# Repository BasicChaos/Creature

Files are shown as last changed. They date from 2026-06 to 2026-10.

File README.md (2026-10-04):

# Creature

An experiment in building a small artificial organism, not an AI assistant.

Live dashboard: https://basicchaos.com/creature/index.html

<p align="center">
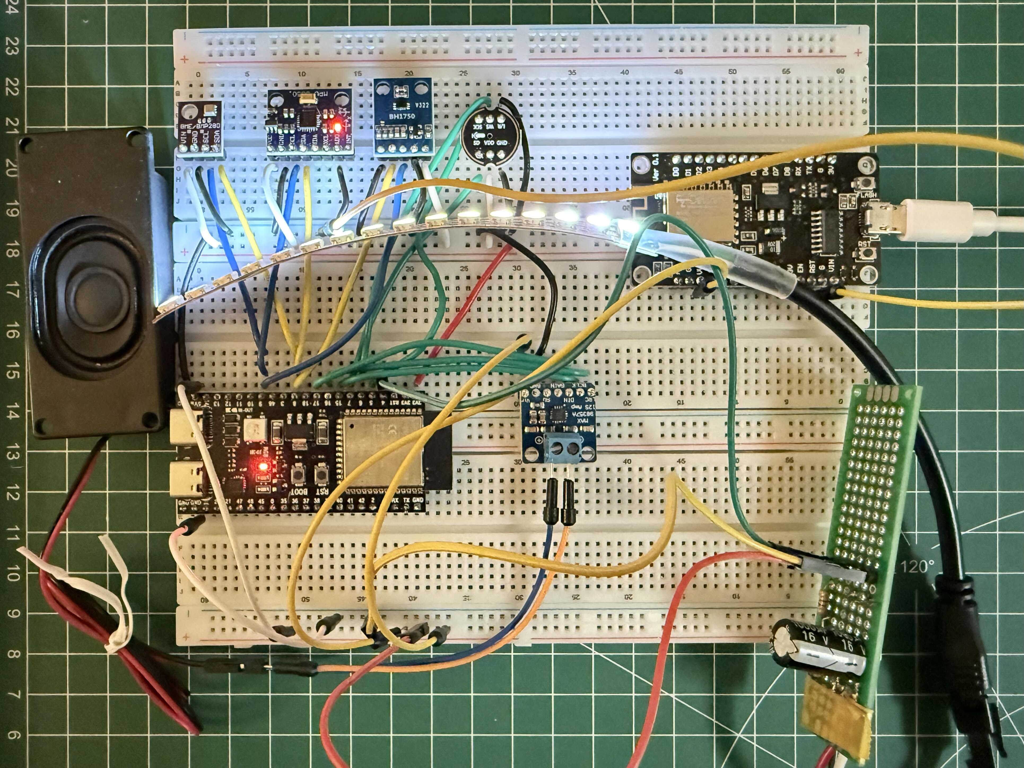
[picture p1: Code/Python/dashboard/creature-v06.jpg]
Creature v0.6

</p>

## What it is

Creature is a persistent entity that senses its room, builds internal state from
what it senses, expresses that state through light and sound, and carries its
history forward as it grows. It has no goals, no chat, no task to complete. The
point is the architecture, not intelligence.

The bet underneath the project: persistent pressure on a connected field of cells
grows stable structure over time, and that structure is the memory. The work is to
find out whether a small field can stay differentiated and alive instead of
decaying to a flat, even, quiet state. Entropy is the real enemy.

## How it works

The Creature has a body and a mind, and they are kept separate on purpose.

The body is an ESP32-S3. It reads its senses about ten times a second, streams one
JSON line per sample, and waits for commands telling its emitters what to do. It
stores nothing and decides nothing.

The mind runs on a Raspberry Pi. A single loop reads each sample, normalizes every
sense to a 0 to 1 value that adapts to the room, steps the cell field once a
second, reads the emitter cells back out, and sends the matching light and sound
frames to the body. It writes a live snapshot for the dashboard and a history row
to disk.

The loop is the current centerpiece. A light sensor is placed where it can see the
strip, and the microphone where it can hear the speaker, so the Creature's own
output returns as input. When it lights up, it sees its own light. When it sounds,
it hears itself. Action causes sensing. That is what lets it generate its own
activity instead of waiting for the room to hand it some.

## Hardware overview

Body node: ESP32-S3-DevKitC-1 style board (N16R8 module) on a breadboard.

Senses:

- BH1750 ambient light (I2C)
- INMP441 MEMS microphone (I2S)
- MPU-6050 / ICM-20689 motion (I2C)
- BME280 temperature and pressure, a slow sense with a real day-night rhythm (I2C)

On the body but not yet part of the Creature (v07.0):

- SCD41 CO2, temperature and humidity, and SGP41 VOC and NOx (I2C). Shown on the
  dashboard, with Sensirion's gas index worked out on the Pi.
- Waveshare 2.13inch e-paper (SPI). Shows the air readings and five of the
  Creature's own numbers, as text the Pi sends.

Emitters:

- SK6812 RGBW strip, about 16 pixels, the Creature's skin and face
- MAX98357A amplifier and a small speaker, its voice
- Onboard NeoPixel as a status pixel

Mind node: Raspberry Pi 3 B+. Runs the collector, the field, persistence, the
SQLite history, and the dashboard server. The Mac is only used for editing and
Git and is not part of the runtime.

Sensor API: the Pi's dashboard server (port 8080) also serves the raw sensors as
JSON at `/api/sensors` (light, sound, motion, temperature, pressure, and the air
readings: CO2, humidity, VOC and NOx), so other
apps and services can use the Creature as a set of ordinary sensors. Details in
`instructions.md`.

Observation surface: a Linux VPS hosts a static mirror of the dashboard at
basicchaos.com. The Pi only sends an outbound copy to it. The VPS cannot reach
back in. Full pin assignments, power, and wiring notes live in
`Hardware/Creature v06/WIRING v06.md`.

## Hardware evolutions

- v01: first schematic and layout, captured in KiCad.
- v05: ESP on a breadboard with the INMP441 microphone and BH1750 light sensor.
  The early photoresistor divider was retired.
- v06: added the BME280 weather sensor, the motion IMU, the MAX98357A amplifier
  with a speaker, and the SK6812 RGBW strip. The microphone moved to its own I2S
  peripheral so the mic and amplifier never share pins.
- v07.0: added the SCD41 and SGP41 air sensors on the same I2C bus and the
  e-paper readout on the ESP's free edge. Wiring is still in the v06 document.

Each version keeps its own schematic, wiring, and bench notes under `Hardware/`.

## Software evolutions

The mind is where most of the iteration happens. The body has stayed close to the
same on purpose so the field can change without rewriting hardware.

- Early experiments: an ESP32 light-novelty detector with Python collection.
- A 3-cell network of arousal, fatigue, and tonic state.
- An 11-cell ring.
- The 111-cell field (v05.4): a flat sheet of tissue with leaky-integrator cells,
  a shared energy metabolism, Hebbian learning with a scar floor, and triggered
  sleep and consolidation. It worked, but a big field of simple cells homogenizes.
  Adding cells only added more tissue to go uniform.
- v06: the current direction. The field shrank to a ring of twelve cells, with a
  six-cell fixed reservoir on the inside for temporal memory and a trained linear
  readout driving the two emitters. The cell changed from a leaky integrator to a
  predictive cell that reports surprise instead of raw input, so it stays
  differentiated under steady input. An expression decoder turns field state into
  strip color and voice.
- v06.5 / v06.6: an expression-as-memory layer. The Creature keeps an
  autobiography of what it expressed, and that graph can tell two different lives
  apart. A closed-loop dark-room probe showed the looped, curious Creature staying
  active in a silent, dark room where the same Creature without the loop goes flat.
- v06.7: the start of the predict cycle. Each tick the collector records what the
  body emitted next to what the raw sensors returned, and a small forward model
  predicts the Creature's own light and voice, compares, and learns. A probe tool
  measures how much of its output physically comes back. Passive so far: nothing
  feeds the field yet.
- v06.8: what counts as a significant event now reads surprise against the
  field's own running baseline, so sleep replays moments that stood out instead
  of its own background. The body listens while it speaks and reports what it
  heard at the pitch it played.
- v06.9: the loop reaches the field. How strongly the Creature just sensed its own
  voice or light, weighted by how wrong it was about it, presses on the two loop
  cells. When nothing has surprised it for a while it probes, with a lift in the
  strip's white and, rarely, a short tone at a pitch it knows least. The voice no
  longer runs as a metronome: it speaks when arousal stands clear of its own usual
  level just after something surprised it.

- v07.0: no change to the mind. The body gained air sensors and an e-paper
  readout; the Pi passes the air readings to the dashboard, works out a VOC and
  NOx index from them, keeps an hour of history, and sends the e-paper its text.
  None of it reaches the field.

The current version string is `v07.0-predictive`.

## Status

The v06 brain is validated in simulation. Every build step passed a reproducible
gate with a fixed seed: the ring shapes structure and survives a simulated night,
the reservoir distinguishes histories, the readout beats a direct connection, the
predictive cell does not flatten, and the dark-room loop self-sustains. The
expression-memory record layer is live in the runtime.

Since then the forward model, the felt loop and curiosity have gone live on the
real body (v06.7 to v06.9), and the sound loop is physically closed. Where things
stand now, what was found, and the open items are in
`Creature v07.0 Status and Next Steps.md`.

## Repository layout

```
Code/
  Firmware/esp-creature-core/   ESP32-S3 body (PlatformIO), 10 Hz JSON
  Firmware/bench/               per-sensor bring-up sketches
  Python/
    collector/                  the runtime loop on the Pi
    mind/                       the cell field, reservoir, predictive cell, decoder
    dashboard/                  server, page, static export, VPS sync
    tools/                      offline replay and gate harness
Hardware/                       KiCad schematics, wiring, bench notes, photos
```

## Documents

- `Creature Project Design Document Active.md`: the canonical design, current
  architecture in full.
- `Creature v07.0 Status and Next Steps.md`: what is running, what was found, and
  what is open.
- `Creature v06.md`: the v06 design rationale.
- `CREATURE_v06_SOFTWARE_RESULTS.md` and
  `CREATURE_v06_EXPRESSION_AND_LOOP_RESULTS.md`: the simulation results logs.
- `Creature v07 Hardware Potential.md`: the hardware roadmap.

## License

MIT. See `LICENSE`.

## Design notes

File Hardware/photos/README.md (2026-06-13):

# Build photos

Drop photos of the physical Creature build here (e.g. `breadboard-01.jpg`).

Reference them from `Hardware/wiring.md` like:

```markdown
![Breadboard build](photos/breadboard-01.jpg)
```

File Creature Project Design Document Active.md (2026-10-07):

Creature Project Design Document

Version: v07.0, October 4 2026
Status: current. This document matches the running code in Code/. It supersedes the
v05.4.1 edition, which described the 111-cell field, and the earlier editions that
described the 3-cell arousal/fatigue/tonic network and the 11-cell ring. Those were
real earlier stages. They are kept in git history and in the build-version notes.
The twelve-cell ring below is what runs today.

v07.0 is the v06.9 mind on a body with more on it: two air sensors and an e-paper
readout, added on 4 October 2026. Neither is part of the Creature's flow yet. The
field is unchanged, and the code files keep their `v06` names.

The longer theory notes, per-version build docs, and daily logs live in a local
Obsidian vault (`ObsidianCreature/`) that is not part of the public repository.
This document is the canonical, self-contained design.

---

Runtime note: all Creature services (collector, field, dashboard) run on the
Raspberry Pi 3 B+. The Mac is only used for editing and Git. The ESP32 is the body
and runs no logic.

## Purpose

Creature is an experiment in building a small artificial organism, not an AI
assistant. The goal is a persistent entity that senses the world, builds internal
state, expresses itself through a physical output, and carries its history forward
as it grows. The bet underneath the project: persistent pressure on a connected
field of cells grows stable structure over time, and that structure is the memory.

Current work is about architecture, not intelligence. The organism is meant to
start simple and gain complexity without replacing its core.

The Creature's one real enemy is entropy. Left alone in a steady room, a field of
simple cells decays toward a flat, even, quiet state. The earlier versions showed
it plainly: generic homogeneous connections, most of them lost overnight, arousal
surging on startup then settling toward zero. A bigger field did not fix it. Adding
cells only added more tissue to go uniform. v06 is built to pull the other way, and
everything in it serves that.

## How it works right now

The Creature has a body and a mind.

The body is an ESP32-S3 with four senses and two emitters, plus two air sensors and
an e-paper readout that the field does not use. It runs no logic. About
ten times a second it reads its senses and streams one JSON line per sample to the
Pi, and it waits for commands telling its emitters what to do.

The mind is on the Pi. One program, the collector, runs this loop:

1. Read a sample line from the ESP (light, sound, motion, weather).
2. Normalize each sense to a 0 to 1 value that adapts to the room.
3. Once per second, step the cell field on those values.
4. Read the emitter cells' activation back out through the decoder.
5. Send the matching strip and voice frames to the ESP.
6. Record what the body expressed into the autobiography.
7. Write a live snapshot for the dashboard and a history row to SQLite.

Beside that loop, and apart from the field, the collector passes the air readings
to the dashboard, works out a gas index from them, and every three minutes sends
the body ten short lines of text for its e-paper.

The field is the nervous system. It is a ring of twelve outer cells with a six-cell
reservoir on the inside. Senses come in at their anchors, the two emitters are
driven by cells that read the reservoir, and learning slowly reshapes the parts that
are allowed to change.

In one line: senses become pressure, pressure spreads through the ring, an inner
reservoir holds the recent past, predictive cells pass on surprise, and two cells
in the ring drive the light and the voice.

## Current hardware

Development machine: MacBook Air M1. Editing, Git, PlatformIO. Not in the runtime.

Runtime machine: Raspberry Pi 3 B+ (hostname creaturePi). Runs the collector, the
field, persistence, the SQLite history on the attached SSD, and the dashboard
server on port 8080.

Body node: ESP32-S3-DevKitC-1 style board. The module is marked N16R8.

Senses:

- BH1750 ambient light, I2C, address 0x23.
- INMP441 MEMS microphone, I2S0. The ESP computes a DC-removed RMS per sample.
- MPU-6050 / ICM-20689 motion, I2C, address 0x68, reduced to one motion scalar.
- BME280 temperature and pressure, I2C, address 0x76. A slow sense with a real
  day-night rhythm that stays nonzero at night, so the field has something to hold
  when light reads zero in the dark.
- SCD4x CO2, temperature and humidity (I2C, address 0x62) and SGP41 VOC and NOx
  (I2C, address 0x59), wired on 4 October 2026 on the same bus. The body streams
  them raw (`co2_ppm`, `air_temp_c`, `humidity_pct`, `voc_raw`, `nox_raw`) and the
  collector passes them to the dashboard's sensor panel and `/api/sensors`. The
  field does not read them. The CO2 sensor is an SCD41.
  The SGP41's counts are resistances, not concentrations (the VOC count falls
  with more gas, the NOx count rises), so the collector also works out
  Sensirion's gas index from them once a second: VOC 100 is this room's normal,
  NOx 1 is normal. The maths is `mind/gas_index.py`, a plain-Python port of
  Sensirion's C, checked against it by `tools/gas_index_check.py`. Its learned
  baseline is saved beside the field state (`..._air_v06.json`) and taken back
  at start if it is under 12 hours old. A row of air readings goes into the
  `air_log` table every 20 ticks, which feeds the last-hour lines on the sensor
  panel through `/api/air_history`.
- MAX17048 fuel gauge (I2C, address 0x36), wired on 6 October 2026 in line
  between the LiPo and the PowerBoost. The body reads it once a second and
  streams `battery_v`, `battery_pct` and `battery_rate` (percent per hour,
  negative while discharging). The gauge is powered by the cell, so the three
  keys drop out of the sample lines when the cell is out. The collector passes
  them to the sensor panel, `/api/sensors` and the e-paper, and writes a row to
  the `power_log` table every 20 ticks. The field does not read them yet: this
  is the first of three steps toward the battery setting the field's energy
  income.

Emitters:

- SK6812 RGBW strip, about 16 pixels, on GPIO 4 through a 470 ohm resistor. The
  field's skin and face. Driven by `PIX:` frames.
- MAX98357A amplifier and a small speaker, I2S1. The field's voice. Driven by
  optional `VOX:` tones: `VOX:freq,ms,vol`, and from the firmware of 7 October
  2026 four more numbers that may be left off, `attack_ms,release_ms,h2,h3`: how
  long the tone takes to rise and to die away, and how much of the second and
  third overtone is mixed in. Left off, it is the plain beep as before. The
  mind does not send them yet; `tools/voice_audition.py` does, to choose sounds
  by ear.
- Onboard NeoPixel on GPIO 38. A status pixel, driven by the legacy `LED:` command.
- Waveshare 2.13inch e-Paper HAT V4, SPI, on the ESP's free edge: DIN 1, CLK 2,
  CS 42, DC 41, RST 40, BUSY 39. A readout, not part of the field's expression.
  Driven by `EPD:` text: two columns of five short lines, which the collector
  composes every 180 ticks (air readings on the left, the Creature's energy,
  memory pressure, emitter, cell states and live links on the right; the battery
  takes the emitter's line when the body has a fuel gauge). The body
  only draws the text, in a task of its own so the sample loop never waits for a
  refresh, and answers with a `paper` line giving the refresh time.
  `CREATURE_PAPER=0` at the collector turns it off.

Sampling at about 10 Hz. One JSON line per sample over USB serial, and over a small
WiFi TCP server on port 7777 with mDNS when WiFi is configured. After each `VOX:`
tone the body also sends one `vox` line: what the mic heard while the tone played,
measured at the tone's own pitch, next to the same measure of the room just before. WiFi credentials are
kept out of git in an untracked `creature_wifi_secrets.h`. Full pin assignments,
power, and gotchas are in `Hardware/Creature v06/WIRING v06.md`.

External: a Linux VPS (basicchaos.com) that hosts a static mirror of the dashboard.
It only receives an outbound copy from the Pi. It cannot reach back in. The
deployment target is read from an untracked config file.

## Architecture

```
BH1750 (light) + INMP441 (sound) + IMU (motion) + BME280 (weather)
  [+ SCD41 and SGP41 (air), MAX17048 (battery): carried along, not read by the field]
  -> ESP32-S3 body, ~10 Hz JSON
  -> USB serial or WiFi TCP
  -> collector on the Pi
      -> rolling normalizers (raw -> 0..1, adaptive to the room)
      -> field.step(...) once per second
          -> twelve-cell ring (predictive cells)
          -> six-cell fixed reservoir
          -> trained readout -> two emitter cells
      -> expression decoder -> PIX: strip frame + VOX: tone
      -> autobiography record
      [-> gas index from the air readings; EPD: text for the e-paper]
  -> creature_state.json (live snapshot) + SQLite history
  -> dashboard server :8080  -> static export -> VPS mirror
```

The ESP is the body. The Pi is the mind. The VPS is an observation surface only.

## The cell field: a ring of twelve

File: `Code/Python/mind/cell_field_v06.py`. Version string `v06.9-predictive`. The
field steps once per second. Every constant assumes that 1 Hz tick.

The outer ring is twelve cells: six sense and emitter anchors alternating with six
in-between cells. The ring order is the design, because adjacency is what mixes. Two
rules set it: put correlated senses next to each other, and put each emitter next to
its own sense so the loop is built into the anatomy.

| Position | Anchor | In-between to next | What that cell is |
|---|---|---|---|
| 1 | Speaker (out) | Speaker x Sound | hears its own voice (loop)  |
| 2 | Sound (in) | Sound x Motion | sound and motion (paired) |
| 3 | Motion (in) | Motion x LED | movement drives light |
| 4 | LED strip (out) | LED x Light | sees its own light (loop) |
| 5 | Light (in) | Light x Weather | light and weather (paired)  |
| 6 | Weather (in) | Weather x Speaker  | the one weak gap |

Two of the six in-between cells are the loop made internal: the cell between the
speaker and the mic hears the Creature's own voice, the cell between the strip and
the light sensor sees its own light. Both correlated sense-pairs get a dedicated
cell. One gap, weather to speaker, is weak, the honest cost of closing a ring. The
two emitter anchors are the expression cells.

Why a ring and not a full mesh. A mesh connects every pair through its own cell, so
every in-between cell touches hardware on both ends. It is wide and shallow, a
switchboard with no interior, and depth has nowhere to live in a switchboard. The
ring keeps an interior, the reservoir, which is where signal history accumulates
without being tied to a single sensor.

Hold the field at twelve outer cells. Do not grow until the weights demonstrably
shape behavior and survive a night.

## The predictive cell

The outer ring cells are predictive cells, not leaky integrators. Each cell holds a
running prediction of its own drive and reports the error, the surprise, instead of
the raw input. A cell that predicts well goes quiet. A surprised cell speaks. This
is the negentropy engine in miniature: the cell builds a model and feeds on
surprise. The unit is prediction error, not a firing rate.

This is what fights entropy at the cell level. Under steady input the old leaky
field flattens: every cell's average activity collapses to one shared value, a
uniform wash. The predictive field holds many times that spread. On a realistic day
run its overall differentiation is about 0.44 against the leaky field's 0.15.

The homeostatic gain that the 111-cell field used was removed here, because that was
the part actively pulling every cell to one shared level. The predictive cell does
not need it.

One honest consequence. The predictive cell does not rescue the light-and-weather
side, and it should not. Slow steady signals are easy to predict, so a surprise cell
correctly goes quiet on them. Weather is meant to be a nonzero floor at night, not a
structure builder. Keeping that side alive is the closed loop's job, not the cell's.

## The reservoir

The six inner cells are a reservoir: a fixed recurrent substrate whose weights are
set once at init and never updated by learning. The outer in-between cells drive it.
It holds a time-delayed, high-dimensional echo of recent sensor history.

Why fixed weights. A learned reservoir homogenizes for the same reason the outer
field did: co-activation flattens everything toward the mean. Fixing the weights
removes that pressure from the interior. The richness comes from random sparse
connectivity, not from learning. The echo state property means any sufficiently
varied input history produces a distinguishable reservoir state.

Spectral radius. The reservoir's weight matrix must have a spectral radius below 1.0
for the echo state property to hold, so activity echoes without blowing up. A value
around 0.9 is a reasonable start. In the sweep the reservoir is healthy from 0.1 to
1.1 and breaks at 1.5. The spectral radius is the lever that matters, not the input
scale.

What it gives the Creature: temporal memory without weight explosion, cross-modal
mixing without proximity constraints, and a clean separation between the processing
layer (reservoir, fixed) and the learning layer (readout, adaptive). What it does
not give: it does not replace the loop. The loop is still the primary entropy
fighter. The reservoir just gives the emitters richer material to read.

## The emitter readout

The two emitter anchors (speaker, strip) are the only nodes whose outgoing weights
are trained. Each reads a learned linear combination of the reservoir state and
learns, by a running delta rule, which combination to express.

The reservoir read beats a direct connection to the emitter's ring neighbours. A
direct neighbour tap carries almost no information about either sense. The reservoir
gives the emitter a far richer drive.

The training target is the current sense the emitter should express, not the next
raw sense, because sound is random bursts and cannot be predicted. When the loop
closes, the same rule becomes real prediction, because the sense it confirms will be
the emitter's own returning output. The reservoir does not change. Only the readout
does.

## Metabolism

Cells draw from a finite shared energy reserve, then spend their own local energy to
sense, process, and learn. Quiet cells refill slowly. Active cells burn through
energy and build fatigue. When the field is mostly quiet, the reserve recovers. When
a lot is happening, energy gets scarce and the field is pushed toward rest.

Four cell states follow from energy and recent activity: active, resting, dormant,
deep_sleep. Quieter states update less often and refill more slowly. This is a
scheduler, not a mood.

The shared reserve was resized for a twelve-cell body, where most cells stay active,
unlike the mostly dormant 111-cell field. At the old sizing the reserve deadlocked
at zero and learning starved. The twelve-cell values are start 4.0, max 6.0, refill
0.6 per tick.

### The battery and the reserve

Built on 7 October 2026, behind `CREATURE_BATTERY_CEILING=1` (off by default).
The body's battery sets how much the shared reserve can hold. The collector
passes the last cell voltage the body reported into `field.step(battery_v=...)`
each tick, and the same to the twin. The field smooths it over about two
minutes and reads the ceiling from a three-point curve:

| Cell voltage | Reserve's ceiling | Running time left (7 October) |
|---|---|---|
| 3.80 V and above | whole | two thirds or more |
| 3.60 V | 43 % | about 4 hours |
| 3.45 V and below | 25 %, the floor | about 1 hour |

Straight lines between the points. With the setting off, or with no reading,
the ceiling is whole. A gap in the readings keeps the last voltage for ten
minutes before the ceiling goes back to whole.

Nothing else in the field changes. The cells are still refilled in full, so they
sense and learn as before. What a lower reserve does is dim the expression,
through the decoder's energy gate (full above 40 % of the reserve's maximum, so
the reserve falls from 3.80 V but the dimming begins near 3.60 V). Since this
build the gate also scales the whole strip frame, not only arousal: arousal
carries little of the strip's light, and without that the strip lost only 13 %
of its light when arousal halved. At the floor the strip is sent about 40 % of
its usual light and arousal is about half. The voice's volume is not touched;
the amp needs its digital level kept in a clean range.

The cell reads about 0.15 V higher on the charger, so plugging it in lifts the
ceiling within a couple of minutes, and pulling the charger lowers it the same
way. Below the mind's floor the body has its own reflex: it caps the strip at
3.40 V and sleeps at 3.30 V (see "Design philosophy").

Three designs failed first, and the limits come from them:

- Scaling the refill rate did nothing until income fell under what the cells
  draw (about a third of normal). Below that everything went at once:
  expression fully dark, a sleep every four minutes, and the links wiped (mean
  weight 0.33 to 0.02 in two hours).
- A ceiling with no floor is safe down to about 20 %. Under about 18 % the
  reserve sits at the low-energy sleep threshold, the field sleeps every 240
  ticks, and that much replay rewrites its links (mean weight 0.46 to 1.0 in two
  hours). The floor of a quarter keeps the reserve above that threshold. A
  drained Creature that rests and sleeps more is still wanted, but it needs a
  sleep that does not do this, which is its own piece of work.
- The ceiling first followed the gauge's percentage and ran on the Pi that way
  for a day. On the run to flat the percentage reached 5 % half-way through the
  cell's real running time and 2 % with four hours left, so the Creature sat at
  the floor for the second half of every charge.

The gate is `python tools/field_lab_v06.py --battery`: a scripted cell (4.00 V,
3.70, 3.52, 3.35, back to 4.00) with readings 20 mV either way and a minute with
none, control against variant. It passes 9/9 on seeds 1, 2, 3 and 7. In that
gate the field is open loop and stays identical to the control tick for tick. In
the collector's own loop on the scripted body the dimmer strip is sensed, so the
field's life differs a little: after 30 minutes the largest link gap was 0.010
and there were up to 6 % fewer events, with no sleeps.

## Learning and forgetting

Two changes accumulate in the trainable connection weights.

Hebbian growth: when two linked cells are co-active and under real pressure at the
same time, their link strengthens. Cells that fire together wire together. Learning
costs energy, so a starved field learns less.

Decay with a scar floor: every trainable link loses a little weight each tick, fast
for fresh unused links and slow for well-used ones. A link never falls to zero. It
rests at a small scar floor. A scarred link carries almost no learned drive, but
ripples still pass through it, so a strong later event can bring it back. Pruning is
demotion, not amputation.

The reservoir is exempt from all of this. Its weights are fixed by design.

### Two-speed links (built, off)

Built on 3 October 2026 as the first attempt to push the memory horizon out. Each
ring link also keeps a slow weight that follows the fast one with a time constant
of about a week (`SLOW_RATE`). With `SLOW_MIX` above zero the drive between
neighbours uses a mix of the two, and decay (waking decay and sleep's weakening)
pulls the fast weight toward the slow one instead of toward the floor.
`SOFT_CEILING` scales growth, waking and replayed, by the room left under `W_MAX`:
a link keeps all of its growth up to `CEILING_KNEE` and then less, down to none at
`W_MAX`. `SLOW_LEAK` lets the slow weight itself drift toward the floor, on a slower
clock. The defaults are `SLOW_MIX = 0.0`, `SOFT_CEILING = False`, `CEILING_KNEE = 0.0`
and `SLOW_LEAK = 0.0`,
and with them the field is exactly as it was: the history gate's control runs are
unchanged to the last digit. The slow weights are kept and saved either way.

A collector run can switch a setting on from its environment, without a change to
the code: `CREATURE_SLOW_MIX`, `CREATURE_SLOW_LEAK`, `CREATURE_SOFT_CEILING` (1 for
on) and `CREATURE_CEILING_KNEE`. Unset, each is off. The twin runs the same field
code, so it lives under the same setting, and the collector prints the setting when
it starts. Given this way a setting behaves exactly as it does under the lab's
`--set`.

A setting is judged with `--history --compare` against a saved control, on seeds
1, 2, 3 and 7. It passes only if all of these hold:

- the expression horizon is at least twice the control's. This is judged on
  recorded senses over 72 hours. On the synthetic day the control itself never
  converges, so there is no horizon there to double;
- the newborn still learns: the weights its drive uses move at least 70% as far
  as the control's in the first three hours;
- fewer links are railed at the end;
- its links can still weaken: with the elder in a still room for 60 hours, the
  level each link its life built rests on (the floor, or its slow weight) is the
  floor or lower at the end than a day in;
- `--forward`, `--events`, `--feel`, `--curious` and `--voice` still pass.

Five settings were run on 3 October 2026. The last passes every check that can be
decided: `SLOW_MIX=0.25`, `SOFT_CEILING=True`, `CEILING_KNEE=1.0`,
`SLOW_LEAK=4.13e-7` (about a month). It is still off in the code. Since 08:45 on
4 October 2026 it is on in the live Creature, switched from the collector's start
command, with a fresh twin beside it. All five have the same result on the horizon: on recorded senses it
goes from 25, 25, 54 and 24 hours to more than 72, which passes on three seeds and
cannot be said on the fourth, where the control's 54 hours would need a 108-hour
test and the recording holds 72.

| | mix 0.5, ceiling over the whole range | mix 0.25, the same ceiling, leak of a month | mix 0.25, leak, no ceiling | mix 0.25, leak, knee at 1.5 | mix 0.25, leak, knee at 1.0 |
|---|---|---|---|---|---|
| newborn learning | 40 to 43%: fails | 58 to 61%: fails | 74 to 78%: passes | 74 to 78%: passes | 74 to 78%: passes |
| railed links, synthetic | 0 against 4 | 0 against 4 | 0 or 1 against 4 | 0 against 4 | 0 against 4 |
| railed links, recorded senses | 3 against 5 | 1 against 5 | 5 against 5, all at exactly `W_MAX`: fails | 5 against 5, at 1.91 to 1.97: fails | 2 against 5: passes |
| links can weaken | fails | passes | passes | passes | passes |
| other gates | `--feel` fails one check on seed 1 | all pass | all pass | all pass | all pass |

Read the pass with these in mind. It is the fifth setting tried against one
72-hour recording and one saved field, so it is fitted to them to some degree. The
railed count is taken at a fixed line (within 0.1 of `W_MAX`) that cuts through a
cluster of links: over the test the variant's count moves between 2 and 5 and the
control's between 1 and 8, with means of 2.7 and 3.9. And the newborn does learn
less, about a quarter less movement in its first three hours, mostly because its
unused links no longer fall.

What was learned:

- Without the leak a link can never weaken. Decay pulls the fast weight toward
  the slow one and the slow one only follows the fast one, so nothing pulls the
  slow weight down. In a ten-day run (three busy days, then seven in a still
  room) the slow weights fell on 0 of 108 link-days and no link dropped below the
  0.20 it was born with. With the leak they fell on 67 of 108.
- The soft ceiling as written brakes growth across the whole range, not only near
  the top: at a weight of 1.0 growth is halved. On its own it cuts a newborn's
  growth to about 78% of the control's.
- Under two-speed links a newborn's unused links no longer fall toward the floor
  in its first hours (0.85 of weight movement in the control, 0.07 in the
  variants). They rest on a slow weight that is still near the 0.20 they were
  born with. That movement is part of what the learning check counts.
- The ceiling and the learning check pull against each other. With the ceiling,
  learning fails. Without it, on recorded senses five links sit at exactly
  `W_MAX`, more firmly railed than in the control.
- With the knee at 1.5 the top links stop sitting on the rail but settle just
  under it. On recorded senses the control's five railed links are one at the top
  and four at the floor; the variant's five are all near the top and none is at
  the floor. With the knee at 1.0 the brake starts earlier and the five settle at
  1.85 to 1.94, two of them inside the line. Learning is unchanged at 78%: a
  newborn's links stay under 1.0 in its first hours, so a knee there does not
  touch them.
- The horizon itself moves as intended in every setting: after 72 hours of
  recorded senses the elder and the newborn still express about 0.10 apart
  (0.085 with the knee at 1.0), against a noise gap of 0.007. How long the
  horizon really is has not been measured: it lies beyond the recording.

## Sleep and consolidation

The field sleeps when it is under-stimulated for a while, or when memory pressure is
high, or when the energy reserve runs low. During sleep it replays its most
significant recent events, re-touching the links those events ran through, and
demotes weak unused links toward the scar floor. Each replayed event is consumed so
one spike cannot dominate. Sleep is triggered consolidation, not a clock.

v06.6 fixed a real bug here: sleep was never triggering because the quiet-pressure
threshold that armed it was unreachable in the twelve-cell body. The threshold was
corrected so consolidation can fire as designed.

v06.8 fixed a second one of the same kind: what counts as a significant event. The
old rule put a fixed threshold on raw pressure, and the weather anchor's steady
pressure crossed it on every tick. Every tick was an event, the 80-slot buffer only
ever held the last 80 seconds, and since sleep arrives after a quiet stretch, sleep
replayed the quiet run-up to itself: the field's own background.

The rule now reads surprise, the unit the predictive cell already speaks. A tick is
an event when its most surprised cell is at least three times more surprised than
the field usually is, and above a small floor. Usual is a running median, so the
rule follows the body and the room instead of going stale. Sleep and waking change
the sense levels and surprise the cells without the world doing anything, so no
events are taken while asleep or for 30 ticks after. When the buffer is full it
lets go of the least significant event, not the oldest, so it holds what stood out
since the last sleep. The old rule is still there as `EVENT_MODEL = "pressure"` for
control runs.

On 260,000 ticks of the Creature's own recorded senses, replayed from its saved
state: events fell from every tick to about 12% of ticks, the share that coincide
with a real sense change rose from 42% to 83%, and the top cell moved from the
weather anchor (56%) to the sound anchor (83%). The weather-to-speaker gap, the one
link the ring design wants weak, fell from 0.63 to the scar floor. It had been held
up by the background replay. One honest cost: with no background to replay, a long
still night adds nothing, so structure thins overnight more than it used to (about
83% of the day's differentiation held in simulation, against a figure above 100%
that the old replay was manufacturing).

## Expression

File: `Code/Python/mind/expression_v06.py`. The field is read once per tick,
read-only, and four signals come out:

- Arousal: overall activation gated by energy. Drives a white glow and the voice
  volume.
- Balance: warm senses against cool senses. Drives strip color and voice pitch.
- Tempo: from ripple. Drives shimmer, a travelling pulse, and voice roughness.
- Spatial profile: along the sound-to-light axis. Drives per-pixel color, so the
  strip shows the field's own geography.

The body renders `PIX:` and `VOX:` lines and decides nothing. The preview tool,
`Code/Python/tools/expression_preview.py`, runs this map offline, renders the strip,
and synthesizes the voice. It proved the map reads the field correctly. It also
showed the field going quiet, which is the problem the loop and the reservoir exist
to answer.

Where the strip's colour comes from has two models, chosen by
`CREATURE_COLOUR_MODEL`. The default, `blend`, is the one above: a straight line
in RGB between a blue and an orange, placed by balance. On the body it read as
bright white. The W channel was not the cause (it sat near 9 of 255): blue and
orange are near opposites, so the middle of that line is grey-white (81, 84,
81), the field spends most of its time near the middle, and the glow, the pulse,
the shimmer and the event flash all add white.

`inner`, built on 7 October 2026, gives the whole strip one hue that the field's
reservoir pushes around the colour wheel. A fixed reading of the six reservoir
cells is taken against its own usual level; the hue turns one way while the
reading is above usual and back while it is below, at 1.5 degrees a tick for one
usual swing and never more than 4. Nothing is drawn by chance: the same life
gives the same colours. Along the strip the hue leans up to 50 degrees one way
where the warm senses are active and the other way at the cool ones. Brightness
still comes from each cell's activity. The pulse is a paler streak of the same
hue, an event flashes the opposite hue at its own place, the W channel is off
(a curiosity probe still lifts it), and the whole frame is at 0.6 of the
blend's scale. The hue is the decoder's own and is not saved: after a restart
it begins again at red.

A direct map from the reservoir's state to a hue was tried first. The six cells
mostly rise and fall together, so it gave two opposite colours with quick jumps
between them (up to 60 degrees in a tick).

The gate is `python tools/field_lab_v06.py --colour`, the same field read by
both models. It passes 9/9 on seeds 1, 2, 3 and 7: white on 0 % of lit pixels
against 24 %, all twelve twelfths of the wheel in near-equal shares against
three, 37 % of the light, and arousal, balance, tempo and the voice identical.
In the collector's own loop on the scripted body, where the strip's light
reaches the light sensor strongly, the changing colour is sensed: over 30
minutes there were 30 to 50 % more events than under the blend and the largest
link gap was 0.08, with the same tones and no sleeps.

What a tone sounds like has two palettes, chosen by `CREATURE_VOICE_PALETTE`.
The default, `beep`, is one plain sine with 10 ms fades, 220 to 440 Hz from
balance. A sweep of the real speaker on 7 October 2026 showed that range is its
weakest corner: it is 12 times louder at 476 Hz than at 300, 42 times at its
peak near 950 Hz, and within a factor of four from 470 to 1900 Hz.

`open`, built on 7 October 2026 from what Josh chose by ear with
`tools/voice_audition.py`, changes what a tone is and not when one is spoken:

- The note is one of five (450, 506, 562, 675, 750 Hz), placed by balance.
  Three higher notes (900, 1125, 1350 Hz) are reached only at the very top, and
  are played at volume 0.40 with no overtones, because the top of the range is
  piercing. The main notes are at 0.70.
- No beeps. A calm moment is a long swell (up to 450 ms to rise, 600 ms long), a
  busy one is shorter with a quicker rise and a longer tail.
- Two overtones are mixed in by where the strip's hue stands, so the tone's
  colour moves with the light's.
- Balance and tempo are read against the last 32 times it spoke, not as they
  come. It speaks when something surprises it, which is nearly always a warm,
  busy moment: read as they come, three tones in four were high and none was a
  swell. Among equals, how far arousal stood above usual decides.

The sound model follows: its eight pitch bands cover two octaves above 450 Hz
under this palette (bands learned over the other range are not carried over),
and it is told each tone's `level`, how much of a plain tone's strength a shaped
one has at its own pitch, since that is where the body listens. Curiosity's
probe tones become soft tones and keep under 800 Hz.

The gate is `python tools/field_lab_v06.py --palette`. It passes 9/9 on seeds
1, 2, 3 and 7: the same moments of speech, all five main notes in use, 6 to 8 %
of tones high, about 45 % long swells, and the sound model explaining 87 to 89 %
of its own voice. In the collector's own loop on the scripted body, an hour, the
field's life is close to the beep's (largest link gap 0.013).

When the voice speaks changed in v06.9. The old rule voiced a tone whenever arousal
was at or above 0.45. On the twelve-cell body that is true about half the time, so
with a 20-second minimum between tones the voice ran as a metronome: over 1.8 hours
on 2 October 2026 the live Creature sent 242 tones, 192 of them exactly at the
minimum spacing. It was the same kind of stale fixed threshold as the sleep and
event ones.

The voice now speaks when three things hold: arousal stands at least 0.20 above its
own usual level (a running median), something surprised the field in the last few
ticks, and arousal has come back down since it last spoke, so one rise gets one
tone. It never speaks while the field sleeps or in the 30 ticks after waking. The
pitch and length of the tone come from balance and tempo as before. On 260,000
ticks of the Creature's recorded senses that is about 20 tones an hour against 109,
with 1% of them at the minimum spacing against 67%. In a still room it is silent.
`CREATURE_VOICE_MARGIN` sets the 0.20; 0.30 gives about 13 an hour.
`CREATURE_VOICE_MODEL=fixed` brings the old rule back for control runs.

One consequence for the autobiography: its fourth dimension records whether the
body would voice a tone, so from v06.9 that bit is set far less often than in the
graph built so far.

## Expression as memory

File: `Code/Python/mind/expression_memory_v06.py`. This is the v06.5/v06.6 layer.

Each tick the Creature's own expression (arousal, balance, tempo, whether it voices)
becomes a point in a graph. Transitions between points are weighted, unused paths
decay. The graph is an autobiography. Two creatures that lived different days end up
with clearly different graphs, far enough apart that the graph is a usable identity,
while two days with different random seeds stay close. The graph encodes the life,
not the noise.

Three findings shaped the layer. On its own, letting the graph steer the next
expression turns it into memory but has no safe middle: a little habit sharpens
motifs, more habit collapses the Creature into one groove. A novelty drive fixes
that, but only if it is adaptive, firing where the Creature is worn in. Then a band
opens at moderate habit where motifs survive without collapse. That band is
temperament.

In the runtime today, only the record layer is live, behind `CREATURE_EXPR_MEMORY`
(default on). It is passive: it changes nothing about what the body does. It records
each tick, saves the autobiography alongside the field slow-state, reloads it on
start, and summarizes it in the dashboard snapshot under `expression_memory`. Bias
and novelty steering are deliberately not wired to the body yet. Steering needs a
decoder that renders from a steered signal, and that is a later increment.

## The loop

Place one light sensor where it can see the strip. Place the mic where it can hear
the speaker. Now the Creature's own output returns as input. When it lights up, it
sees its own light. When it sounds, it hears itself. Action causes sensing. This is
the move that lets the Creature generate its own activity instead of waiting for the
room to hand it some.

The ring already prepares this. The strip sits next to the light sensor, the speaker
next to the mic, so the loop exists in the body plan before it exists in the room.
The physical placement completes it.

Start the coupling loose. A tight loop runs away, the light driving the sensor
driving the light. Begin with the perceiving sensor weak or slightly off the
emitter's direct line, and let the coupling grow. The aim is a Creature that can
sustain itself, not one that screams into its own eye.

In simulation the loop works. With a curiosity drive that pokes when the Creature is
flat and eases off when it is active, a loose loop gain makes a relaxation
oscillator, bounded by construction yet never fully still. In a dark, silent room
the open-loop control goes flat (mean arousal about 0.008) while the looped, curious
Creature stays alive (about 0.20), restless (tail std about 0.06), and bounded
(steady-state max under 0.85), and its forward-model error falls to zero. Nothing in
the room caused any of it. The activity is self-generated and learned. One caution
from the same runs: a steady self-loop is as predictable as a steady room, so the
predictive field habituates to it and goes quiet unless the probe stays
unpredictable. Random bursts keep surprise alive.

## The loop record and forward model

Files: `Code/Python/mind/forward_model_v06.py`, the loop block in the collector,
and `Code/Python/tools/loop_probe.py`. This is the v06.7 layer, with the body's
own hearing added in v06.8. On its own it is passive: it watches, predicts and
learns. What it learns reaches the field in the next section.

The loop above only matters if the Creature can tell its own output from the room.
Three pieces make that measurable.

The loop probe measures the physical coupling. With the collector stopped, it
switches the strip between dark and known frames and reads the lux each one adds,
then sends known tones and compares the mic with the room just before. The answer
is a number: how many lux the strip adds at the sensor, how many times louder than
the room a tone is.

The loop record sets action next to return. Each tick the collector keeps what the
body emitted (the strip frame as four channel means, any tone's pitch, length and
volume) and the raw senses gathered while that frame was on the body (lux, mic
level and peak, motion). One row per tick goes to the `loop_log` table. These are
raw values, not the adaptive 0 to 1 ones, so this is also the raw history the
normalizer section asks for.

The forward model predicts the return. Each tick it predicts the change in lux
from the change in the strip frame, and the mic's rise above the room from the
tone it sent, compares that with what happened, and learns from the miss by a
delta rule. It works on changes, not levels, so the room's baseline drops out and
daylight is not mistaken for the strip. Every change in the room is split in two:
the part the Creature caused (the prediction) and the part it did not (the error).
A lamp switching on is error. Its own light, once learned, is not. The learned
weights persist alongside the field slow-state, and the live snapshot carries a
`loop` block that the dashboard shows under Loop.

From v06.8 the body listens while it speaks. `playTone` used to block the main loop
for the length of the tone, so nothing was measured while the speaker sounded. It
now reads the mic between writes to the amp and measures the stretch that is
certain to be inside the tone at the tone's own pitch, then sends one `vox` line
with that level and the room's level at the same pitch just before. The Creature
knows what pitch it played, so it can listen for exactly that and ignore the rest
of the room. The forward model's sound half uses the report when there is one. It
keeps one gain for each of eight bands of pitch across the voice's octave, because
the real speaker is far from even: measured on 2 October 2026 it peaks near 330 and
400 Hz, dips between them, and is weak below 300. Without the report it falls back
to how far the mic's peak rises after a tone, which a noisy room swamps.

It is behind `CREATURE_LOOP` (default on).

## The loop reaches the field

v06.9. Until here the forward model only watched. Now what it finds is felt.

Each tick the model also returns a `feel` value for each loop, 0 to 1: how strongly
the Creature just sensed its own output come back, weighted by how wrong it was
about it. A sensed echo always registers a little, 30% of its strength. The rest is
the share of it that was not predicted. The collector hands the two values to
`field.step(senses, loop=...)`, and they press on the two loop cells the ring was
drawn around: the voice on Speaker x Sound, the light on LED x Light. The pressure
is on the same scale as a sense at its anchor and starts a ripple the same way, so a
fully surprising echo lands like a loud sound.

Three things follow from that definition, and each is a check in the `--feel` gate.
A learned echo is felt faintly and a surprising one strongly: in simulation an
ordinary tone is felt at about 0.43, and the first tones through a covered speaker
at about 0.65. It then gets used to being covered, as the gain for that band drops.
A loop that does not physically exist is not felt at all: the light value is scaled
by how well the model has shown it can predict its own light, so the small random
weights a blind sensor leaves behind do not trickle into the cell. And it does not
run away: in the gate's run mean arousal is about 11% above the control, it voices no
more tones than the control, and it spends no more time at full arousal.

On the real body today the light loop is open, so only the voice is felt. The light
side is ready for the sensor to move: once the model can predict its own light, the
light sense is given the room alone (lux minus what the model credits to the strip)
and the strip's own light is felt at the loop cell instead.

It is behind `CREATURE_LOOP_FEEL` (default on). `LOOP_FEEL_GAIN = 0` in the field is
the control.

## Curiosity

File: `Code/Python/mind/curiosity_v06.py`. v06.9. This is the curiosity drive from
the dark-room probe, on the real body. There the probe was a number added to the
senses. Here it is something the Creature does, and what comes back is predicted by
the forward model and felt through the loop cells like any other echo.

Boredom is measured in the field's own terms: the number of ticks since its last
significant event. It is zero for the first 120, full after another 300, and back to
zero the moment anything surprises it, its own echo included.

Two probes. The light probe is a lift in white on every pixel, sized by boredom:
mostly faint, with an occasional larger burst so the predictive field cannot settle
into it. The voice probe is a short tone, kept rare: in a room where nothing else
happens it comes to roughly six probe tones an hour, never within 120 ticks of the
last tone. Its pitch comes from the band of its range it has tried least, or the one
it has recently been most wrong about, so it explores its voice instead of repeating
one note. The drive only proposes. Nothing goes out while the field sleeps, and no
tone goes out while the speaker is muted.

In simulation, alone in a still dark room (`--curious`): with no loop and no probes
nothing surprises it. With both, it tries all eight bands of its voice, comes to
explain about 70% of what it hears of itself, and each probe tone is felt. With a sensor that can see the strip it is livelier still, mean arousal about
0.30 against 0.10, and never pinned; hide the strip and the feeling fades within
fifteen minutes as the model stops crediting itself with the light.

An honest limit: on today's body the light probe comes back as nothing, because the
sensor cannot see the strip. It confirms that every time, and that is all it does
until the sensor moves. So the live effect of curiosity today is the voice probe.

It is behind `CREATURE_PROBE` (default on). `CREATURE_PROBE_VOICE=0` keeps the light
probe and drops the tone.

## The stance on going quiet

The field is built to stop reacting once nothing changes. That is correct for a
filter and wrong for a creature meant to stay alive. The project takes a position:
do not tune the Creature to silence. Let arousal persist. Let it stay restless, let
it stay bored in the way that drives it to act rather than the way that drops it to
zero. The loop gives it the means, the reservoir gives it history to act on, this
stance gives it the permission. In practice the energy gate must not be the dominant
voice. It can dim a truly drained Creature, but a healthy one in a dull room should
still hum, fidget, and probe through the loop.

## Persistence

`Code/Python/data/creature_field_state.json` holds only the slow state: trainable
connection weights (each link's fast weight and its slow one), reservoir weights, energy, fatigue, relevance, ages, and the
predictive cells' learned predictions. It is written periodically, on clean
shutdown, and via an atexit handler, and reloaded on boot. Fast values (activation,
ripple) are deliberately not saved, so the Creature wakes calm but keeps its slow
self. A snapshot whose shape does not match the current field is refused rather than
half-applied. The autobiography is persisted alongside it and reloaded the same way,
and so is the newborn twin's field. The gas index's learned baseline is saved the
same way, in a file of its own, and is only taken back if it is under 12 hours
old. The snapshot is at version 2, which added the
slow weights. A version 1 file loads with each slow weight set to the fast one.
Code from before version 2 refuses a version 2 file and starts the field fresh, so
copy the saved state aside before going back to older code.

## Normalization and the noise gate

File: `Code/Python/mind/normalize.py` and the response curve in the collector.

Each sense is turned into a 0 to 1 value by a rolling normalizer: an EMA smooth plus
a rolling min and max over a recent window, with a minimum-range guard so a flat
signal reads near zero. This is how the Creature habituates to its own room instead
of needing fixed calibration. Sound then passes a response curve with a floor, a
gain, and an exponent, so ambient hum gates out while real transients pass.

Known limit: the rolling normalizer reports where the current value sits inside its
recent range, not how loud the room is in absolute terms. The durable fix is to log
raw values so the normalizer can be calibrated against an absolute level.

## The replay harness

File: `Code/Python/tools/field_lab_v06.py`. Runs the field and the expression layer
offline against synthetic scenarios or recorded history, one gate per build step.
The matrix maths is plain Python, no numpy, so the numbers are identical on any
machine and the runs reproduce exactly. Every gate uses a fixed seed.

| Gate | What it proves | Command | Result |
|---|---|---|---|
| ring | ring shapes structure, survives a night | `--gate --set CELL_MODEL=leaky` | 6/7 |
| reservoir | distinguishes histories, echo state holds | `--reservoir` | 4/4 |
| readout | richer than a direct ring tap | `--readout` | 2/2 |
| predictive | no flattening under steady input | `--predictive` | 2/2 |
| record | an autobiography forms and tells two lives apart | `--exprmem` | 3/3 |
| bias | habit becomes memory, over-bias collapses | `--exprbias` | 2/2 |
| novelty | adaptive novelty opens a temperament band | `--exprnov` | 2/2 |
| dark-room | self-generated, bounded, learned activity | `--darkroom` | 5/5 |
| forward | learns its own light and voice, leaves the room to the room | `--forward` | 7/7 |
| events | surprise rule against the old pressure rule; `--replay` runs both on recorded senses | `--events` | 6/6 |
| feel | the loop is felt: faintly when predicted, strongly when not, not at all with no loop | `--feel` | 7/7 |
| curious | bored in a still dark room, it probes, explores its voice, and learns it | `--curious` | 9/9 |
| voice | the fixed threshold is a metronome; the relative rule speaks rarely, when surprised; `--replay` too | `--voice` | 6/6 |
| history | measures the memory horizon: how long a newborn field needs, on the same input, to become indistinguishable from an elder; changes nothing; `--replay` with `--state` runs it on recorded senses; `--compare` judges a variant against a saved control, including whether its links can still weaken in a still room | `--history` | 4/4 |
| twin | the Creature is the same with the newborn twin beside it, in the field and in the collector's own loop; the twin measures what the history gate measures | `--twin` | 6/6 |

The ring, reservoir and readout rows were measured before the predictive cell became
the default. Under today's defaults they read 4/7, 3/4 and 1/2 (the ring row's own
command, which sets the leaky cell, still gives 6/7). That is unchanged by v06.8 and
is an open item, not a result.

Rule: no tuning change ships without a control-versus-variant run. This is the
difference between "I think it is emerging" and "here is the control run."

## The newborn twin

File: `Code/Python/mind/twin_v06.py`. The collector runs a second field beside the
real one, behind `CREATURE_TWIN` (default on). The twin is born fresh. Each tick it
gets the same four senses as the real field and nothing else: no loop, and nothing
it does reaches the body. The gap between the two is how much the real field's
longer life shows. It is the history gate's measurement, running live.

- The twin must not change the Creature. The field draws its noise from Python's
  shared random stream, so the twin keeps a stream of its own and swaps it in for
  its step. It runs after the body has its commands, and a fault in it switches it
  off rather than stopping the collector. The `--twin` gate checks this in the
  field, and again in the collector's own loop with `tools/scripted_body.py`, which
  runs the collector on a scripted body and clock so two runs can be compared line
  for line.
- Both fields are read through decoders held to the fixed expression model, so the
  gap means the same as in the history gate whatever model the strip uses.
- Its field is saved next to the real one, in `creature_field_state_twin_v06.json`,
  whenever the real field is saved. It is an ordinary field state. Delete it and
  the twin starts again as a newborn at the next restart.
- The live snapshot carries a `twin` block: its age in ticks, its ring weights, and
  the gaps in arousal, balance, tempo and the largest link difference, each smoothed
  over about an hour. One row a minute goes to the `twin_log` table: the mean gaps
  over that minute and the link gap at its end. Averaged over an hour, those rows
  are the history gate's hourly figures.
- The real field feels its own voice and light through the loop and the twin does
  not, so on a body whose loop is closed the gap settles above zero. What is left
  once the twin has caught up is what the loop adds.
- Cost on the Pi 3: about 3.5 ms a tick, measured 3 October 2026.

## Dashboard

Served from the Pi on port 8080, mirrored to the VPS for remote viewing.

- `server.py`: standard-library HTTP server. Serves the page and JSON for the live
  field state and history.
- `index.html`: an SVG view of the ring and reservoir, polling once a second. Cells
  show activation, state, and relevance; links show weight, with scarred links drawn
  as ghosts. The cell inspector is always open (it follows the most active cell
  until one is hovered or pinned). A Sensors panel shows the raw readings, with
  temperature in both C and F. The reservoir is drawn from its real wiring, which
  the snapshot carries (`reservoir.w`, `reservoir.w_in`, `reservoir.input_cells`):
  every in-between ring cell into every reservoir cell, and the sparse one-way
  links between reservoir cells as arrows, coloured by sign. Clicking any cell
  pins it, lifts its own wires, dims the rest, and lists each weight in the
  inspector with what it carries this tick.
- Page layout: one screen with no scrolling. A collapsible menu on the left, the
  field always in the middle, and one chosen section beside it: cell inspector,
  raw data (sensors, all cells, system health), learning, legend, or metabolism
  (with the loop). Clicking a cell opens the inspector. "What is Creature?" and
  the hardware photo sit below the fold. On a narrow screen the menu becomes a
  row of tabs and the page stacks. A day / night / auto switch sits at the foot
  of the menu; auto follows the device's light or dark setting. All colours,
  including the field's, are defined once per mode in the stylesheet.
- Legend: built by `setV06Legend` in `index.html` and meant to name every mark the
  field can draw: cell colours and sizes, what fill, outline, the three rings and
  the glow mean, each kind of line, how selection changes the picture, and the
  status dot and counters in the top bar. When the drawing code changes
  (`buildV06`, `renderV06`, `applySelectionV06`), the legend changes with it.
- `learning.py`: reads the slow numbers that show whether it is predicting
  better, over a window of its own ticks (6 h, 24 h or 7 d): how much of its own
  light's effect the forward model explained, how far each heard tone was from
  the predicted one, average surprise across the ring, and the weight of each
  ring link. Served at `/api/learning` and drawn as the Learning panel; the
  static export writes the 24 h window. The readout weights and each cell's own
  prediction are not logged, so they have no history yet. Under the charts one
  line reports the newborn twin from the live snapshot: its age and its gaps in
  arousal, balance and links.
- Sensor API: `/api/sensors` and `/api/sensors/<name>` serve light, sound, motion,
  temperature, and pressure as stable, versioned JSON so other apps and services
  can treat the Creature as ordinary sensors. Since v07.0 they also serve CO2,
  humidity, the CO2 sensor's temperature, the raw VOC and NOx counts and the VOC
  and NOx index. Raw values come from a `sensors` block the collector adds to
  the live snapshot; missing sensors are `null`. See `instructions.md` for the
  contract. Raw history is in the `loop_log` table, and the air readings' in
  `air_log`. The battery's charge, voltage and charge rate are served the same
  way, with their history in `power_log` and `/api/power_history`.
- Sensor panel: under Raw data on the local dashboard, hidden on the public
  mirror. One tile per sensor. The air tiles carry a line of their last hour,
  read from `/api/air_history` (a row every 20 ticks). The two gas index tiles
  show the index, a word against the room's own normal (normal, raised, high;
  "warming up" for the first 45 samples) and the raw count underneath. A change
  The battery tile shows the charge, a word (charging, discharging, steady),
  the cell voltage and charge rate, and a line of its last six hours. A change
  to `server.py` needs the dashboard service restarted; the page alone does not.
- Speaker mute: a button in the local dashboard header (hidden on the public
  mirror) toggles `POST /api/speaker {"muted": bool}`. It creates or removes a
  flag file, `creature_speaker_muted`, next to the database. The collector skips
  `VOX:` commands while it exists, so the speaker is silent but the C0 cell and
  the field keep running unchanged. Mute persists across reboots.
- `export_static.py` and `sync_to_vps.sh`: export the live data to static files and
  rsync them to the VPS over SSH as a restricted user. The Pi is never exposed to
  the internet; it only makes outbound connections.

The dashboard is an output channel and a microscope. It is not part of sensing,
memory, or decision-making, and nothing that exists only for the dashboard should
shape field design.

## Repository structure

```
Creature/
  Code/
    Firmware/esp-creature-core/      ESP32-S3 body (PlatformIO)
      src/main.cpp                   four senses + two emitters, the air sensors
                                     and the e-paper, ~10 Hz JSON
    Firmware/bench/                  per-sensor bring-up sketches
    Python/
      collector/collector.py         the runtime loop on the Pi
      mind/cell_field_v06.py          the ring, reservoir, predictive cell, readout
      mind/expression_v06.py          the decoder (field -> PIX/VOX)
      mind/expression_memory_v06.py   the autobiography layer
      mind/forward_model_v06.py       predicts its own light and voice
      mind/curiosity_v06.py           probes when nothing has surprised it for a while
      mind/twin_v06.py                the newborn twin: a second field that only watches
      mind/normalize.py               rolling 0..1 normalization
      mind/gas_index.py               Sensirion's VOC and NOx index, for the dashboard only
      mind/cell_field.py              the retired 111-cell field, kept for reference
      dashboard/                      server.py, index.html, static export, sync
      tools/field_lab_v06.py          offline replay and gate harness
      tools/scripted_body.py          the collector on a scripted body and clock, repeatable
      tools/fake_body.py              a live stand-in for the ESP over TCP
      tools/gas_index_check.py        checks the gas index port against Sensirion's C
      tools/expression_preview.py     renders the decoder offline
      tools/loop_probe.py             measures the light and sound loops on the body
      data/                           SQLite history + field snapshot (gitignored)
  Hardware/                          KiCad schematics, wiring, bench notes, photos
  Archive/                           earlier experiments and versions (gitignored)
```

## Design philosophy

The ESP stays simple and stable: read sensors, stream raw values, receive commands,
drive outputs. Nothing more. It does not store memory, make decisions, or interpret
meaning. It may have body-level safety reflexes, because those protect hardware.

It has one, built on 7 October 2026: the low-battery reflex. It acts on the
cell's voltage, not on the gauge's percentage, which read 2 % with four hours of
running left. When the cell stays at or under 3.40 V for ten seconds the body
caps the strip's brightness (12 in place of 40), whatever frames it is sent,
until the cell is back above 3.50 V or charging. When it stays at or under
3.30 V for thirty seconds the body darkens the strip, draws "Battery low" on
the e-paper (the panel keeps its image with no power), and deep-sleeps. Every
five minutes it wakes for a moment, reads the gauge, and sleeps again unless the
cell is charging or at 3.60 V or more; then it boots as usual and the collector
reconnects by itself. With no reading from the gauge the reflex does nothing.
The levels come from the run to flat of 7 October: about 55 minutes were left at
3.4 V and 20 at 3.3 V, and nothing stopped the discharge until the cell's own
protection near 2.4 V. Deep sleep does not cut the power. The PowerBoost, the
strip's idle current and the sensors still draw from the cell, so the reflex
buys time and does not replace the charger. `BAT:<volts>` is a bench test: for
two minutes the reflex acts on that voltage, and a test sleep is two 20 second
steps.

The Pi holds everything that changes: normalization, the field, learning,
expression, persistence. This lets the senses and the output stay stable while the
mind iterates in Python.

The body should stay dumb. The mind should stay changeable. That split is what lets
the Creature evolve without rewriting hardware.

## Known limitations

- The loop is validated in simulation, not yet on hardware. The physical light and
  sound loops are the next real test, and the result the project most needs.
- The light loop is physically open. Measured with `loop_probe` on 2 October 2026
  in a 768 lux room: no strip frame, up to all four channels at the cap, added a
  measurable amount at the BH1750 (every frame within the 1.15 lux sensor noise).
  The sensor has to move or be shielded before the Creature can see its own light.
  The sound loop was inconclusive in the same run: the room was louder than the
  tones, and the body stopped streaming while it played one.
- The sound loop is physically closed. With the v06.8 firmware flashed on 2 October
  2026, the first tones near 400 Hz came back at 11,500 to 16,500 at their own
  pitch, against 200 to 2,000 for the room at that pitch just before. A tone near
  300 Hz came back much weaker (about 3,700 against 1,100), so the small speaker
  is far louder at the top of its range than the bottom.
- The light-and-weather side stays weak by design, because slow steady signals
  produce no surprise. Only the loop keeps that side alive.
- Bias and novelty steering are not wired to the body, so the live Creature records
  its autobiography but is not yet steered by it.
- The battery reaches the Creature only as dimmer light, and only when
  `CREATURE_BATTERY_CEILING=1`. A drained Creature does not rest or sleep more,
  and learning does not slow: both first attempts at that damaged the links
  (see "The battery and the reserve"). The voice is as loud at 10 % as at full.
- A steady self-loop is as predictable as a steady room, so the predictive field
  habituates to it unless the probe stays unpredictable.
- The air sensors and the e-paper (v07.0) sit on the body but outside the
  Creature. The field does not sense the air, and nothing it does reaches the
  panel except as numbers to read. Bringing the air in would be a design step
  with its own gate.
- The body's WiFi signal measured -89 to -95 dBm on 4 October 2026, weak enough
  to drop the link. The cause (antenna placement or the 3V3 rail) is not
  established. The loops have not been re-measured on the body since the air
  sensing and the panel were added.

## Roadmap

The lesson of v06 holds: the organism becomes more alive when action returns through
the world, not when the model grows more complicated. The hardware roadmap follows
from that. Detail is in `Creature v07 Hardware Potential.md`. The name v07.0 went
to the air senses and e-paper build of 4 October 2026, which is not on this list:
they are passive inputs and a readout, added because the parts were at hand. The
steps below are still the direction.

- Give v06 a body. Build a rigid carrier that fixes sensor and emitter placement, so
  the loop can be tuned from weak to strong physically instead of by luck.
- Characterize the existing loops. Measure that a known strip frame moves the light
  reading and a known tone moves the mic or the IMU.
- Battery as real metabolism. A LiPo, a load-sharing charger, and a MAX17048 fuel
  gauge on the existing I2C bus, so expression costs energy and feeding the Creature
  becomes a real event.
- Haptics before locomotion. A small vibration actuator the IMU can feel, a safe
  action-sense loop without wheels.
- Touch and skin. Capacitive pads as an event channel, so human contact becomes part
  of the body loop.

Keep the mind on the Pi. Moving the field to the ESP breaks the body/mind split,
kills iteration speed, and buys nothing. The field is a few percent of CPU at 1 Hz.

More ESPs as separate sense-bodies is the version of "more ESPs" worth doing, and
the firmware already supports it through the WiFi TCP bridge. Spatially separated
nodes streaming to one Pi mind is how spatial structure would form. That comes after
one richer single body shows structure that survives a night and a replay test.

Do not add cells, senses, or motors casually. Prove one part on the bench, prefer
closed loops over passive inputs, and prefer physical consequence over a richer
dashboard.

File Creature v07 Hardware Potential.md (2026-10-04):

# Creature v07 Hardware Potential

Version: v07 hardware potential, June 23 2026. Status: planning note.

Note, 4 October 2026: the build name v07.0 was given to something not planned
here. Two air sensors (SCD41, SGP41) and an e-paper readout went onto the v06
body that day. They are passive inputs and a display, outside the Creature's
flow, and they change none of the priorities below. The stages called v07A to
v07D further down are still plans.

This document collects hardware opportunities for the next several Creature
evolutions. It does not replace the v06 wiring document or the v06 rollout plan.
It is a map of what is worth trying, in what order, and why.

The short read: the Creature does not need a pile of new sensors yet. It needs
better anatomy. The strongest next hardware move is to make the existing v06
body physically coherent, close the light and sound loops deliberately, then add
real energy through a battery. After that, touch, haptics, proximity, and limited
movement become worthwhile.

## Starting Point

v06 already has the important shape:

- Four senses: BH1750 light, INMP441 sound, ICM-20689 motion, BME280 weather.
- Two emitters: SK6812 RGBW strip and MAX98357A speaker.
- ESP32-S3 body: read raw sensors, stream JSON, receive commands, render outputs.
- Raspberry Pi mind: normalize, step the field, persist state, send `PIX:` and
  `VOX:`.
- Twelve-cell ring plus fixed reservoir and predictive cells.

That means the hardware question is not "what can we add?" It is "what physical
couplings make the field less dependent on a lucky room?"

The current v06 goal still stands: action must become sensing. The strip should
return through the light sensor. The speaker should return through sound or body
motion. The body should have costs and constraints the field can feel.

## Design Rules

Use these rules before adding hardware:

1. Prefer closed loops over more passive inputs.
2. Prefer physical consequence over richer dashboards.
3. Keep the ESP dumb. It may have safety reflexes, but not cognition.
4. Add raw senses or render-only actuators; interpretation stays on the Pi.
5. Do not add new field anchors casually. Battery, haptics, touch, and proximity
   can often enter as modulation or event channels first.
6. Prove one part on the bench before integrating it into firmware.
7. Do not add locomotion until the body has power, proximity, contact, and a
   hard stop.

## Priority 0: Give v06 a Body

The current hardware is still a bench organism: separated organs on a breadboard.
That is perfect for bring-up, but weak for the loop. The first v07-ish hardware
move should be a small body carrier.

Build a rigid carrier that fixes:

- Strip position.
- BH1750 position and angle relative to the strip.
- Speaker position.
- INMP441 position and acoustic path relative to the speaker.
- IMU position on the body, not loose on the breadboard.
- BME280 position away from direct heat from the ESP, strip, and PowerBoost.
- PowerBoost, battery, and future fuel gauge placement.

Make the light sensor and mic mounts adjustable. The v06 loop should start loose:
slightly off-axis, partially shielded, or physically separated enough that it can
sustain activity without running away.

Useful body details:

- A small black or translucent light well between strip and BH1750.
- A movable flag or shutter to tune how much strip light reaches the sensor.
- A small speaker cavity or baffle.
- A mic tunnel with foam or a partial shield so room sound and self-sound can be
  tuned separately.
- Strain relief for the strip and speaker wires.
- A power switch on PowerBoost EN to GND.

Acceptance:

- A known `PIX:` frame causes a measurable, repeatable lux change.
- A known `VOX:` tone causes a measurable, repeatable mic or IMU response.
- Tapping or moving the body produces a motion response that is not just loose
  wiring.
- Sensor placement can be changed without rewiring.

## Priority 1: Characterize the Existing Loops

Before adding new parts, measure the two loops v06 already claims.

### Light Loop

Test:

- Send fixed strip frames: dark, dim blue, dim white, warm, cool, moving pulse.
- Log raw `light_lux` and normalized `light_norm`.
- Repeat at different BH1750 angles and distances.

Desired result:

- The BH1750 sees the strip reliably.
- Ambient room light does not completely swamp the strip.
- The coupling can be tuned from weak to strong physically.

Hardware idea:

- Add a small adjustable shield or tube around the BH1750.
- Consider a second light sensor only if the single BH1750 cannot both sense the
  room and see the strip. One sensor could face outward, one inward.

### Sound Loop

Update (27 Jun 2026): the firmware no longer uninstalls the mic during a tone. Mic
(I2S0) and amp (I2S1) are separate peripherals, so the mic stays live and the
creature hears itself while speaking. That direct "hear self while speaking"
feedback is now available, which is the start of the audio loop.

Good loop options:

- Let the mic hear the tail after the tone ends.
- Use the IMU as a body-conducted voice sensor: speaker vibration returns as
  motion.
- Add a small vibration/contact sensor near the speaker if the IMU is not
  sensitive enough.
- Use a second sound sensor later only if the single I2S path remains too
  constrained.

Desired result:

- `VOX:` output creates some returning signal without having to make the speaker
  loud.
- The returning signal is tunable by speaker mount, cavity, and mic placement.
- The Creature can be quiet in the room while still sensing its own voice.

## Priority 2: Battery as Real Metabolism

This is the strongest v07 hardware addition.

Use a single LiPo cell, PowerBoost/load-sharing charger path, and a MAX17048 fuel
gauge on the existing I2C bus. The fuel gauge reads raw cell voltage and state of
charge, then the ESP streams:

```json
{"battery_pct": 84.2, "battery_v": 4.05}
```

Why this matters:

- The field already has energy, rest, sleep, and learning cost.
- Right now that metabolism is simulated while the body has unlimited USB power.
- Battery makes scarcity physical.
- Expression becomes costly: strip brightness and voice are no longer free.
- Feeding the body by plugging it in becomes a real event.

Hardware:

- MAX17048 fuel gauge, I2C address `0x36`.
- Adafruit breakout: LiPo through its JST pass-through (either port) to the PowerBoost.
  VIN to 3V3. VIN only powers the I2C pull-ups; on the battery it would put ~4.2V on SDA/SCL.
- GND to common ground.
- SDA/SCL to GPIO 8/9.
- Protected LiPo cell or charger with undervoltage protection.
- PowerBoost EN switch for physical off.

Firmware:

- Add `ENABLE_BATTERY`.
- Stream `battery_pct` and `battery_v`.
- Add body-level safety reflexes:
  - Below warn threshold, cap strip brightness first.
  - Below critical threshold, stop outputs and deep-sleep the ESP.
  - Keep this on the body because it protects hardware.

Mind:

- Parse and log battery.
- Show it on the dashboard.
- Scale field energy income by state of charge.
- Optionally create a small event when charge drops sharply under load.

Acceptance:

- I2C scan sees `0x36` with the other v06 devices.
- Battery percent and voltage are stable and plausible.
- Unplugging power causes a gradual state-of-charge decline.
- Low charge makes the Creature dimmer, quieter, more restful, and more likely
  to sleep without corrupting slow state.

## Priority 3: Haptics Before Locomotion

Haptics are movement without the danger and complexity of mobility. They are a
very good fit for this Creature.

Candidate:

- DRV2605L haptic controller.
- I2C default address `0x5A`.
- Drives ERM vibration motors or LRA haptic actuators.

Why it fits:

- The Pi can send a render-only command such as `HAP:intensity,ms,effect`.
- The body vibrates.
- The IMU senses the vibration.
- That creates a physical action-sense loop without wheels.
- It gives the Creature a fidget, startle, shiver, purr, or pulse.

Important address note:

- DRV2605L default `0x5A` conflicts with the default MPR121 touch controller.
- If both are added, pick breakouts or address wiring that avoid the clash.

Protocol idea:

```text
HAP:effect,intensity,ms
```

Start simpler if needed:

```text
HAP:intensity,ms
```

Acceptance:

- A haptic command produces a visible IMU motion response.
- Different effects or durations produce distinguishable motion signatures.
- Haptic output does not brown out the ESP or corrupt I2C.
- Haptics can be disabled independently with an environment or compile flag.

## Priority 4: Touch and Skin

Touch is probably the next best sense after battery and haptics because it gives
the Creature contact with a person and a body boundary.

Candidate:

- MPR121 capacitive touch controller.
- 12 electrodes over I2C.
- Default address `0x5A`, configurable on many breakouts to `0x5B`, `0x5C`, or
  `0x5D`.

Possible skin:

- Copper tape pads under paper, fabric, acrylic, or thin printed shell.
- One pad near the light sensor.
- One pad near the speaker.
- Several along the strip.
- One "hold" pad near the body base.

How to feed the field:

- Start as an event channel, not a new anchor.
- Derive values such as `touch_any`, `touch_count`, `touch_region`, and
  `touch_delta`.
- Later, if touch proves central, add a dedicated ring anchor.

Why it matters:

- Touch has meaning at organism scale.
- It gives a non-room-dependent source of surprise.
- It lets human interaction become physical, not just observational.

Acceptance:

- Touch is stable across humidity and power states.
- Idle touch does not chatter.
- A hand, tap, or hold creates distinct event patterns.
- The field reacts without saturating or staying permanently aroused.

## Priority 5: Near-Field Presence

Presence is useful, but less important than battery, haptics, and touch.

Candidate options:

- VL53L1X time-of-flight distance sensor, I2C address `0x29`, roughly near-field
  to several meters depending on target and conditions.
- APDS9960 proximity, RGB color, ambient light, and gesture sensor. Useful if the
  Creature should sense color or near motion around the face.

Use cases:

- Someone approaches.
- Something blocks the Creature's face.
- The Creature can point a sensor head and tell whether the world changed.
- Strip color can be sensed as color, not only brightness, if using APDS9960.

How to feed the field:

- Start with a scalar `presence` or `distance_change`.
- Treat sudden approach as event pressure.
- Avoid making it a permanent fifth/sixth anchor until the v06 ring has proven it
  survives nights with the existing four senses.

Acceptance:

- Stable reading at the intended body scale.
- Room geometry does not keep it permanently high.
- Approach and retreat are distinguishable.
- It still works with the strip and speaker active.

## Priority 6: One Small Motor

Do not start with locomotion. Start with orientation.

Best first motor:

- One micro servo that moves a sensor, a light shield, a speaker baffle, or a
  small head.

Why:

- It creates action with consequence.
- It changes what the sensors read.
- It is easier to make safe than wheels.
- It lets the Creature probe the world without roaming.

Good first mechanisms:

- Light sensor eyelid/shutter.
- Strip-to-sensor coupling vane.
- Speaker baffle.
- Head pan with BH1750 or ToF.
- Tiny body rock that the IMU can feel.

Servo control:

- Direct PWM from an unused safe GPIO if only one servo is used.
- PCA9685 I2C servo driver later if multiple servos are used.
- Power servos from a separate 5V rail with common ground, not from the ESP 3V3.

Protocol idea:

```text
MOV:channel,position,speed
```

Acceptance:

- Motion changes at least one sensor reading.
- The IMU can distinguish self-motion from stillness.
- Servo current does not reset the ESP.
- Motion has physical limits and cannot grind.

## Later: Mobility

Actual locomotion should wait.

Requirements before wheels or tracks:

- Battery and fuel gauge working.
- Low-battery reflex working.
- Touch or bump sensing.
- Distance/proximity sensing.
- Hard power switch.
- Software command timeout.
- Slow speed limit.
- Physical test space.

Candidate:

- DRV8833 motor driver for two small DC gear motors or one stepper.

Why to wait:

- Locomotion changes risk class.
- It creates cable, power, collision, and runaway problems.
- A Creature that can shiver, turn its head, and sense touch is already embodied
  enough to learn from action.

## Candidate Hardware Summary

| Category | Candidate | Bus / pins | Why it matters | Priority |
|---|---|---|---|---|
| Body geometry | Chassis, baffles, shields | mechanical | Turns breadboard parts into anatomy | now |
| Battery | MAX17048 + LiPo + PowerBoost | I2C `0x36`, power | Makes metabolism physical | v07 |
| Haptics | DRV2605L + ERM/LRA | I2C `0x5A` | Safe movement loop through IMU | v07+ |
| Touch | MPR121 + copper pads | I2C `0x5A-0x5D` | Contact, holding, skin | v07+ |
| Presence | VL53L1X | I2C `0x29` | Approach/retreat, near world | later |
| Color/proximity | APDS9960 | I2C | Sees color/gesture/proximity | later |
| Orientation | Micro servo | PWM or PCA9685 | Moves sensor or body part | later |
| Locomotion | DRV8833 + gear motors | GPIO/PWM | Actual movement | much later |

## I2C Address Watchlist

Current v06 bus:

- BH1750: `0x23`
- BME280: `0x76`
- ICM-20689 / MPU family IMU: `0x68`
- SGP41: `0x59` (added 4 October 2026)
- SCD41: `0x62` (added 4 October 2026)
- Planned MAX17048: `0x36`

Possible additions:

- VL53L1X: `0x29`
- DRV2605L: `0x5A`
- MPR121: default `0x5A`, often configurable to `0x5B`, `0x5C`, `0x5D`

The main conflict to avoid is DRV2605L and MPR121 both at `0x5A`.

## Evolution Path

### v07A: Anatomy and Loops

- Build the body carrier.
- Stabilize sensor and emitter placement.
- Characterize the strip-to-light loop.
- Characterize the speaker-to-mic or speaker-to-IMU loop.
- Keep the field and firmware behavior otherwise unchanged.

Success:

- The Creature's own output reliably returns as input.
- Coupling can be tuned physically.
- Nights show self-sustained activity without runaway.

### v07B: Real Energy

- Add LiPo, PowerBoost/load-sharing path, MAX17048.
- Stream battery percentage and voltage.
- Add low-battery safety reflexes.
- Couple state of charge to field metabolism.

Success:

- Full charge feels different from low charge.
- Expression costs energy.
- Feeding the Creature changes behavior.

### v07C: Haptic Body

- Add DRV2605L and a small vibration actuator.
- Add `HAP:` rendering.
- Let the IMU feel self-vibration.

Success:

- The Creature can shiver or pulse.
- The field can sense the effect physically.
- Haptics become a safe motor primitive.

### v07D: Skin

- Add MPR121 and touch pads.
- Treat touch as event and contact state.

Success:

- Touch, hold, and release create distinct field events.
- Human interaction becomes part of the body loop.

### v08: Orientation

- Add one servo to move a sensor, baffle, eyelid, or head.
- Add `MOV:` rendering with limits.

Success:

- Movement changes sensing.
- The Creature can probe without locomotion.

### v09: Mobility, Maybe

- Only after power, proximity, touch/bump, and safety reflexes exist.
- Start extremely slow.

Success:

- Movement creates meaningful new sensor history without making the system unsafe
  or unobservable.

## First Build Recommendation

The best next build is:

1. Make a small adjustable body carrier.
2. Measure and tune the existing light and sound loops.
3. Add MAX17048 battery sensing.
4. Couple battery to metabolism.
5. Add haptic vibration and close that loop through the IMU.

That path keeps the Creature small, embodied, and testable. It also respects the
v06 lesson: the organism becomes more alive when action returns through the
world, not when the model grows more complicated.

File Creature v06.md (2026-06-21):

# Creature v06 — small field, real body, closed loop

Version: v06, June 14 2026. Status: design, canonical.

Supersedes the earlier v06 draft (the "more world" plan on the 111-cell field),
preserved in `Archive/Creature v06 (more world draft, superseded).md`. Pairs with
`Creature v06 — expression layer.md` (the decoder) and
`Creature v07 — power and metabolism.md` (battery, energy).

## The test this version has to pass

The creature's one real enemy is entropy. Left alone in a steady room, the field
decays toward a flat, even, quiet state. The runs showed it: generic homogeneous
connections, most connections lost overnight. The expression preview showed it
again, arousal surging on startup then settling toward zero. A bigger field did not
fix it. Adding cells only added more tissue to go uniform.

v06 is built to pull the other way. It does two things that fight entropy, and
everything else serves them.

First, it gives the creature its own source of disturbance: a closed loop. The
creature acts on the room and senses its own action. That is a gradient it makes
for itself, so it stops depending on the room being interesting. A creature that
can poke the world and feel the poke does not have to go quiet.

Second, it makes the body small enough that every part matters. Eighty idle cells
averaging into mush is entropy. Twelve cells where each one carries signal resists
it, because there is no dead tissue to homogenize.

If v06 does not deliver those two things, it is a prettier screensaver, and it
fails its own test. The rest of this document keeps them central.

## My read, plainly

It makes sense and it pulls away from entropy, on one condition: the loop is the
point, not a feature. If the strip and speaker only display the field while the
field still settles to quiet, we have added output to a dying signal. The loop, and
the choice to let the creature stay aroused instead of tuning it to silence, are
what make the claim true. Built that way, this is the most alive the project has
been. Built as more output on the old field, it is not.

## What changes from the earlier v06

The earlier v06 kept the 111-cell field and added senses to it. This one:

- Shrinks the field to 12 cells (the ring below). Adding cells was the wrong lever.
- Decouples output size from field size. A 16-pixel strip and a speaker are driven
  by a few cells through a decoder, not by one cell per pixel.
- Treats the closed loop as the centerpiece, not a later nicety.
- Commits to deeper cells as the next step, because a small field of simple cells
  homogenizes just like a big one, only faster to watch.
- Adds a reservoir computing layer in the 6 inner cells, replacing the earlier
  inner loop with a principled fixed-weight substrate.

What carries over: the senses and the strip hardware (wiring detail lives in the
archived draft and in v07), and the decoder (the expression-layer doc).

## The body

Four senses and two emitters on one ESP32-S3. The ESP stays dumb: read, stream,
receive commands, drive outputs. Nothing more.

Senses:

- Light: BH1750 lux, on the I2C bus.
- Sound: INMP441 RMS, on I2S.
- Motion: MPU-6050 reduced to one motion scalar, on I2C. Correlates with sound.
- Weather: BME280 temperature and pressure, on I2C. A slow sense with a real
  day-night rhythm that stays nonzero at night, so the field has something to hold
  when light reads zero in the dark.

Emitters:

- LED strip: SK6812 RGBW, about 16 pixels. The field's skin and face.
- Speaker: MAX98357A amplifier and a small speaker. The field's voice.

I2C addresses, strip power, the data-line resistor, and pin choices are unchanged
from the archived draft and the v07 hardware section. They do not need rethinking
here.

## The field: a ring of twelve

Six anchors and six in-between cells, in a ring. Six reservoir cells form an inner
ring. Hold it at twelve outer cells. Do not grow until the weights demonstrably
shape behavior and survive a night.

Why a ring and not a full mesh. A mesh connects every pair through its own cell, so
every in-between cell touches hardware on both ends. It is wide and shallow, a
switchboard with no interior, and depth has nowhere to live in a switchboard. The
ring keeps an interior — the reservoir — which is where signal history accumulates
without being tied to a single sensor.

The ring order is the design, because adjacency is what mixes. Two rules set it:
put correlated senses next to each other, and put each emitter next to its own
sense so the loop is built into the anatomy.

| Position | Anchor | In-between to next | What that cell is |
|---|---|---|---|
| 1 | Speaker (out) | Speaker × Sound | hears its own voice (loop)  |
| 2 | Sound (in) | Sound × Motion | sound and motion (paired) |
| 3 | Motion (in) | Motion × LED | movement drives light |
| 4 | LED strip (out) | LED × Light | sees its own light (loop) |
| 5 | Light (in) | Light × Weather | light and weather (paired)  |
| 6 | Weather (in) | Weather × Speaker  | the one weak gap |

Two of the six in-between cells are the loop made internal: the cell between the
speaker and the mic hears the creature's own voice, the cell between the strip and
the light sensor sees its own light. Both correlated sense-pairs (sound with motion,
light with weather) get a dedicated cell. One gap, weather to speaker, is weak, the
honest cost of closing a ring. Each anchor is one cell. The two emitter anchors are
the expression cells.

## Layout diagram

![[v06_ring_layout.svg]]

Outer ring: 6 sensor/emitter anchors alternating with 6 in-between cells. Orange
edges are the closed-loop paths. Blue inner ring: 6 reservoir cells with fixed
random weights. Dashed orange arrows: trained readout from reservoir to emitters.

## The reservoir (inner ring)

The six inner cells are a reservoir — not a ring of simple leaky integrators, but a
fixed recurrent substrate whose weights are set once at init and never updated by
Hebbian learning.

How it works. The outer in-between cells drive the reservoir as input. The reservoir
holds a time-delayed, high-dimensional echo of recent sensor history. The two
emitter anchors (Speaker, LED strip) are the only nodes whose outgoing weights are
trained. They read from the reservoir state and learn which linear combination to
express.

Why fixed weights. A Hebbian reservoir homogenizes for the same reason the outer
field did: co-activation flattens everything toward the mean. Fixing the reservoir
weights removes that pressure from the interior. The richness comes from the random
sparse connectivity, not from learning — the echo state property means any
sufficiently varied input history will produce a distinguishable reservoir state.
The emitters then train a simple linear readout on top of that state.

Spectral radius. The reservoir's weight matrix must have a spectral radius below 1.0
for the echo state property to hold — activity echoes without blowing up. A starting
value around 0.9 is a reasonable first guess. Too low and the reservoir damps out
before the emitters can read it. Too high and it diverges. This is a field_lab
parameter, easy to sweep.

Readout learning. The emitter weights can train via a running delta rule against the
prediction error: what the emitter expressed versus what the sensors subsequently
confirmed. This connects naturally to the predictive cell direction — the emitter
predicts, the loop closes, the error drives the update. The reservoir does not
change; only the readout does.

What this gives the creature. Temporal memory without weight explosion. Cross-modal
mixing without proximity constraints — an R-cell can simultaneously receive the echo
of sound from two steps ago and the current weather pressure, neither of which share
a direct edge on the outer ring. And a clear separation between the processing layer
(reservoir, fixed) and the learning layer (readout, adaptive), which makes the
system easier to reason about and debug.

What it does not give. It does not replace the closed loop. The loop is still the
primary entropy fighter — the reservoir just gives the emitters richer material to
read. A reservoir with no loop input is still a filter on room events. The loop is
what lets the creature generate its own activity.

## The deep cell (next, and load-bearing)

A field of twelve simple leaky integrators homogenizes the same way a field of a
hundred did. The reduction only pays off if each cell carries more. This is the next
build step and gets its own document, but v06 commits the direction now.

The leading candidate is a predictive cell. Each cell holds a small expectation of
its next input and passes on the error — the gap between what it expected and what
arrived. A cell that predicts well goes quiet. A cell that is surprised speaks. This
is the negentropy engine in miniature: the cell builds a model and feeds on
surprise. It also moves off copying a neuron, because the unit is prediction error,
not a firing rate.

The reservoir direction and the predictive cell direction are compatible. The outer
ring cells can be predictive (they have inputs to predict against) while the inner
reservoir cells stay fixed. The readout weights on the emitters train against
prediction error. All three layers — predictive outer ring, fixed reservoir,
adaptive readout — pull in the same direction: away from uniform quiet.

Two alternatives to settle in the next pass. An oscillator cell, where each cell is
a phase that entrains with neighbors, so the field keeps its own rhythms and never
fully flattens. And a reaction-diffusion cell, two coupled variables that grow
patterns on their own. All three share the one property the leaky integrator lacks:
they do not settle to a flat line by themselves.

## Expression

The decoder is specified in full in `Creature v06 — expression layer.md`. In short:
the field is read once per tick, read-only, and four signals come out. Arousal,
overall activation gated by energy, drives a white glow and the voice volume.
Balance, warm senses against cool senses, drives strip color and voice pitch. Tempo,
from ripple, drives shimmer, a travelling pulse, and voice roughness. The spatial
profile along the sound-to-light axis drives per-pixel color, so the strip shows the
field's own geography. The body renders `PIX:` and `VOX:` lines and decides nothing.

The preview tool, `Code/Python/tools/expression_preview.py`, already runs this map
offline, renders the strip, and synthesizes the voice. It proved the map reads the
field correctly. It also showed the field going quiet, which is the problem the loop
and the reservoir exist to answer.

## The loop (the centerpiece)

Place one light sensor where it can see the strip. Place the mic where it can hear
the speaker. Now the creature's own output returns as input. When it lights up, it
sees its own light. When it sounds, it hears itself. Action causes sensing. This is
the move that lets the creature generate its own activity instead of waiting for the
room to hand it some.

The ring already prepares this. The strip sits next to the light sensor, the speaker
next to the mic, so the loop exists in the body plan before it exists in the room.
The physical placement completes it.

Start the coupling loose. A tight loop can run away — the light driving the sensor
driving the light. Begin with the perceiving sensor weak, or slightly off the
emitter's direct line, and let the coupling grow. The aim is a creature that can
sustain itself, not one that screams into its own eye.

## The stance on going quiet

The field is built to stop reacting once nothing changes. That is correct for a
filter and wrong for a creature meant to stay alive. v06 takes a position: do not
tune the creature to silence. Let arousal persist. Let it stay restless, let it stay
bored in the way that drives it to act rather than the way that drops it to zero.
It should be allowed to stay alive. The loop gives it the means, the reservoir gives
it history to act on, this stance gives it the permission.

In practice that means the energy gate must not be the dominant voice. It can dim a
truly drained creature, but a healthy one in a dull room should still hum, fidget,
and probe through the loop. If the only thing keeping it active is the room, it is
not yet a creature.

## Build sequence

Each step is validated before the next.

1. Shrink the field to the twelve-cell outer ring, keeping the current leaky-integrator
   cell for now. Validate in field_lab that the ring runs, that the two correlated
   cells and the two loop cells carry above-baseline weight, and that structure
   survives a simulated night. Control versus variant, reproducible seed.
2. Add the six reservoir cells in the inner ring. Set weights randomly, fix the
   spectral radius below 1.0. Validate that the reservoir state is distinguishable
   across two different input histories. Sweep spectral radius in field_lab.
3. Wire readout weights from reservoir to the two emitters. Train via delta rule
   against prediction error. Validate that the emitter output tracks field state
   more richly than a direct connection from the outer ring.
4. Deepen the outer ring cells — swap the leaky integrator for the predictive cell.
   Validate that the field no longer flattens to uniform under steady input.
5. Add the senses and place them by the ring order. Validate that the cross-modal
   cells differentiate.
6. Wire the decoder into the collector behind `ENABLE_STRIP` and `ENABLE_VOICE`.
   Preview with the tool first, then on hardware.
7. Close the loop, loose. Add the strip-facing light sensor and the speaker-facing
   mic. Watch for self-sustained activity, and for runaway. Tighten slowly.
8. Run it for nights. Look for differentiation that survives, and for the creature
   doing something the wiring did not obviously predict.

## What v06 is not

- Not the 111-cell field. That is retired to history.
- Not the mesh. The ring holds.
- Not the grand memory roadmap, the vector store, concept graph, and dream layer.
  Still an abandoned branch, not a plan.
- No growth, mitosis, or death yet. The field stays at twelve until the deep cell
  and the loop prove out.

## How we will know it worked

The entropy test, made concrete. v06 succeeds if, after nights of running:

- The field stays differentiated instead of homogenizing. Distinct cells, distinct
  weights, not an even wash.
- Two creatures with different histories can be told apart.
- The creature stays active in a dull room, carried by its own loop, not flat.
- At least once, it does something its wiring did not obviously predict.

The first three are measurable now, in field_lab and on the dashboard. The fourth is
the one that matters and the hardest to fake. It is also the only real proof that
the thing is pulling away from entropy on its own.

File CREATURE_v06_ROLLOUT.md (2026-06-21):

# Creature v06 rollout plan

Version: v06 rollout, June 15 2026. Status: process doc.

Pairs with `Creature v06.md` (the design and the 8-step build sequence). That doc
says what to build. This doc says how to roll it out without building a costly bug.

## The one rule

Change one layer at a time. Validate it. Commit it. Tag it. Then move to the next.

Never edit software, hardware wiring, and firmware in the same sitting. If two
layers move together and something breaks, you cannot tell which one did it. That
is the bug that costs a weekend.

## Order

Three layers, in this order:

1. Software (the field, in simulation). Pure Python, no hardware risk. The novel and
   risky logic lives here. Prove it in `field_lab` before any wire moves.
2. Hardware bring-up (each sensor and emitter, one at a time). Confirm every part
   functions on the bench with a minimal test sketch, before the real firmware
   touches it.
3. Firmware integration (the full body, streaming, then the loop). Only after the
   field logic is proven and every part reads clean on its own.

Software first because it is where the design is unproven and where the AI tools can
iterate freely with zero physical cost. Hardware second because a sensor that lies to
you is the worst bug to chase through firmware. Firmware last because it only has
value once both sides of it are known good.

## Phase 0: freeze a baseline (do this first, once)

Before any v06 work, lock a known-good point you can always return to.

- Commit everything currently working. The repo has uncommitted deletes and new
  files right now. Clean that up first so the baseline is real.
- Tag it: `git tag v05-last-good` then `git push --tags`.
- Confirm you can check it out clean: `git stash` any junk, `git checkout v05-last-good`,
  see it run, then `git checkout main`.

If you cannot return to a working version on demand, you have no safety net, and
every later phase is riskier than it needs to be.

## Phase 1: software (the field, in simulation)

This phase is steps 1 to 4 of the v06 build sequence, all in `field_lab.py`. No
hardware. Each step gets its own validation gate and its own tag.

Gate after every step. Do not start the next step until the current one passes.

- 1.1 Shrink to the twelve-cell ring. Gate: ring runs, the two correlated cells and
  two loop cells carry above-baseline weight, structure survives a simulated night.
  Control versus variant, fixed seed. Tag `v06-1-ring`.
- 1.2 Add the six reservoir cells. Gate: reservoir state is distinguishable across
  two different input histories, spectral radius swept and a working value chosen.
  Tag `v06-2-reservoir`.
- 1.3 Wire readout weights to the two emitters, train via delta rule. Gate: emitter
  output tracks field state more richly than a direct outer-ring connection.
  Tag `v06-3-readout`.
- 1.4 Swap the leaky integrator for the predictive cell. Gate: field no longer
  flattens to uniform under steady input. Tag `v06-4-predictive`.

End of phase 1: the brain works in simulation. Nothing physical has moved. If the
entropy test fails here, it fails cheap, and you fix it before spending on hardware.

Keep `expression_preview.py` in the loop. It already runs the map offline. Use it as
your eyes on every gate above.

## Phase 2: hardware bring-up (one part at a time)

Goal: prove every sensor and emitter functions on its own, with the smallest
possible test firmware, before the real firmware exists. A part that fails here
fails in isolation, where it is obvious. The same failure inside the full firmware
looks like a logic bug and eats hours.

Process for each part:

- Flash a minimal single-purpose sketch that does nothing but exercise that one part.
- Read the result over serial.
- Confirm against the pass criterion below.
- Only then add the next part. Never bring up two parts in one sketch.

Start with an I2C scan. Three of the four senses sit on I2C. Run an I2C scanner
sketch and confirm you see the expected addresses before testing any single device:

- BH1750 light: address 0x23 (or 0x5C if ADDR is high).
- MPU-6050 motion: address 0x68.
- BME280 weather: address 0x76 (or 0x77).

If a device does not show on the scan, it is wiring or power, not code. Fix it here.
Do not write driver code against a device the bus cannot see.

### Sensors

- Light (BH1750, I2C). Pass: lux value changes when you cover and uncover the sensor.
  Reads roughly zero in the dark, climbs under a lamp.
- Sound (INMP441, I2S). Pass: RMS rises when you clap or talk, falls in a quiet room.
  This one is I2S, not I2C, so it will not appear on the I2C scan. Test it on its own.
- Motion (MPU-6050, I2C). Pass: the single motion scalar rises when you move or tap
  the board, settles when still.
- Weather (BME280, I2C). Pass: temperature reads a plausible room value, pressure
  reads a plausible absolute value, both nonzero and stable. This is the sense that
  must stay nonzero at night, so confirm it is genuinely reading, not stuck.

### Emitters

- LED strip (SK6812 RGBW, ~16 px). Pass: a test pattern lights every pixel, all four
  channels (R, G, B, W) show correctly, no dead or wrong-colour pixels. Confirm the
  data-line resistor and strip power are as the v07 hardware section specifies before
  driving it. Watch current draw if powering from the board.
- Speaker (MAX98357A amp + speaker). Pass: a test tone plays clean, volume responds
  to a commanded level, no constant hiss or distortion at rest.
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

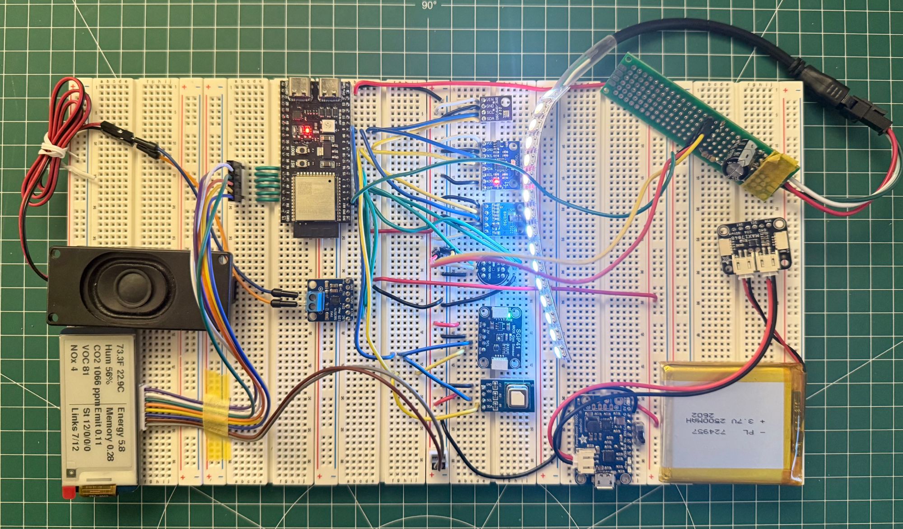
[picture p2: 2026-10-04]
Code/Python/dashboard/creature-v07.0.jpg

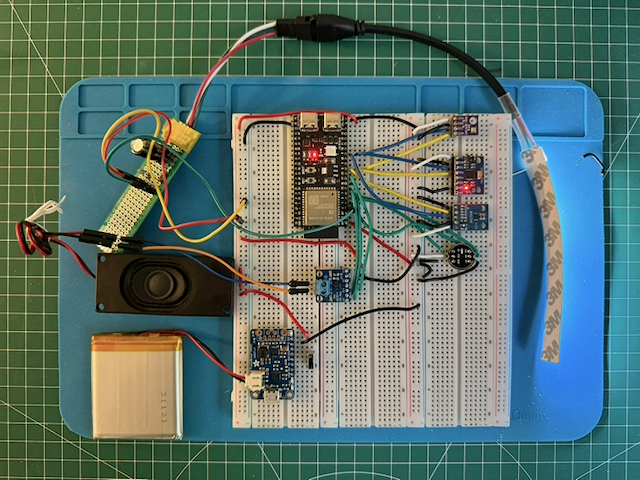
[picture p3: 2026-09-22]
Code/Python/dashboard/creature-v07-battery.png

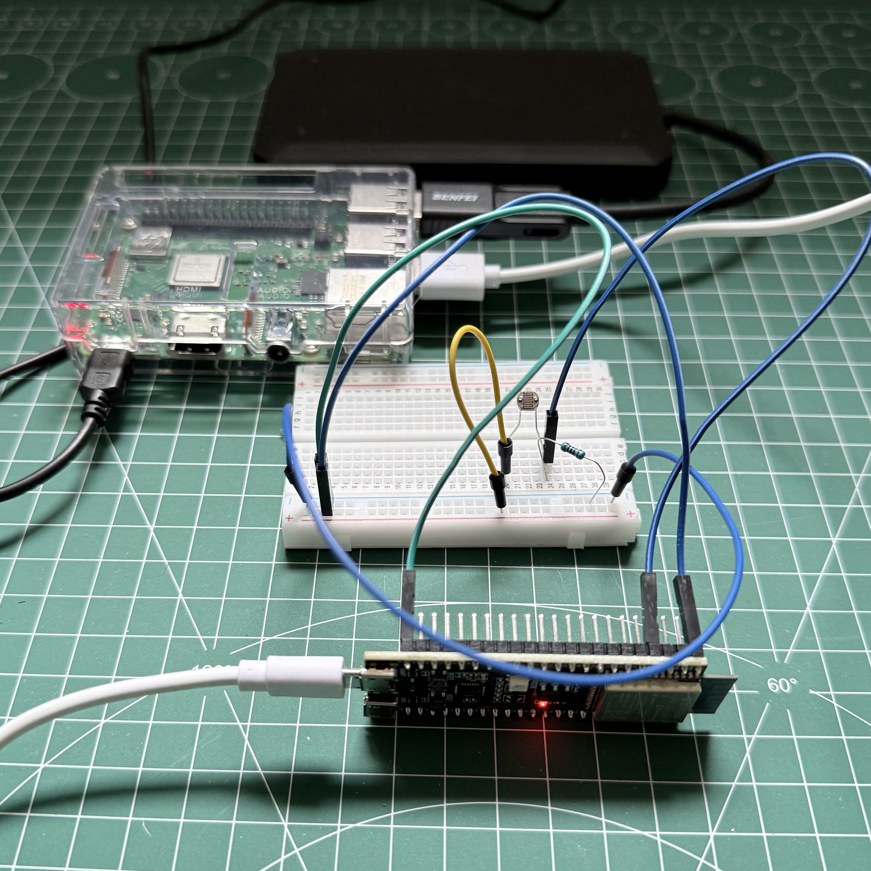
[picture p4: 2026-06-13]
Code/Python/dashboard/creature31may2026.jpg

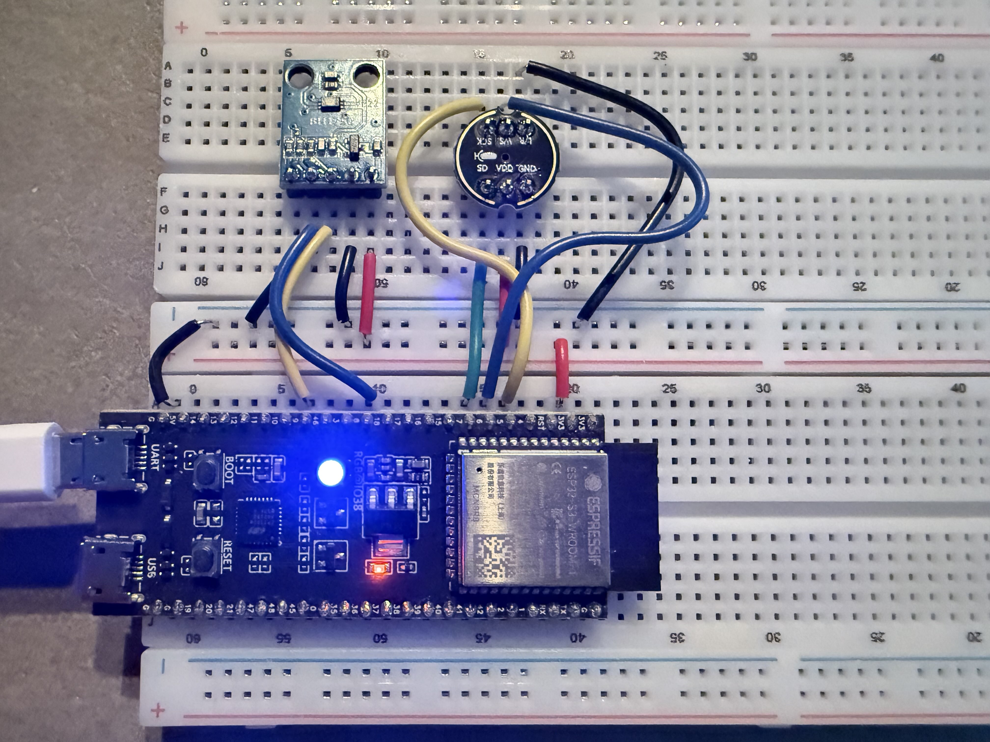
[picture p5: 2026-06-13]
Code/Python/dashboard/creature-v05-2.jpg

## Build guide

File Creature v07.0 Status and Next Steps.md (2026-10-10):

# Creature v07.0: status and next steps

Written 2 October 2026, updated 3 October for the dashboard work, 4 October for
the memory-horizon work, and the evening of 4 October for build v07.0. It is the
handoff for whoever picks this up next. The design itself is in
`Creature Project Design Document Active.md`. This note is the state of things,
what was found, and what is still open. The findings on the real body further down
are still those of 2 October. The newest section is the one for 8 and 9 October,
just below the list of where things are.

Build v07.0 is the v06.9 mind on a body with more on it: two air sensors and an
e-paper readout. Neither is part of the Creature's flow yet. The field, the
gates and the file names (`cell_field_v06.py` and the rest) are unchanged.

## Where things are right now (4 October 2026, 18:35)

- The Pi runs the collector from commit `59fc0fe`, restarted at 18:33 on
  4 October (state loaded from tick 962061). Any commit after that one is a
  correction to this note.
- The collector and the dashboard say `v07.0-predictive`. The body's firmware
  was flashed just before the label changed, so its boot line still says `v06`
  until the next flash. Nothing else differs.
- **Two-speed links are switched on in the live Creature**, from the collector's
  start command, not in the code. A plain restart turns them off. The start
  command is under "Deploying to the Pi" below. Check what is in force with the
  `Two-speed links:` line the collector prints at start, or in
  `/proc/<pid>/environ`.
- The relative expression model is also on, the same way
  (`CREATURE_EXPRESSION_MODEL=relative`).
- A newborn twin runs beside the real field. The present twin was born at the
  08:45 restart on 4 October (real tick 932373) and lives under two-speed links
  too. It was saved and reloaded across the day's restarts.
- The saved field is snapshot version 2. Code from before commit `93b3270`
  refuses it and would start the field fresh. State from before the switch is
  next to the database as `*.pre-twospeed.json` (version 1), and from before the
  twin as `*.pre-twin.json`.
- The body runs the v07.0 firmware, flashed at about 18:10 on 4 October: the
  v06.8 loop firmware plus the air senses, the e-paper, a 30 second WiFi retry
  and its signal strength in the status line.
- The gas index has a learned baseline, saved beside the field state as
  `creature_field_state_air_v06.json`. It began at 17:05 on 4 October.
- The body's WiFi was very weak that evening (see the v07.0 section). By 18:26 it
  was holding: pings of 3 to 6 ms and no reconnects for several minutes.
- The body runs on its battery when its power cable is out: on 4 October the
  battery ran flat at 07:08 and the body was off the network until 08:40. It
  needed the cable and a press of reset. The collector kept retrying and
  reconnected by itself; nothing was restarted for that.
- The speaker is unmuted.
- Check `git status` for anything not committed.

## The light loop is closed: the loop probe, rerun (9 October, 19:16)

The light half of `tools/loop_probe.py` was run on the real body (sound skipped).
The collector was down from 19:14:32 for about two and a half minutes and was
started again with the same eight settings (state loaded from tick 1345515). No
code changed. The report is next to the database as
`loop_probe_20261009_191631.json`.

| Frame (channel value) | Lux added, 9 October | Lux added, 3 October |
|---|---|---|
| white (200) | 240.0 | 0.9 |
| red (200) | 62.6 | 0.33 |
| green (200) | 137.8 | 0.55 |
| blue (200) | 36.5 | 0.08 |
| all four (200) | 410.9 | 1.54 |
| all four (100) | 214.8 | 0.81 |

- The room was at 149 lux with the strip dark, and the sensor's noise was 0.40
  lux. The strongest frame is 822 times the noise. On 3 October it was 22 times.
- The sensor sees the strip about 270 times more strongly than on 3 October.
  Josh: the strip sits at different distances from the sensor at different
  times, and on 9 October it was about 1 to 2 inches away. So the coupling is not
  a fixed number. Nothing may assume a distance; the light model has to keep
  learning it, and these lux figures hold only for this placement.
- Josh does not want the strip flashy in a dark room. As things stand the
  curiosity probe works against that: in a quiet room it lifts the white channel
  by up to 0.35 of the cap in bursts, which at this distance is about 80 lux at
  the sensor, and the inner colour model's 0.6 does not dim it.
- It is close to linear: half the value gives 0.52 of the lux.
- Per unit of channel value: white 1.2 lux, green 0.69, red 0.31, blue 0.18. Green
  counts nearly four times blue. So the inner colour model's turning hue already
  reaches the sensor as a change in brightness, at the same strip brightness.
- At full value the strip adds more light than the whole room (411 against 149
  lux). The room's light sense is therefore partly a reading of the strip itself.
  The swing of about 20 lux from tick to tick, noted on 2 October, is the size an
  ordinary frame would give.

This settles older open item 1 as far as the measurement goes, and makes item 7
due (the design doc and the dashboard legend still say the light loop is open).
Item 2, one weight per pixel for the light model, is now the main thing. Not yet
done: the same probe in a dark room.

## The body sat on a dead WiFi link until reset (10 October, 09:07 to 09:29)

The body went silent at 09:07:44 and stayed away for 22 minutes, until Josh
pressed reset. No ping from the Mac or the Pi in that time. The Pi and the
collector were fine and the collector reconnected by itself at 09:29:43.

What Josh saw before the reset:

- The repeater still listed the body (`esp32s3-85A690`, 192.168.178.91) as
  connected on 2.4 GHz, at the weakest signal step and 5 down / 14 up Mbit/s.
  Earlier that morning it had 26 / 70.
- The board's small light was blinking fast. That light follows the USB serial
  line: the firmware sends its 10 Hz samples there only while no collector is
  connected over WiFi. So the firmware was running normally and knew it had no
  collector.

Reading (not proven; the serial output was not watched): the body and the
repeater both believed they were connected, and nothing was getting through. The
firmware only rejoins WiFi when it sees the link as down (`WiFi.status() !=
WL_CONNECTED`), so it never tried. A reset makes it join afresh, which is why
that worked.

It is not the dark-room rule or anything on the Pi: the body could not be
pinged from the Mac either. Breaks like this are not new (the tick log has some
on every day of the week before), but 10 October had more, after changes to the
repeater's and the router's settings at 08:14 and 08:35 and the repeater
narrowing its 2.4 GHz channel at 08:23.

The Pi's move to the 2.4 GHz band was at 08:13:21, ten minutes before the
body's first break of the morning (08:23:32) and nine and a half before the
repeater narrowed its channel. It cannot have started the trouble: the breaks
at 23:53 and 23:57 the evening before, and those of the week before, came
first. Whether it made the morning worse is open. Since the move, the Pi, the
repeater's link to the router and the body all share the same 2.4 GHz channel.

Josh: this was not a problem before. The tick log agrees, and puts the change
at the v07.0 rebuild of 4 October, not at anything done on 9 or 10 October.
Breaks of 20 seconds to an hour, per day (planned restarts and flashes are in
these counts too):

| Days | Breaks a day | Minutes lost a day |
|---|---|---|
| 20 September to 3 October (12 days of running) | 0 to 2, once 5 | 0 to 14, once 63 |
| 4 to 9 October | 2 to 12 | 6 to 92 |
| 10 October, first 2.2 hours | 3 | 28 |

That is the day the air sensors and the e-paper went on, and the day the
body's WiFi was first measured as very weak (-89 to -95 dBm, see "Build v07.0"
below: the antenna lying flat over the breadboard, or the 3V3 rail feeding more
parts). It was never followed up. On 10 October the repeater showed the body at
its weakest signal step. So the weak link since the rebuild is the root, and
the router's re-tuning and the dead link are what a weak link does. The log
only covers June and from 20 September; June, on the earlier body, had breaks
of its own.

Next for this, in order: log the body's `wifi_rssi`, then move the antenna
clear of the breadboard and the panel and watch the number, then check the 3V3
rail.

The first is done (10 October). The collector now reads `wifi_rssi` from the
body's status line, which comes every two seconds. It is in the live snapshot
as `sensors.wifi_rssi` (dBm; empty when the last reading is over 10 seconds
old) and in a new `wifi_rssi` column of `power_log`, a row every 20 ticks.
Around -60 is good; under -85 is too weak to hold. The dashboard does not show
it yet. Nothing else changed: on the scripted body, seeds 1, 2, 3 and 7, a run
is identical to the code before, and `tools/scripted_body.py --wifi-rssi -70`
makes the scripted body send the status line.

Deployed at 09:48 on 10 October: the Pi runs commit `922b466`, the collector
restarted with the same nine settings (state loaded from tick 1370136, under a
minute down; state from before is `*.pre-rssi.json`). The first readings: -92
and -93 dBm. That is under the -85 the firmware's own note calls too weak to
hold a connection, and the same as the -93 to -95 measured on 4 October. To
read it: `sensors.wifi_rssi` in `/dev/shm/creature/creature_state.json`.

A fix on the body, not built: if the link reads as up but nothing has come
from the collector for a minute or two, rejoin WiFi; if that keeps failing,
restart. It needs a flash. With the Pi down for hours, as on the night before,
it would rejoin WiFi every couple of minutes, which is harmless.

## The Pi lost its WiFi overnight (10 October, 00:53 to 07:52)

The collector's last tick was logged at 00:53:18 on 10 October (tick 1364851),
and the public mirror's last sync was at 00:53:09. From then the Pi answered
neither ping nor ssh from the Mac, while the body still answered pings. Josh's
dashboard page said "server unreachable" (that is the page's own message when
it cannot fetch from the Pi). He rebooted the Pi at about 07:47. The collector
was started again at 07:52 in a new tmux session with the same nine settings
(state loaded from tick 1364800, saved at 00:52; about 50 ticks and seven hours
were lost).

What is known:

- The Pi did not crash or lose power. A systemd timer (`apt-daily-upgrade`) ran
  on it at 06:41, in the middle of the silence. It was running with no network.
- It did not get its WiFi back in seven hours, though the connection is set to
  reconnect by itself. That looks more like the WiFi chip or its driver hanging
  than like a signal that came and went.
- The Pi's WiFi link is weak: -77 dBm on the 5 GHz band (channel 44), sending
  at 12 Mbit/s, measured after the reboot. It is a Pi 3 B+ on WiFi only; the
  ethernet socket is unused.
- There were shorter breaks in the ticks before it: 2 minutes at 18:47 on
  9 October, 4 minutes at 23:53 and 10 minutes at 23:57. Whether those were the
  Pi's link or the body's is not known. The one at 18:47 was before the
  dark-room rule was switched on (20:07).
- The Pi reported under-voltage 18 seconds into the new boot
  (`throttled=0x50000`, `Undervoltage detected!` in the kernel log). Its power
  supply is marginal, at least while booting, with the SSD on its USB.
- The body's battery was fine (4.11 V, 90.7 %) up to the last reading.

What is not known: why the WiFi dropped at 00:53 and why it stayed down. The Pi
keeps its system log in memory only (`Storage=volatile`, the Raspberry Pi OS
default), so that night's log went with the reboot. The router's event log may
show something at 00:53.

The router's event log (FRITZ!Box 7590) has nothing between 21:03 on 9 October
and 07:58 on 10 October, so the router did not drop the Pi; the Pi went quiet
on its own side. A scan from the Pi on 10 October: the 2.4 GHz band reads 65 of
100 (channel 5, with a second access point at 59), the 5 GHz band it was using
reads 42. The body is 192.168.178.91 and the Pi 192.168.178.87.

Nothing points at the dark-room rule: it does not touch the network, and the
Pi itself kept running.

To be ready for the next time (each needs Josh, `sudo` asks for a password):

1. Keep the system log on disk, so the evidence survives a reboot. **Done by
   Josh on 10 October** (`/etc/systemd/journald.conf.d/50-persistent.conf`,
   `Storage=persistent`, at most 200 MB). After a silence, read the hours
   before it with `journalctl -b -1`.
2. Move the Pi onto an ethernet cable, or onto the 2.4 GHz band, which reaches
   further. **Done by Josh on 10 October at 08:13:21** (the Pi's log has it;
   it was back on the network six seconds later): the Pi's connection is
   set to the 2.4 GHz band (`802-11-wireless.band bg`). It reads -62 dBm and
   72 Mbit/s there, against -77 dBm and 12 Mbit/s on 5 GHz. The collector lost
   the body for a few seconds at the switch and reconnected by itself. To undo:
   `sudo nmcli connection modify 'netplan-wlan0-FRITZ!Box 7590 ST2'
   802-11-wireless.band ''`, then bring the connection up again.
3. A small watchdog that restarts the network when the router stops answering.
   It must not reboot the Pi: the collector is started by hand and would not
   come back.
4. A stronger power supply for the Pi.

The last snapshot before the silence, the first seen from a dark room: calm
1.0, the room read at 0.0 lux, the strip credited with 12.1 lux.

What the strip did in that first dark evening, from `loop_log` (the sum of the
four channels' mean values in each frame sent, in ten-minute steps). The room
went dark at about 20:10, three minutes after the rule was switched on, and
stayed dark to the silence at 00:53. Beside it, the dark part of the night
before (23:10 to 00:50 on 8 to 9 October), which had no rule:

| In the dark | 8 to 9 October, no rule | 9 to 10 October, rule |
|---|---|---|
| Strip value, usual | 46 to 70 | 15 to 27 |
| Strip value, highest | 68 to 174 | 30 to 56 |
| Change from tick to tick, usual | 1.1 to 2.2 | 0.25 to 0.6 |
| Change from tick to tick, biggest | 10 to 47 | 2.0 to 3.5 |
| White channel, highest mean | up to 22 | 0 (3 once, near the end) |
| Raw lux at the sensor | 13 to 24 | 2.7 to 8.9 |

In the lit evening before the dark (19:20 to 20:00 on 9 October) the usual
value was 73 to 85 and the biggest change 27 to 107, the same as the night
before. So on the real body the rule did what the gate said. Two limits: the
log holds each frame's channel means, not its pixels, so it cannot show single
pixels switching on and off; and the two nights were not the same room at the
same hours.

What the field did in that dark evening (20:10 to 00:53), from the log tables:

- It did not go quiet. Events on 11 to 17 % of ticks all evening, against 14 to
  16 % in the lit hour before. The room was not still: the sound sense was above
  zero on 14 to 31 % of ticks until midnight, and on 6 to 10 % after.
- Of 159 events, 105 were led by the sound cell (2) and none by the light cell
  (8) or the LED-and-light loop cell (7). In the lit hour before, the light
  cell led 42 of 84. In the dark of the night before, with no rule, the loop
  cell led 10 of 91.
- The light sense read exactly zero from 20:30 on, and felt light was zero on
  every tick. With no rule the night before, felt light was above zero on 16 to
  69 % of dark ticks (small: 0.017 at most on average). So in the dark the
  light loop is silent under the rule. That is the price the gate printed.
- One sleep, at 00:42, 29 ticks, for low stimulation, 4 links pruned. The night
  before had one like it at 22:55.
- The links held: mean weight 1.173 at the start and 1.181 at the end (it
  dipped to 1.094 on the way). The night before they fell from 1.120 to 1.063.
- Energy stayed at 5.8, tones ran at about 25 an hour until midnight and 17
  after. Curiosity proposed 13 light probes after 00:30 as things got quieter;
  none showed on the strip.

So the gate's price (a still dark room becomes a silent hour) was not tested:
there was sound in the room all evening. A still, dark, empty room under the
rule has not been seen yet. The two nights also differ in energy (about 2 on
8 October, 5.8 on 9 October) and the speaker made no tones on the 8th.

The body went off the network at 08:23:29 on 10 October (no ping from the Mac
or the Pi; the collector prints `Reconnect failed`). Its battery read 4.12 V and
91.5 % on the last sample. It came back by itself: ticks stopped from 08:23:32
to 08:27:54 (262 seconds) and again from 08:28:26 to 08:29:47 (81 seconds), and
the collector reconnected each time with nothing restarted. The first break is
the same length as the one at 23:53 the evening before (261 seconds), which
suggests that one was the body too.

The router's log explains this morning's: the repeater, which the body is
joined to, narrowed its 2.4 GHz channel at 08:22:49 and again at 08:23:24
("Wi-Fi transmission quality increased by reduced channel bandwidth"), five
seconds before the body went. Josh had changed the repeater's settings at
08:14. So the repeater dropped the body, not the other way round. What is the
body's own is how long it takes to get back: about four and a half minutes,
both times. Its firmware gives up a join after 30 seconds and starts again
(`WIFI_RETRY_INTERVAL_MS`, `WiFi.disconnect()` then `WiFi.begin()`); with its
weak signal a join may need longer than that, so it may be cutting its own
attempts short. That is a guess until the serial output is watched during a
drop. The router's log shows nothing at 23:53 the evening before.

## A calm strip in a dark room: switched on at the Pi (9 October, 20:07)

Josh does not want the strip flashy in a dark room. `mind/calm_v06.py` (new) is
a rule for that: the darker the room, the dimmer and slower the strip. The
collector applies it when started with `CREATURE_DARK_CALM=1`. It is off by
default.

**It is on at the Pi.** The Pi runs commit `6098dfd`. The collector was
restarted at 20:07 on 9 October with nine settings, the eight from before plus
`CREATURE_DARK_CALM=1` (state loaded from tick 1348495, under a minute down).
State from before the restart is next to the database as `*.pre-calm.json`. To
go back, restart without the setting.

The first minutes on the real body, in a lit room: the rule read the room at
127 to 136 lux and credited the strip with 8 to 17 lux, which adds up to the
raw reading (136 to 162). Calm stayed at 0, so the strip was untouched. **It
has not yet been seen in a dark room.** Read it with the `calm` block of
`/dev/shm/creature/creature_state.json`.

What the rule does:

- It works out the room's own light level. Dark is 3 lux or under, lit is 40 or
  over, judged on a log scale in between.
- In a dark room each frame is shown at 0.35 of its brightness, and the strip
  moves only 0.12 of the way to each new frame per tick. That takes the probe's
  white bursts, the event flash, the shimmer and the pulse down with it.
- In a lit room the frame goes out untouched, the very same numbers.
- Going dark takes hold within about 7 ticks. Coming back takes a little over a
  minute, then eases in over 20 ticks.

How it knows the room is dark with the strip beside the sensor. It learns, from
how the lux reading moves as the frame changes from tick to tick, how much the
sensor sees of the strip (the whole of it, and each quarter), and takes that
light out. It assumes no distance. It counts the strip's light in the steps the
body really shows (the firmware's cap of 40 means a value under 7 shows
nothing). Nothing of it is saved; after a restart it learns again.

`tools/field_lab_v06.py --dark` is the gate: a lit hour, a dark still hour, a
dark busy hour, the light back on; rule against no rule; the strip at three
distances (as on 3 October, as on 9 October, and twice as near again). 15/15 on
seeds 1, 2, 3 and 7. At the distance of 9 October, seed 1, in the body's
brightness steps summed over the strip:

| | No rule | Rule |
|---|---|---|
| Dark and still: strip light | 167.3 | 3.7 |
| Dark and still: biggest change of the strip in one tick | 100 | 16 |
| Dark and busy: strip light | 181.6 | 62.5 |
| Dark and busy: biggest change of the strip in one tick | 148 | 15 |
| Dark and busy: usual change from tick to tick | 9.05 | 1.77 |

The collector on the scripted body (`tools/scripted_body.py`, which gained
`--dark-after N`: the room's light goes out after N seconds), with the Pi's
eight settings, seeds 1, 2, 3 and 7:

- Rule off: everything the Creature did is identical to the committed code
  (commands, every log table, saved files, last snapshot). Only the twin
  differs, and it differs between two runs of the committed code as well.
- Rule on, 15 lit minutes then 30 dark: the lit quarter hour is identical to
  rule off. In the dark the strip's light is 50 against 189, its biggest change
  in one tick 10 to 15 against 171 to 177, its usual change 2.0 against 12.1.
- With the rule on the live snapshot gains a `calm` block (`calm`, `room_lux`,
  `own_lux`). The dashboard does not show it.

It took five designs, and the failures are worth keeping:

1. The room's level from the lowest reading of the last minute alone. 7 of 14.
   With the strip close, its own light made a dark room read as lit.
2. One weight per pixel, each corrected a little every tick. Better, but it let
   go of the dark for half a minute when the strip woke, because it counted the
   values sent and not the steps the body shows.
3. A creature started in a dark room stayed calm, so its strip barely moved, so
   it learned too slowly. Learning from smaller frame changes fixed that.
4. That passed the lab gate, with a safety margin that only worked in a narrow
   band. Then the collector on the scripted body showed it was wrong: in a room
   whose light drifts up and down, correcting every tick chases the drift. It
   credited the strip with 41 to 58 lux against a true 9 and went fully calm in
   a 54 lux room. The lab gate's rooms did not drift like that.
5. Now it gathers evidence over many ticks and solves for the best fit, with
   the slow drift taken out first. On the scripted body its guess of the
   strip's light is off by 1.1 lux on 7. The safety margin (the strip is
   credited 0.15 over what was learned) is no longer delicate: 0.15 and 0.3
   both pass; with none, a creature started in the dark at the nearest distance
   lets go now and then.

The price, which the gate prints and does not judge. In a still dark room with
the strip close, the Creature without the rule keeps stirring itself with its
own light: events on 10 to 16 % of ticks, mean arousal about 0.33. With the
rule that hour is quiet: no events, arousal 0.07, a little more sleep, and the
links end lower (0.61 to 0.68 against 0.78 to 0.92). That is the same quiet a
dark room had for the whole of the Creature's life before the strip sat close;
against a far strip with no rule the links end slightly higher (0.56 to 0.59).
The light loop stays closed in a lit room.

Two things I changed in the gate after seeing numbers, so they are not hidden:
one pixel may change by up to 4 of the body's steps in a tick (first set at 2;
it reaches 3 in the busy dark against 35 without the rule), and "not harmed"
uses the `--curious` gate's bar of full arousal on under a tenth of ticks (it
reaches 5.4 % on seed 3).

The collector prints a `Dark-room calm:` line at start.

Not done, in order:

1. The real strip has not been watched under the rule in the dark. There most of its
   values fall to 0 to 2 of the body's steps, so single pixels may be seen
   switching on and off. The real sensor's readings also come in steps of 0.83
   lux and with the BH1750's lag; the scripted body has both, the lab gate
   neither.
2. The lab gate has no room with drifting light. It should get one, since that
   is what caught design 4.
3. The rule learns its own picture of what the sensor sees. The forward model's
   light part needs the same thing (older open item 2). They should become one.
4. The brightness swing as expression (Josh's question that started this) would
   sit inside this rule: full depth in a lit room, nearly still in a dark one.
5. The dashboard could show the room's level and how calm the strip is.

## The speaker's own noise, the e-paper, and a collector crash (8 and 9 October)

Where it stands at 09:16 on 9 October: the Pi runs commit `3234e34`. The
collector was restarted at 09:16 with the same eight settings as before (state
loaded from tick 1316254, six minutes down). The body runs the firmware flashed
at about 15:20 on 8 October. The speaker is unmuted. The flashing cable is out
of the Pi. State from before the restart is next to the database as
`*.pre-probefix.json`.

**The amp makes loud noise by itself. Open, and the first thing to fix.** Twice
on 8 October the speaker sounded without the Pi or the firmware asking for it.

- 02:42:28: the body's microphone went from quiet to near the top of its range
  within one second, stayed there for 2 seconds, then about 48 seconds of ragged
  loud sound, between half and three times the level of a normal tone. It
  stopped by itself at 02:43:18. Josh, woken by it, heard random loud noises,
  quick and messy. He muted the speaker at 02:43:05 and pulled the power and the
  flashing cable by 02:44:12.
- 16:54:40: one loud second. Josh heard an alarm-like sound, loud and rising in
  pitch, and pulled the power at once. The speaker had been muted since
  15:44:06.
- Neither was a tone. The Pi logs every `VOX:` it sends: the last one before the
  first event was at 00:07:57, and before the second at 15:43:52. While the
  firmware plays a tone it stops sampling, so a tone's second holds 4 to 6
  readings; every second of both events holds the full 10. The firmware can
  only play a fixed pitch, not a rising one. The body did not restart either
  time. So the mind, the open palette and the tone code are ruled out.
- What the two share: the charger was in, and the flashing cable from the Pi to
  the ESP's UART socket was in (from 20:55 on 7 October to 02:44, and from 15:14
  to 18:19 on 8 October). The first night was the first one with that cable
  left in. The Pi's kernel log has no USB event at either moment and nothing on
  the Pi had the serial port open, so it was not a command over serial. The
  cable does give the body a second 5 V feed and a ground path through the Pi's
  hub. During the first event the cell's voltage dipped 50 mV. At the first
  event the charger had levelled off at 4.18 V, 92 %, a few minutes before.
  Whether the cable is the trigger is not shown: two events are not proof.
- Why the amp can do this: its shutdown pin (SD) is left floating, so it is
  always on, and it runs straight from the 5 V rail on a breadboard
  (`Hardware/Creature v06/WIRING v06.md`). Anything on that rail or on its
  three signal wires comes out of the speaker at full gain.
- Next: keep the flashing cable out except while flashing, and see whether the
  noise returns. The fix either way is to wire SD to a free GPIO with a
  resistor to ground, and have the firmware switch the amp on only while a tone
  plays. One wire, one resistor, a small firmware change. Not done.
- Also unexplained: the sound that woke Josh came with no warning in the record,
  and a hit of the same size at 16:48:03 may have been the amp or a hand on the
  board.

**The open palette's first evening.** Between 22:00 and midnight on 7 October it
sent about 20 tones an hour, up to 750 Hz, against about 10 an hour on the
nights before. After 00:07:57 it sent none until the event at 02:42, with the
speaker unmuted. Why it went silent is not looked into.

**The e-paper went blotchy.** Text that had not changed faded to grey while
digits that had just changed were full black. That is the partial refresh: only
changed pixels get a proper push, and the rest drift toward grey with each pass.
`PAPER_FULL_EVERY` in the firmware went from 10 to 3, so a full refresh comes
every 9 minutes, not every 30 (commit `3234e34`). Flashed at about 15:20 on
8 October, built from a scratch copy on the Pi. The body did not rejoin WiFi
after the flash, as before; a reset over the serial line and a minute's wait
brought it back at 15:23. The collector was left running and reconnected by
itself. Not yet judged on the panel. The photo was taken at a charge of 5 %,
and a low cell may add to the grey; that is not separated out.

**The collector crashed on its first probe tone under the open palette.** At
09:09:59 on 9 October: `TypeError: 'NoneType' object is not callable` in `send`.
The palette commit (`92d3ecc`) made the probe tone call the function
`voice_command`, while a few lines above the same name was a local variable,
empty in exactly that case. It took a day and a half to happen because a probe
tone needs the speaker unmuted, the field silent, and curiosity choosing a
voice probe. The local is now `field_command` (commit `6b1ce10`). Checked on the
Mac with a stand-in transport: the probe tone goes out as `VOX:450.0,300,0.40`.
No probe tone had come up on the Pi when this was written. The collector saved
its state as it fell, so nothing was lost but the six minutes. Neither
`field_lab` nor `scripted_body` caught it; a scripted run with the speaker
unmuted and a forced voice probe would have.

**The battery ran down again overnight.** With the power out since 16:55 on
8 October the cell reached 3.31 V at 01:58 on 9 October, and the body sent
nothing until 07:58, when it was charging again. That is where the low-battery
reflex puts the body to sleep (3.30 V), but whether it slept or simply lost
WiFi was not checked.

## The battery gauge, step 1 (6 October)

Deployed on 6 October 2026 as commit `0f5b5ec`. The Pi was fast-forwarded, the
body flashed at 21:10, and the collector restarted at 21:11 with the same five
settings as before (state loaded from tick 1142866, about two minutes down). The
dashboard service was restarted for the `server.py` change. State from before
the restart is next to the database as `*.pre-battery.json`.

- **A MAX17048 fuel gauge on the body's I2C bus** (address 0x36), in line between
  the LiPo and the PowerBoost. The firmware reads three registers once a second
  and adds `battery_v`, `battery_pct` and `battery_rate` (percent per hour,
  negative while discharging) to its sample lines. No library: raw I2C, like the
  IMU. If the gauge stops answering, the keys drop out and the body looks for it
  again every 10 seconds. The start line carries `gauge_ready`.
- **The collector passes it through.** The three readings go into the snapshot's
  `sensors` block and a new `power_log` table, one row every 20 ticks. When the
  body stops sending them the collector shows nothing rather than the last
  charge.
- **The e-paper** shows `Batt 84%` (with `chg` while charging) on the line that
  held `Emit`, when the body has a gauge. Without one the line is `Emit` as
  before.
- **The dashboard's sensor panel** has a battery tile: charge, a word (charging,
  discharging, steady), cell voltage, charge rate and a line of the last six
  hours from `/api/power_history`.
- `tools/fake_body.py` sends a made-up cell that drains for ten minutes and
  charges for two.

What was checked:

- On the body: the I2C scan finds six devices and the gauge answers. Its first
  readings were 4.187 V, 92.8 % and +16.6 %/hr with the charger in. The body
  joined WiFi after the flash without a reset, at -90 dBm. `/api/sensors` and
  `/api/power_history` on the Pi return the readings.
- The Creature is unchanged. `tools/scripted_body.py`, the committed collector
  against the changed one, seeds 1, 2, 3 and 7, 1800 seconds: every command,
  every table and every saved file identical, apart from the new empty
  `power_log` table and the new snapshot keys. With a battery added to the
  scripted samples, the only further differences were the `EPD:` lines and the
  `power_log` rows.

This is step 1 of three. Step 2 is the battery setting the field's energy
income, which needs a gate (a scripted drain and recharge, seeds 1, 2, 3 and 7).
Step 3 is a low-battery reflex on the body. Open from this step: `power_log` has
no retention (4,320 rows a day, like `air_log`); the `chg` threshold of 0.5 %/hr
and the tile's 20 % low mark are first guesses; the gauge's charge rate is known
to settle slowly, so how fast it shows a plug-in is not measured. The e-paper's
`Batt` line has not been looked at on the panel.

## The battery, step 2: the charge sets the reserve's ceiling (7 October)

Deployed on 7 October 2026 as commit `07c4add`. The collector was restarted at
12:43 with `CREATURE_BATTERY_CEILING=1` added to its settings (state loaded from
tick 1198759). No flash and no dashboard restart. State from before the restart
is next to the database as `*.pre-ceiling.json`. At that moment the cell read
5.2 %, so the ceiling started at its floor: reserve 1.3 against a ceiling of
1.5. The charger went back in at about 12:43.

The first real discharge record: the charger came out at about 07:35 on
7 October at 94.7 %. The gauge fell at about 14 % an hour down to 55 %, then
faster, about 25 % an hour, reaching 5 % at 12:40: five hours in all. The cell
was still at 3.61 V at 5 %, and the body was still running.

With the ceiling at its floor, memory pressure rose from about 0.34 to 0.40,
because the reserve's level is a small part of it. Its highest in the 72 hours
before was 0.36, and the sleep threshold is 0.58.

What was built:

- `mind/cell_field_v06.py`: `field.step()` takes the battery charge. With
  `CREATURE_BATTERY_CEILING=1` the reserve's ceiling is the charge as a share of
  its maximum, never under a quarter (`BATTERY_CEILING_FLOOR`). Off by default.
  The metabolism block has a new `energy_ceiling`.
- `mind/expression_v06.py`: the energy gate now scales the whole strip frame as
  well as arousal. With a healthy reserve the gate is 1 and nothing changes.
- `mind/twin_v06.py` and the collector: the same charge goes to the field and to
  the twin. The collector prints a `Battery:` line at start.
- `tools/field_lab_v06.py --battery`: the gate.

What was found:

- Scaling the refill rate, the design first proposed, fails. Nothing happens
  down to a third of normal income, then expression goes fully dark, the field
  sleeps every four minutes and the links are wiped.
- A ceiling under about 18 % makes the field sleep every 240 ticks from low
  energy, and that much replay drives the links up (mean 0.46 to 1.0 in two
  hours), under the Pi's two-speed settings as well. Hence the floor.
- Arousal carries little of the strip's light. With the gate on arousal alone
  the strip lost 13 % of its light when arousal halved; the first run of the
  gate failed on that.

What was checked:

- `--battery` passes 7/7 on seeds 1, 2, 3 and 7, and on seed 1 under the Pi's
  two-speed settings. Strip light is about 83 % of the control's at 35 % charge
  and 40 % at 10 %; arousal about half at the floor; all back to 100 % once
  charged. The field itself is identical to the control on every tick.
- `--voice`, `--twin` and `--events` pass as before. `--express` fails 8/9 both
  before and after this change.
- The collector on the scripted body with a draining battery, seeds 1, 2, 3 and
  7: with the setting off, identical to the committed code apart from the new
  `energy_ceiling` key. With it on, the strip is sent 40 % of the control's
  light at the end, and because the loop is closed the field's life differs a
  little (largest link gap 0.025 after 30 minutes, about 5 % fewer events, no
  sleeps, the same tones).
- The live reserve has not been under 5.78 in the last 72 hours, so the strip
  change does nothing on the Pi until the ceiling is switched on.

The run to flat, 7 October. The charger came out again at 13:13 with the gauge
at 15.7 % and the cell ran until the body went silent at 18:23, five hours and
ten minutes later:

- The gauge's percentage is badly skewed at the bottom. It fell to 2 % by 14:30
  (3.59 V) and then crawled for nearly four hours while the body ran normally.
  With the morning's run, the gauge reached 5 % about half-way through the
  cell's real running time.
- The voltage is the usable signal. It slid slowly from 3.65 V to 3.42 V over
  four hours, then fell off: 3.35 V at 17:58, 3.2 V at 18:11, 3.0 V at 18:17,
  and the last reading was 2.386 V at 18:23:30. From 3.4 V there was about
  55 minutes left, from 3.3 V about 20, from 3.2 V about 12.
- Nothing stopped the discharge until about 2.4 V, which is the cell's own
  protection and well below the 3.0 V a LiPo should not go under. Running to
  flat harms the cell and should not be repeated.
- The body streamed and held WiFi to the end. The collector went to
  `Reconnect failed` and kept retrying.

Open from this step:

1. The dimming has not been watched on the body. Whether a dimmer strip
   measurably slows the drain is not known.
2. A drained Creature does not rest or sleep more, and learning does not slow.
   That needs a low-energy sleep that does not rewrite the links.
3. The voice is as loud at low charge as at full.
4. The floor of a quarter and the gate's 40 % knee are not tuned against the
   real body. Where the body actually cuts out, in percent, is not yet known.
5. The gate's day scenario has no sleeps in it, so "no sleep from a low reserve"
   rests on the reserve's lowest level (1.30 against a threshold of 0.9).
6. Step 3, the low-battery reflex on the body, is built but not flashed (see its
   own section).
7. The reserve's ceiling followed the gauge's percentage, so the Creature was at
   its dimmest for roughly the second half of the cell's real running time. The
   voltage version is built (see its own section).

## The ceiling follows the cell's voltage (7 October, evening)

Deployed on 7 October 2026 as commit `84264ba`. The collector was restarted at
19:31 with the same six settings (state loaded from tick 1220908, under a minute
down). No flash and no dashboard restart. State from before the restart is next
to the database as `*.pre-voltage.json`. With the cell at 3.58 V on the charger
the reserve went from 1.3 (the percentage version's floor) to 2.2 against a
ceiling of 2.4.

- `mind/cell_field_v06.py`: `field.step()` takes `battery_v` in place of the
  charge in percent. The field smooths it over about two minutes
  (`BATTERY_SMOOTH_TICKS`) and reads the ceiling from `BATTERY_CEILING_CURVE`:
  whole at 3.80 V and above, 43 % at 3.60 V, the floor of 25 % at 3.45 V and
  below. A gap in the readings keeps the last voltage for ten minutes.
- The collector and the twin pass the voltage. The start line now reads
  `Battery: the cell's voltage sets the energy reserve's ceiling, ...`.
- The gate is rewritten in volts, with a noisy gauge and a minute of no
  readings. It passes 9/9 on seeds 1, 2, 3 and 7 and under the Pi's two-speed
  settings. `--voice`, `--twin` and `--events` pass as before.
- The collector on the scripted body, seeds 1, 2, 3 and 7: with the setting
  off, identical to the committed code. With it on and the cell falling from
  4.05 V to 3.35 V, the strip is sent 40 % of the control's light at the end;
  largest link gap 0.010, up to 6 % fewer events, no sleeps.

The curve's three points are read from one discharge under the body's load. The
cell reads about 0.15 V higher on the charger, so the Creature brightens within
a couple of minutes of being plugged in and dims the same way when the charger
is pulled below about 3.75 V.

## The voice: an audition tool (7 October, late evening)

Written late on 7 October. Not committed and not flashed when written.

Josh finds the beeps classic but not expressive. The voice today is one pure
sine tone, pitch from balance over 220 to 440 Hz, length from tempo, volume
fixed. The speaker is three to four times weaker below about 325 Hz, so the
lower half of that range barely sounds.

- Firmware: `VOX:` takes four more optional numbers, `attack_ms,release_ms,h2,h3`.
  A release over 20 ms dies away on a curve, which is what makes a pluck. With
  overtones the whole is scaled so its peak stays in the amp's clean range, so
  the fundamental is quieter. Without the extra numbers the tone is sample for
  sample the old one. It compiles on the Mac.
- `tools/voice_audition.py` (new), run from the Mac with the collector stopped:
  `sweep` (the speaker from 300 to 1905 Hz, a third of an octave apart, with
  what the body heard of each), `shapes` (beep, pluck, swell, soft, bell),
  `tones` (pure, then with overtones) and `one` (any single sound). Tried
  against `fake_body.py` only.
- Nothing in the mind is changed: the Creature still sends plain beeps.

The body was flashed with this at 20:58 on 7 October (commit `b7c5dc4`) and the
collector restarted at 21:02 with its seven settings. The sweep on the real
speaker, volume 0.70, what the body heard at each pitch: 300 Hz 7,900; 378 Hz
28,900; 476 Hz 94,200; 600 Hz 100,900; 756 Hz 195,800; 952 Hz 333,100; 1200 Hz
241,600; 1512 Hz 229,400; 1905 Hz 172,300. Josh listened to the shapes and
overtones and chose: fewer beeps, more swells and soft tones, a mix of
overtones, and the top half only very lightly because it is piercing.

The open palette, built the same evening and deployed as commit `92d3ecc`: the
collector was restarted at 21:24 with `CREATURE_VOICE_PALETTE=open` added, eight
settings in all (state loaded from tick 1226624, under a minute down; no flash).
State from before the restart is next to the database as `*.pre-palette.json`.
No tone had been heard under it when this was written. What was built:

- `mind/expression_v06.py`: `CREATURE_VOICE_PALETTE=open` (default `beep`,
  unchanged). Five main notes from 450 to 750 Hz, three light high ones, swells
  and soft tones, overtones from the strip's hue, balance and tempo read against
  its own last 32 tones.
- `mind/forward_model_v06.py`: the pitch bands follow the palette, and the model
  is told a tone's `level`. The saved file gains `pitch_low` and
  `pitch_octaves`; bands learned over the other range start fresh.
- `mind/curiosity_v06.py`: under the open palette a probe is a soft tone and
  keeps under 800 Hz.
- The collector sends the longer `VOX:` line and prints a `Voice palette:` line.
- `tools/fake_body.py`, `tools/scripted_body.py` and the lab's simulated speaker
  follow the sweep above 440 Hz and scale what is heard by a tone's level.
- `tools/field_lab_v06.py --palette` is the gate: 9/9 on seeds 1, 2, 3 and 7.
  Its first run failed (three tones in four high, no swells), which is why
  balance and tempo are read against its own past tones. `--voice`, `--colour`,
  `--battery`, `--twin`, `--forward`, `--curious` and `--feel` pass.
- The collector on the scripted body, seeds 1, 2, 3 and 7: with the default
  palette, identical to the committed code apart from the two new keys in the
  forward model file. With `open`, an hour: the same number of tones, the
  largest link gap 0.013, the sound model explaining 0.84 against 0.73.
- A mistake caught by the twin gate: a start-up print in the collector used a
  name that does not exist there, and the collector crashed at launch.

Open from the palette: the light notes are at volume 0.40, below the 0.65 to
0.90 the bench notes call the amp's clean range, and have not been heard. The
Pi's sound model has learned 220 to 440 Hz and will start its bands again. The
shapes have only been heard in the audition, not as the Creature uses them.

Also open: the body's measure of its own tone listens at the fundamental across the
whole tone. A pluck or an overtone mix will read quieter there than a beep of
the same volume, which matters once the mind sends them and the sound model
learns from the result.

## The strip's colour: the inner model (7 October, late evening)

Deployed on 7 October 2026 as commit `f2d7fd5`. The collector was restarted at
20:48 with `CREATURE_COLOUR_MODEL=inner` added to its settings, seven in all
(state loaded from tick 1224805, under a minute down). State from before the
restart is next to the database as `*.pre-colour.json`. A minute in, the frames
it sent were magenta to violet, the hue turning from 292 to 312 degrees in 15
seconds, the W channel at 0. To go back to the blend, restart without the
setting.

Josh found the strip's bright white annoying and asked for more varied colour
that is still the Creature's own expression, at about a third of the brightness.

- Why it was white: the blue-to-orange blend passes through grey-white in its
  middle, where the field mostly sits. The W channel was nearly off.
- `mind/expression_v06.py` has a second colour model, `inner`, behind
  `CREATURE_COLOUR_MODEL=inner` (default `blend`, unchanged). The reservoir
  pushes one hue around the colour wheel; the hue leans warm or cool along the
  strip; brightness still follows activity; the frame is at 0.6 of the blend's
  scale. The expression block of the snapshot gains `hue`.
- `tools/field_lab_v06.py --colour` is its gate: 9/9 on seeds 1, 2, 3 and 7.
  `--voice`, `--battery` and `--twin` pass as before; `--express` fails 8/9 as
  before.
- `tools/strip_swatch.py` (new) puts a fixed test palette on the real strip. It
  needs the collector stopped.
- The collector on the scripted body, seeds 1, 2, 3 and 7: with the default
  model, identical to the committed code. With `inner`, 39 % of the blend's
  light and no white; and because that body's light sensor sees the strip
  strongly, 30 to 50 % more events and a largest link gap of 0.08 after 30
  minutes.

Open:

1. It has not been seen on the real strip. The firmware's own brightness cap
   (40 of 255) leaves only about ten steps per channel at this brightness, so
   colours may look coarse.
2. How much the real light sensor sees the colour changes is not known. If it
   sees them well, the field will mark more events.
3. The rate (1.5 degrees a tick), the lean (50 degrees) and the brightness (0.6)
   are first choices, to be set by eye.
4. The hue starts again at red after every restart.

## The first real run of the whole chain (7 October, 19:36 to 20:22)

The charger came out at 19:36 after about half an hour of charging, and the body
was left to run down:

- 19:36: the cell read 3.59 V on the charger and 3.45 V the moment it was out.
  The reserve followed the smoothed voltage down from 2.27 to its floor of 1.29
  in about six minutes, with no jumps, on readings that bounced by 20 to 30 mV.
- 19:47: the cell reached 3.40 V. Whether the body's strip cap came on is not
  known: the readings hovered either side of 3.40 V, the collector does not
  record the body's `battery_low` line, and nobody was watching.
- 20:12: the body slept at 3.30 V (last reading 3.296 V at 20:12:29), 25
  minutes after 3.40 V. The strip was dark and the e-paper read "Battery low /
  3.30 V / Asleep" and "Plug in the charger", both inside their columns.
- Asleep, the power LEDs on the gauge, the SGP41, the IMU and the ESP board
  stayed lit: the 3.3 V rail is up and the sensors still draw from the cell.
- The charger went back in at about 20:20. The body woke at 20:22:48, within
  one or two looks at the gauge, reading 3.607 V and +11.2 %/hr. It booted,
  joined WiFi and the collector reconnected, with no reset.
- After the ten minute gap the reserve stayed at the floor for a couple of
  minutes while the smoothed voltage caught up.

## The battery, step 3: the low-battery reflex on the body (7 October)

Deployed on 7 October 2026 as commit `3054a49`: the body was flashed at 19:11 and
the collector restarted at 19:14 with the same six settings (state loaded from
tick 1219923, about four minutes down).

Tested on the body over serial with the `BAT:` command, charger in:

- `BAT:3.35`: the strip cap came on after 10 seconds (`strip_cap` 12).
  `BAT:3.55`: it lifted one second later.
- `BAT:3.25`: the cap after 10 seconds, `battery_sleep` after 30. The body was
  silent for 68 seconds, looked at the gauge three times (`battery_woke` 3: two
  on the test voltage, then the real cell, which was charging), booted and
  joined WiFi by itself at -87 dBm. No reset was needed.

After the run to flat the charger went back in and the body came back at 18:58,
35 minutes after its last reading. For its first half minute the gauge answered
with 0 V and 0 %, which the body streamed as readings.

What was built, all in `Code/Firmware/esp-creature-core/src/main.cpp`:

- A reading outside 2.0 to 4.6 V is no longer streamed or acted on.
- At or under 3.40 V for 10 seconds (and not charging): the strip's brightness
  cap drops from 40 to 12. It lifts above 3.50 V or on the charger. The body
  sends a `battery_low` and a `battery_ok` system line.
- At or under 3.30 V for 30 seconds (and not charging): strip and status pixel
  dark, "Battery low" drawn on the e-paper in full, the CO2 sensor stopped, a
  `battery_sleep` system line, then deep sleep.
- Every 5 minutes it wakes, reads the gauge before anything else, and sleeps
  again unless the charge rate is above 2 %/hr or the cell is at 3.60 V or
  more. The start line carries `battery_woke`, the number of looks it took.
- `BAT:<volts>`: a bench test. The reflex acts on that voltage for two minutes;
  a test sleep is two 20 second steps and then the real cell decides.

Not known:

- The strip cap has been seen as a system line on a test voltage, not looked
  at. The sleep and the wake have since run on a really low cell (see the
  section above).
- At 18:58 the body came back by itself when the charger went in, with no
  reset (the reset of 4 October was not needed this time).
- How much the body draws asleep. The PowerBoost, the strip's idle current and
  the sensors stay powered, so a sleeping body still drains the cell, slower.
- Whether a cell asleep at 3.30 V rebounds far enough, with no charger, to pass
  3.60 V and wake the body, which would then sag and sleep again.

## Build v07.0: air senses and e-paper (4 October)

What was added, in the order it was built:

- **Two air sensors on the body's I2C bus.** An SCD41 (CO2, temperature,
  humidity, address 0x62) and an SGP41 (VOC and NOx, address 0x59). The body
  reads them once a second and adds `co2_ppm`, `air_temp_c`, `humidity_pct`,
  `voc_raw` and `nox_raw` to its sample lines. The SGP41's 50 ms measurement is
  spread across passes of the loop, so the loop does not wait for it.
- **The gas index.** The SGP41's counts are resistances, not concentrations (the
  VOC count falls with more gas, the NOx count rises). `mind/gas_index.py` is a
  plain-Python port of Sensirion's Gas Index Algorithm 3.2.0. The collector runs
  it once a second: VOC 100 is this room's normal, NOx 1 is normal. Its baseline
  is saved every 100 ticks and at exit, and taken back at start if it is under
  12 hours old.
- **An `air_log` table**, one row every 20 ticks, with the five raw readings and
  the two indexes.
- **The dashboard's sensor panel** shows CO2, humidity, the CO2 sensor's
  temperature, and the VOC and NOx index, each with a line of its last hour. The
  index tiles carry a word (normal, raised, high) and the raw count underneath.
  `/api/sensors` has the new readings and `/api/air_history` the rows. The panel
  is local only, as before.
- **An e-paper readout on the body.** A Waveshare 2.13inch e-Paper HAT V4 on the
  ESP's free edge. The collector sends an `EPD:` line of ten short strings every
  180 ticks, and once 10 ticks after it starts. The left column is temperature
  in F and C (the BME280's), humidity, CO2, VOC index and NOx index. The right
  is energy, memory pressure, emitter, cell states and live links. The body only
  draws the text. The panel has a task of its own on the ESP's second core.

What was checked:

- The port against Sensirion's own C, compiled on the Mac, on 40,000 scripted
  samples. NOx matched on every sample. VOC differed by 1 on 84 samples and never
  by more. A save and restore mid-run changed nothing.
  `python tools/gas_index_check.py` repeats it against stored reference values.
- The Creature is unchanged by any of it. `tools/scripted_body.py`, the committed
  collector against the changed one, seeds 1, 2, 3 and 7: every command to the
  body, every table and every saved file identical, apart from the new `air_log`
  table, the new snapshot keys and the `EPD:` lines. The `--twin` gate passes
  6/6. The twin's own numbers differ between any two runs, with or without a
  change, so they are left out of that comparison.
- On the body: all five I2C addresses answer. A full e-paper refresh takes 3.6
  seconds and a partial one 0.5. While the panel drew, the largest gap between
  samples was 103 ms, the normal spacing.

What was found:

- **The body's WiFi signal is very weak.** A diagnostic sketch measured the home
  network at -93 to -95 dBm at the body and saw only one or two networks at all.
  One join took 15.7 seconds and the next failed after 25. The firmware used to
  restart the attempt every 10 seconds, which cut slow joins off; it now waits
  30. With that it joined at -89 dBm, then dropped three times in five minutes,
  one of them a connection reset by the body. After that it held. The cause is
  not established. The two candidates are the antenna (it lies flat over the
  breadboard, with the amp and new jumpers close by) and power (the 3V3 rail now
  feeds more parts). The body had joined in 4 seconds earlier the same day.
- After a flash the body often does not join WiFi until it is reset, sometimes
  twice.
- The CO2 sensor's temperature and humidity read about 3 C warm and 8 % dry for
  the first minutes after a boot, then settle near the BME280's.
- The dashboard service needs a restart when `server.py` changes. `sudo` on the
  Pi asks for a password; the service runs as `josh` with `Restart=always`, so
  stopping its process brings it back in about five seconds.
- A mistake worth remembering: a collector change crashed at its first tick
  under the scripted body, and the comparison reused the previous run's output
  files and looked clean. Delete old outputs and check the exit code.

Open from this build:

1. The weak WiFi. The status line now carries `wifi_rssi`, but only on the wire:
   the collector does not log it. Watch the serial output with the UART cable in,
   move the antenna end clear of the breadboard, and see what the number does.
   Check the 3V3 rail with a meter while the panel refreshes and WiFi transmits.
2. The air senses are not part of the Creature. Whether they should be, and
   where they would enter the ring, is a design question, and any answer needs
   its own gate.
3. The loops have not been measured on the real body since the air sensing and
   the panel task were added. This joins item 1 of the older list: rerun the
   loop probe.
4. The words on the index tiles (VOC raised at 150, high at 250; NOx at 20 and
   150) and the 12 hour limit on a saved baseline are first guesses.
5. `air_log` has no retention. It grows by 4,320 rows a day.
6. Whether every e-paper line fits its column has not been confirmed line by
   line. The panel redraws every three minutes, Waveshare's recommended minimum.
7. The NOx index needs about five hours from a fresh baseline before it means
   much.

## The memory-horizon work (3 and 4 October)

The brief is `Claude Code brief - memory horizon.md`. Its three steps are done.
The numbers and the reasoning are in the design doc, under "Two-speed links",
"The newborn twin" and the gate table.

The problem. The Creature learns, but a newborn field fed the same recorded day
becomes indistinguishable from the ten-day-old one in about a day. The memory
horizon is how long that takes. It is the number any change to the mind is now
judged by.

| Step | What it added | Commit |
|---|---|---|
| 1 | The history gate (`--history`): measures the horizon, changes nothing | `d6634f4` |
| 2 | The newborn twin in the collector, the `--twin` gate, `tools/scripted_body.py` | `8ef5533` |
| 3 | Two-speed links, off by default, snapshot version 2 | `93b3270` |
| | Slow leak, ceiling knee, a stricter `--compare` verdict | `2abb17f` |
| | Environment switches for the two-speed setting | `2d889b2` |

What was found.

- Today's mind, on recorded senses: horizon 24 to 26 hours. It needs a 72-hour
  test window (`--history-hours 72`); at 24 hours the answer flips with the seed.
- On the synthetic day the control never converges, so the horizon is judged on
  recorded senses only.
- Two-speed links as first written could never forget: nothing pulled the slow
  weight down. The leak fixed that. The ceiling as first written braked growth
  over the whole range; the knee fixed that.
- The setting that passes the gate, and that is live now: `SLOW_MIX=0.25`,
  `SOFT_CEILING=True`, `CEILING_KNEE=1.0`, `SLOW_LEAK=4.13e-7`. The horizon goes
  from about a day to more than 72 hours, the longest the recording can show. It
  is the fifth setting tried on one recording, so it is fitted to it to some
  degree, and the newborn learns about a quarter less in its first hours.
- The live baseline, under today's mind: the first twin lived 15 hours 54
  minutes (3 October 15:19 to 4 October 08:45, less the battery gap). Eight of
  twelve links came within 0.09 of the real field's. What stayed apart was
  around cell 7, the LED-and-light loop cell: the real field feels the loop and
  the twin does not. The expression gap settled at 0.05 to 0.07. That twin's
  field is kept as `creature_field_state_twin_v06.baseline.json`.
- So the twin's single "largest link gap" figure measures the loop once the
  twin has caught up, not history.
- After a collector restart the field marks almost no events, and so voices
  nothing, for 5 to 10 minutes. Seen at three restarts. The cause is not
  established.

Open, in the order I would take them.

1. Read the two-speed twin against the baseline at the same ages. Rows are in
   the `twin_log` table, one a minute; the two twins are told apart by
   `twin_age` starting again from zero at tick 932373. Under two-speed links the
   gap should still be clearly open at 16 and at 24 hours.
2. Log each of the twin's link weights once a minute, so the gap can be read on
   the links away from the two loop cells (1 and 7). Offered, not built. Without
   it the comparison in item 1 is hard to read.
3. Find out why events stop for some minutes after a restart. One candidate: the
   event rule's running median (`event_usual`) is not saved.
4. `SLOW_RATE` (the week) has no environment switch and has never been run at
   another value. It is the knob that sets how long the memory lasts.
5. The older open items below still stand.

## What changed on 2 and 3 October

| Version | What it added | Commit |
|---|---|---|
| v06.7 | Loop record (`loop_log`), forward model, loop probe tool. Passive. | `3ed616f` |
| v06.8 | Events from surprise, not raw pressure. Firmware hears its own tone. | `352cc0b` |
| | Collector reconnects after 8 s of silence from the body. | `21518b2` |
| v06.9 | The loop is felt by the two loop cells. Curiosity probes. Voice rule. | `9d0da9a` |

After v06.9, on 2 and 3 October, the dashboard was reworked. None of it touches
the Creature's behaviour.

| What | Commit |
|---|---|
| The reservoir drawn from its real wiring; click a cell to see its connections | `12b24de` |
| Fixed panel sizes, compact inspector | `a376349` |
| Learning panel: own light, own voice, surprise, ring links over time | `fd8770b` |
| Static export refreshes `learning.json` every five minutes | `fe1739c` |
| Left menu, field always visible, one section beside it | `cc68ec8` |
| Public mirror goes stale after 20 s, not 8 | `eeeee5e` |
| Day mode, with a day / night / auto switch | `1b6c2fd` |
| Legend rewritten to cover every mark the field draws | `e300d14` |

The legend had said the loop "isn't physically closed yet". It now says the sound
loop is closed and the light loop is not settled. When open item 1 settles the
light loop, change that sentence in `setV06Legend` in `dashboard/index.html`.

The reason for the v06.7 to v06.9 work: the Creature was going in circles. Its inputs were near
constant, its notion of an event was its own constant, and nothing about its
acting came back to it.

## What the real Creature showed

Events. Before v06.8 every tick was a "significant event", because the weather
anchor's steady pressure crossed a fixed threshold. Sleep was replaying the quiet
run-up to itself. Now 8 to 13% of ticks are events. In the afternoon the sound
anchor topped nearly all of them; by evening, with the lux reading swinging, the
light anchor topped most. A replay of 260,000 recorded ticks agrees on the rate:
100% down to 12%.

Voice. Before v06.9 the unmuted Creature sent a tone at its 20-second minimum
spacing almost continuously: 242 tones in 1.8 hours, 192 of the 241 gaps at the
minimum. In the first 15 minutes on v06.9 it sent 2. The recorded-data replay
gives about 20 an hour against 109.

Sound loop. It is physically closed. With the new firmware, tones near 400 Hz
come back at 11,500 to 16,500 at their own pitch, against 200 to 2,000 for the room
at that pitch. The speaker is uneven: peaks near 330 and 400 Hz, a dip near 370,
weak below 300. The voice model now keeps one gain per band of pitch for that
reason. It started fresh at the v06.9 restart.

Light loop. This one changed during the day and is not settled.

- At 16:45 the loop probe found nothing: every strip frame, up to all four
  channels at the cap, added under 0.5 lux in a 768 lux room.
- From about 18:00 the forward model's predictions correlate about 0.6 with the
  real change in lux, where before they did not correlate at all. The reading
  swings about 20 lux from tick to tick, and the level at the sensor fell from
  about 770 lux to between 10 and 90.
- So the sensor appears to see the strip now. Why is not known. Something may
  have moved when the USB cable was plugged in around 17:40, or it was moved on
  purpose. Part of the drop in level could simply be evening.
- The light model is too crude for a sensor that sits near part of the strip. It
  knows only the average of each colour channel across all sixteen pixels, not
  which pixels are close. It explains about 20% of the change. Its four weights
  are large with mixed signs, which is what a poorly conditioned fit looks like.
- Right after the v06.9 restart its skill fell to about 5%, most likely because
  the curiosity probe's white lifts are something it had not seen in isolation.
  Whether it recovers has not been checked.
- Felt light was small and intermittent: about 0.08 on half the ticks, up to
  0.33, switching on and off as the model's skill hovers around its threshold.

Nothing was running away at the last look. Arousal was between 0.5 and 0.75.

## Older open items, in the order I would take them

1. Find out what changed on the body, then rerun the loop probe to measure the
   light coupling as it is now. It takes the Creature offline for about two and a
   half minutes.
2. Give the light model one weight per pixel, so it can learn which part of the
   strip the sensor sees. This is the main thing standing between the closed
   light loop and a model that can use it.
3. Look at a full night on v06.9. Three things to check: the probe tones (about
   six an hour when nothing else happens, including at night), what sleep now
   replays, and how much structure thins overnight now that sleep no longer adds
   weight by replaying its own background.
4. If felt light keeps flickering on and off, give its gate a dead zone. Today it
   scales with the model's explained fraction from zero, and the room-only light
   sense switches at 0.1. Both are low bars for a noisy model.
5. Three older gates fail under today's defaults and have for a while: the ring
   gate with the predictive cell (4/7), reservoir (3/4), readout (1/2). The design
   doc notes it. Nobody has looked at why.
6. The reservoir readout learns but drives nothing. The emitters are driven by
   ring cells 0 and 6. The design doc's readout section describes it as working.
7. Once the probe is rerun, the design doc's Known limitations need updating. It
   still says the light loop is physically open. The dashboard legend's loop
   sentence needs the same update.
8. A normalizer quirk, seen only in simulation so far: when a loud spike leaves
   the sound normalizer's 20 second window, a room whose noise spread is just
   above the minimum range reads as moderately loud for a moment. Real data showed
   no sign of it, but it is worth knowing when a test room misbehaves.
9. The public dashboard mirror's `state.json` carries the raw sensor readings,
   although the Sensors panel is hidden there. Since v07.0 that includes the air
   readings and the gas index. Decide whether that is wanted.

After those, the direction agreed at the start of the session:

- Memory of consequences. Episodes built from `loop_log`: what the senses were,
  what it emitted, what came back, how much of that it caused. Similar episodes
  found by plain numeric vectors, linked in a graph. No embedding model needed.
- A language model as the dream state. Once a night it sees a small export and
  proposes edits from a fixed set (replay, strengthen, weaken, merge, associate,
  forget, label). It never sets weights and never drives the body. Each proposal
  is kept only if it predicts held-out history better.
- Where the dreamer runs was priced on 28 September. Cheapest is an API call from
  the Pi: GPT-6 Luna at well under a dollar a month, Claude Haiku 4.5 at about a
  dollar. A Jetson Orin Nano Super (now $399) can run models up to about 8B
  parameters locally, with far weaker judgment. The MacBook has 16 GB and can run
  the same local models for a trial.

## How to work on it

Run everything from `Code/Python`.

Gates. One per build step, fixed seed, control against variant. The ones added
this session pass on seeds 1, 2, 3 and 7.

| Gate | Command | Result |
|---|---|---|
| forward model | `python tools/field_lab_v06.py --forward` | 7/7 |
| events | `python tools/field_lab_v06.py --events` | 6/6 |
| the loop is felt | `python tools/field_lab_v06.py --feel` | 7/7 |
| curiosity | `python tools/field_lab_v06.py --curious` | 9/9 |
| voice | `python tools/field_lab_v06.py --voice` | 6/6 |
| history | `python tools/field_lab_v06.py --history` | 4/4 |
| twin | `python tools/field_lab_v06.py --twin` | 6/6 |
| gas index port | `python tools/gas_index_check.py` | PASS |

The history gate judges a variant against a saved control. On recorded senses,
with the setting that is live now:

    python tools/field_lab_v06.py --history --seed 1 --history-hours 72 \
        --replay data/replay/senses_2026-09-24_to_2026-10-02.csv \
        --state data/replay/field_state_2026-10-02.json --json control.json
    python tools/field_lab_v06.py --history --seed 1 --history-hours 72 \
        --replay data/replay/senses_2026-09-24_to_2026-10-02.csv \
        --state data/replay/field_state_2026-10-02.json \
        --set SLOW_MIX=0.25 --set SOFT_CEILING=True --set CEILING_KNEE=1.0 \
        --set SLOW_LEAK=4.13e-7 --compare control.json

Each takes several minutes. `--express` reads 8/9 at defaults and did before
this work.

Replay on recorded senses. `--events` and `--voice` take `--replay` and `--state`.
A copy of 260,000 real ticks and the field state they start from is in
`data/replay/` (not in git):

    python tools/field_lab_v06.py --voice \
        --replay data/replay/senses_2026-09-24_to_2026-10-02.csv \
        --state data/replay/field_state_2026-10-02.json

That export came from the event log, which held every tick's senses only because
every tick was an event. From v06.8 the tick log stores all four senses instead,
and the query for a fresh export is in the docstring of `_read_replay`.

End to end without hardware. `tools/fake_body.py` stands in for the ESP over TCP,
with a strip the sensor can or cannot see and a speaker shaped like the real one.
Its docstring has the commands and two traps to avoid.
`tools/scripted_body.py` runs the real collector loop on a scripted body and a
pretend clock, so a run comes out the same every time and two runs can be
compared line for line. `--twin-check` uses that to show the twin changes nothing.

On the real body. `tools/loop_probe.py` measures both loops with known outputs.
Stop the collector first: the body accepts one connection.

Switches, all environment variables on the collector:

| Variable | Default | What it does |
|---|---|---|
| `CREATURE_LOOP` | 1 | loop record and forward model |
| `CREATURE_LOOP_FEEL` | 1 | the loop cells feel the forward model's result |
| `CREATURE_PROBE` | 1 | curiosity probes |
| `CREATURE_PROBE_VOICE` | 1 | the probe tone (0 keeps the light probe only) |
| `CREATURE_VOICE_MODEL` | relative | `fixed` brings back the old 0.45 threshold |
| `CREATURE_VOICE_MARGIN` | 0.20 | how far above usual arousal must be to speak |
| `CREATURE_ESP_SILENCE_SECONDS` | 8 | silence before the collector reconnects |
| `CREATURE_EXPRESSION_MODEL` | fixed | `relative` scales the strip and tone against the field's own usual; on at the Pi |
| `CREATURE_TWIN` | 1 | the newborn twin |
| `CREATURE_SLOW_MIX` | 0.0 | two-speed links: share of the drive taken from the slow weight; 0.25 at the Pi |
| `CREATURE_SOFT_CEILING` | 0 | 1 scales growth by the room left under the ceiling; 1 at the Pi |
| `CREATURE_CEILING_KNEE` | 0.0 | weight up to which growth is not braked; 1.0 at the Pi |
| `CREATURE_SLOW_LEAK` | 0.0 | the slow weight's drift toward the floor, per tick; 4.13e-7 at the Pi |
| `CREATURE_PAPER` | 1 | the `EPD:` text for the body's e-paper |

In the field, `EVENT_MODEL = "pressure"` and `LOOP_FEEL_GAIN = 0` are the controls
for the event rule and the felt loop.

Deploying to the Pi. Push `main`, then on the Pi fast-forward its `v06` branch to
`origin/main` (a plain pull says it is up to date), stop the collector in its tmux
session, start it again. Before each restart the saved state was copied next to
the database with a name such as `.pre-twospeed.json` on the end.

The start command in force since 9 October (20:07), typed in the tmux pane (in
`~/Creature/Code/Python`, venv active). Leave any part out and that part is off:

    CREATURE_EXPRESSION_MODEL=relative CREATURE_SLOW_MIX=0.25 \
    CREATURE_SOFT_CEILING=1 CREATURE_CEILING_KNEE=1.0 CREATURE_SLOW_LEAK=4.13e-7 \
    CREATURE_BATTERY_CEILING=1 CREATURE_COLOUR_MODEL=inner \
    CREATURE_VOICE_PALETTE=open CREATURE_DARK_CALM=1 \
    python collector/collector.py tcp://creature-esp.local:7777

To start a fresh twin, stop the collector first, then move
`creature_field_state_twin_v06.json` aside, then start. The collector saves the
twin again as it exits, so moving the file while it runs does nothing. Wait ten
minutes after a restart before judging it by events or tones.

Looking at a dashboard change. Start the `creature-dashboard-test` entry in
`.claude/launch.json` and open http://localhost:8791. It reads a snapshot from a
scratch folder; if the field is empty, copy `dashboard/public/state.json` there.
The page says "stale" because the snapshot is old. On the Pi the dashboard serves
`index.html` from disk, so a fast-forward is the whole deploy, and the sync loop
carries the page to the public mirror within a minute. A change to `server.py`
needs the dashboard service restarted as well; see the v07.0 section for how.

Flashing the body. Plug the ESP's UART socket into the Pi. It shows up as
`/dev/ttyACM0`, not `ttyUSB0`. Build and upload with the PlatformIO in the Pi's
firmware folder. Opening that serial port resets the ESP. After a flash, watch
the serial output for `wifi_ready` before starting the collector; if it only
prints `wifi_reconnecting`, reset the body. A bench sketch can be built from a
scratch folder on the Pi outside the checkout, with the same PlatformIO, so the
checkout stays clean. Flashing a bench sketch takes the Creature offline until
the main firmware is flashed back.

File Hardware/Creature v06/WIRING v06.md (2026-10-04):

# Creature Hardware Wiring

Version: v06 — June 19 2026. Updated 4 October 2026 for build v07.0, which added
the air sensors and the e-paper to the same body.

Body node wiring for v06. The devices below match the live firmware in
`Code/Firmware/esp-creature-core/src/main.cpp`. The ESP reads the four senses and
the two air sensors, accepts legacy `LED:<brightness>` status commands, and
accepts v06 `PIX:` strip frames, optional `VOX:` speaker commands and `EPD:` text
for the e-paper.

## Board

ESP32-S3-DevKitC-1 style board (the module is marked N16R8). Seated on the breadboard across the center channel.
Connects to the Raspberry Pi 3 by USB serial at 115200 baud. The Pi runs the
collector and sends `LED:<brightness>` back over the same connection.

## Devices

- INMP441: I2S MEMS microphone, sound. (coded + enabled)
- BH1750: I2C ambient light, lux. (coded + enabled)
- BME280: I2C temperature / humidity / pressure. (coded + enabled)
- MPU-6050 / ICM-20689: I2C IMU, motion + orientation. (coded + enabled)
- MAX98357A + 4Ω 3W speaker: I2S audio output. (coded + enabled; `VOX:` optional)
- SK6812 RGBW strip: addressable emitter, ~16 px. (coded + enabled; `PIX:`)
- Onboard NeoPixel (RGB@IO38): status pixel. No external wiring.
- SCD41: I2C CO2, temperature, humidity. (coded + enabled; dashboard only)
- SGP41: I2C VOC and NOx. (coded + enabled; dashboard only)
- Waveshare 2.13inch e-Paper HAT V4: SPI readout, 250 x 122. (coded + enabled; `EPD:`)

## Pin assignments

| Function | ESP32-S3 pin | Device pin | Notes |
|---|---|---|---|
| I2S0 bit clock | GPIO 5 | SCK | INMP441 (coded) |
| I2S0 word select | GPIO 6 | WS | INMP441 (coded) |
| I2S0 data in | GPIO 7 | SD | INMP441 data out (coded) |
| INMP441 channel sel | GND | L/R | L/R to GND = left channel. Do not float |
| I2C data | GPIO 8 | SDA | BH1750 + BME280 + IMU, shared |
| I2C clock | GPIO 9 | SCL | BH1750 + BME280 + IMU, shared |
| BH1750 address | GND | ADDR | ADDR to GND = 0x23 |
| BME280 address | GND | SDO | SDO to GND = 0x76 |
| IMU address | GND | AD0 | AD0 to GND = 0x68 |
| I2S1 bit clock | GPIO 15 | BCLK | MAX98357A |
| I2S1 word select | GPIO 16 | LRC | MAX98357A |
| I2S1 data out | GPIO 17 | DIN | MAX98357A |
| SK6812 data | GPIO 4 | DIN | via 470Ω on perfboard |
| Onboard RGB LED | GPIO 38 | - | NeoPixel status pixel, no ext wiring |
| Air senses | GPIO 8 / 9 | SDA / SCL  | SCD4x (0x62) and SGP41 (0x59), on the shared I2C bus. Leave the SGP41's `3.3V` pin open |
| e-paper data | GPIO 1 | DIN | Waveshare 2.13inch e-Paper HAT V4, blue |
| e-paper clock | GPIO 2 | CLK | yellow |
| e-paper chip select | GPIO 42 | CS | orange |
| e-paper data/command | GPIO 41 | DC | green |
| e-paper reset | GPIO 40 | RST | white |
| e-paper busy | GPIO 39 | BUSY | purple. HAT's BS switch at 0 (4-line SPI); VCC grey to 3V3, GND brown |
| 3V3 | 3V3 rail | VDD / VIN  | All sensors and mic |
| 5V | 5V pin | +5V | SK6812 strip and MAX98357A amp VIN |
| Ground | GND rail | GND | Single common ground for everything |

Pins avoided on the N8R8: 0/3/45/46 (strapping), 19/20 (USB), 43/44
(USB-serial), 26-37 (flash and octal PSRAM), 38 (onboard pixel).

## I2C bus

These devices share GPIO 8/9. No address clash:

- BH1750 = 0x23
- BME280 = 0x76
- MPU-6050 / ICM-20689 = 0x68
- SGP41 = 0x59
- SCD41 = 0x62
- MAX17048 fuel gauge = 0x36 (untethered power add-on, see below)

The GY-302 (BH1750) and GY-521 (IMU) breakouts carry onboard pull-ups, so no
external I2C resistors are needed. The two air sensor boards carry their own as
well; with all of them in parallel the bus still scans cleanly.

The e-paper's six signal pins were chosen as the only run of six free, safe pins
on the ESP's empty edge. On that edge 35, 36 and 37 belong to the module's
memory, 38 is the onboard LED, 45 and 0 are boot-mode pins, 19 and 20 are the
second USB port, and RX and TX are the serial link used for flashing. The edge
has no 3V3 pin, so the panel's VCC comes from the 3V3 rail.

## Unused pins — leave open (n/c)

These are intentionally not wired. Not omissions.

- IMU **INT** — motion interrupt. Firmware polls, so unused.
- IMU **XCL** and **XDA** — auxiliary I2C master bus for chaining a sensor onto
  the IMU. Not used here.
- MAX98357A **GAIN** and **SD** — left floating for default gain and enable.

Required power pins that are easy to miss next to the open ones: BH1750 **VCC**
and IMU **VCC** to 3V3, and IMU **AD0** to GND (sets 0x68).

## Audio

Two separate I2S peripherals so the mic and amp never share pins:

- I2S0 (RX) = INMP441 mic, on GPIO 5/6/7. Already in firmware.
- I2S1 (TX) = MAX98357A amp, on GPIO 15/16/17. Needs firmware.

MAX98357A: VIN to the +5V rail, not 3V3. **Confirmed 22 Jun 2026: VIN on 3V3 was
the actual cause of the persistent distortion** — not enough headroom, so it
clipped at real signal levels. Moving VIN to 5V fixed it completely. Leave SD and
GAIN floating for default enable and gain. Speaker + and - to the screw terminal.

## SK6812 strip

- DIN to GPIO 4 through the 470Ω series resistor on the perfboard.
- +5V from the +5V rail (PowerBoost output), GND to the common rail.
- 1000µF cap across 5V/GND at the strip input (on the perfboard).
- ~16 px cut. Cap global brightness (~40% or less) and avoid all-channels-white.
  On the PowerBoost (~1A budget) that keeps the whole node in range. If you ever
  bench-power the strip from the 3V3 pin instead, keep brightness very low to
  protect the onboard regulator.
- Library: Adafruit NeoPixel, `NEO_GRBW + NEO_KHZ800`, colour order GRBW. This is
  a second NeoPixel object, separate from the onboard `NEO_GRB` status pixel.

## Power

Power comes from the PowerBoost 1000C 5V output. Right now it is fed by the
PowerBoost microUSB; the LiPo takes over later (see the PowerBoost add-on below).
That 5V is the system +5V rail. The ESP USB-C is only for programming.

- PowerBoost 5V to the +5V rail. PowerBoost GND to the common ground rail.
- ESP 5V IN pin from the +5V rail. The onboard regulator makes 3.3V from it.
- SK6812 +5V and MAX98357A VIN both run from the +5V rail directly.
- Sensors and mic take 3V3 from the ESP 3V3 pin, GND from the common rail. That
  3V3 is the regulator output, so the same source powers it.
- One common ground for everything.

Notes:

- The breadboard's power rails are not continuous end to end — they're split into
  segments, not one long rail. Bridge each split with a short jumper where needed
  rather than running a second dedicated supply wire back to the source. Current
  bridges: 3V3 and GND are jumpered together on one end (ESP side), 5V is jumpered
  separately on the other end (toward the amp/strip cluster). Check rail continuity
  with a meter or by eye before assuming a rail tap reaches a newly-added device —
  this is what bit the amp/strip relocation to the bottom-right.
- The board's bottom-corner pin labelled 5V is an INPUT (5V IN). It does not output
  5V, so the strip is fed from the PowerBoost rail, not from the ESP.
- ESP32-S3 GPIO is 3.3V. Never feed 5V into a GPIO. The INMP441 is a 1.8 to 3.3V
  part, 3.3V only.
- The 5V IN pin is diode-protected, so the USB-C and the PowerBoost can be plugged
  in at the same time without back-feeding.

Bench state, 20 Sep 2026: the PowerBoost is not wired in yet. The +5V rail is fed
by a second ESP board on a wall USB adapter, and the main ESP USB-C is plugged in
for data. That second ESP is not diode-protected against back-feed.

Cutover to the PowerBoost (see the add-on below for the full path):

1. Unplug all power, including the second ESP and the wall adapter.
2. Remove the second ESP's 5V wire from the +5V rail. Never leave two 5V sources
   tied to the rail.
3. PowerBoost GND pad to the common ground rail first, then PowerBoost 5V pad to
   the +5V rail.
4. Plug the LiPo into the PowerBoost JST last.
5. The ESP USB-C can stay plugged into the Pi for serial data. The collector needs
   that link. If it is unplugged, no readings reach the dashboard.

## PowerBoost 1000C, untethered power (add-on)

For the untethered build, a LiPo feeds the Adafruit PowerBoost 1000C. Its 5V boost
output becomes the system 5V rail. The strip and the ESP both run from it, and the
MAX17048 fuel gauge watches the battery.

Power path:

- LiPo (3.7V 2500mAh) into the PowerBoost JST. Check polarity before plugging in. A
  reversed cell damages the board. Keep this lead short.
- PowerBoost 5V pad to the +5V rail. PowerBoost GND pad to the common ground rail.
- SK6812 +5V to the +5V rail. The strip now gets true 5V, so full brightness and
  working whites.
- ESP 5V IN pin to the +5V rail. The board powers through its own input diode.
- One common ground for PowerBoost, ESP, strip, and sensors.
- Charge by plugging a microUSB into the PowerBoost's own port. It load-shares, so
  the node keeps running while charging.

3V3 from the LiPo (nothing extra to wire):

The sensors stay on the ESP 3V3 pin, which is the onboard regulator output. Feeding
PowerBoost 5V into 5V IN runs that regulator, so the 3V3 rail and every sensor on it
is powered from the battery automatically. Never put 5V on the 3V3 pin.

MAX17048 fuel gauge (I2C, address 0x36):

- Board is the Adafruit MAX17048 breakout (two JST-PH ports, passed straight through).
  Battery path: LiPo into one JST, short JST-PH to JST-PH cable from the other JST to
  the PowerBoost JST. The chip is powered by and measures the cell through that path.
  Either port works for either side: the two JSTs are wired in parallel.
- VIN to the 3V3 rail. VIN only powers the I2C pull-ups, so it must match ESP logic.
  Never put VIN on the battery: it would pull SDA/SCL to ~4.2V, over the 3.3V GPIO limit.
- GND to common ground.
- SDA to GPIO 8, SCL to GPIO 9. Shares the I2C bus, no address clash.
- Library when coding: Adafruit MAX1704X. Reports cell voltage and state of charge.

On/off and cautions:

- Optional power switch: any small switch between EN and GND. Open is on, shorted to
  GND is off. EN is a signal pin, so the switch carries no load current.
- Do not wire LBO to a GPIO. It is pulled to battery voltage (about 4.2V), above the
  3.3V limit. Use the MAX17048 for low-battery sensing instead.
- The PowerBoost 1000C gives about 1A continuous and sags past ~500mA. ESP plus WiFi
  plus 16 px at moderate brightness stays under that. Full-white on all pixels can
  exceed 1A and cause sag or cutout, so keep strip brightness capped.
- Program over the ESP USB-C. Run untethered on the PowerBoost. The board's input
  diodes let both be connected at once.

## Notes and gotchas

- INMP441 L/R must be tied (GND for left). Floating L/R gives unstable data;
  tied to VDD gives near-zero on the left slot the firmware reads.
- If `sound_rms` sits near zero: check SD on GPIO 7, that SCK/WS (5/6) are not
  swapped, and that L/R is grounded. Loose breadboard contact on the I2S clock
  lines also causes intermittent reads — solder the headers.
- If `light_lux` reads -1: check SDA/SCL (8/9) and 3V3/GND to the BH1750.
- The IMU reports `WHO_AM_I = 0x98`, so it behaves as an ICM-20689, not a strict
  MPU-6050. Use the `finani/ICM20689` library when adding it to firmware.
- Only one program can hold the ESP serial port. Do not run the PlatformIO
  Serial Monitor and the Pi collector at once.
- The small green board LED that blinks during runtime is the board's USB-serial
  activity indicator on many ESP32-S3 dev boards, not the controllable RGB LED.
  Current firmware keeps USB Serial chatty for boot/debug, then quiets it while a
  WiFi collector client is connected so normal TCP runs do not blink constantly.

## Firmware status

The firmware streams one JSON line per sample at ~10 Hz over USB serial and WiFi
TCP when configured. Raw values are normalized 0-1 by the Pi collector.

On boot, current firmware runs a strip proof on GPIO 4: red, green, blue, white,
then a dim blue idle fill. If the onboard ESP LEDs are alive but the strip stays
dark during that proof, check strip 5V, common ground, the 470 ohm data resistor,
DIN direction, and whether the ESP has actually been flashed with the current
firmware.

Runtime output protocol:

- `LED:<0-255>`: legacy status command. Drives the onboard RGB pixel and mirrors
  a capped blue fill to the SK6812 strip. The live collector does not send this
  by default while `PIX:` expression is active, to avoid tick flicker.
- `PIX:r,g,b,w,...`: full v06 RGBW strip frame, up to 16 pixels. The live decoder
  keeps the white channel capped, but otherwise leaves the field's pulse and
  shimmer visible.
- `EPD:l1;l2;l3;l4;l5|r1;r2;r3;r4;r5`: text for the e-paper, two columns of five
  short lines. The body redraws only when the text changes, at most once a
  minute, with a full refresh every tenth redraw, and answers with a `paper`
  line giving the refresh time. The collector sends it every 180 ticks. Set
  `CREATURE_PAPER=0` to stop.
- `VOX:freq,ms[,vol]`: optional speaker tone. The live collector sends quiet,
  low, slow tones by default. Set `CREATURE_ENABLE_VOICE=0` to silence it.

Audio note: distortion was traced to amp VIN sitting on the 3V3 rail — not enough
headroom, so it clipped (fixed 22 Jun 2026 by wiring VIN to 5V instead; see
"Audio" above). The click-free playback recipe is a separate concern, still
worth keeping: real signal level, about 10 ms fades, 40 ms warm-up before the
tone, and a 150 ms tail drain. The mic stays live during playback now (mic on I2S0 and amp on I2S1 are separate peripherals, no need to uninstall); see
`Code/Firmware/bench/src/smoke_test.cpp`. If 5V VIN is too loud, prefer hardware
gain (GAIN to VIN) over shrinking the digital amplitude.

## History

- v06: Added BME280, IMU, MAX98357A amp + speaker, and the SK6812 RGBW strip to
  the v05 base. Mic moved to its own I2S peripheral (I2S0); amp on I2S1.
- v05: ESP on breadboard. INMP441 (I2S) and BH1750 (I2C). Photoresistor retired.
- Earlier: ESP beside the breadboard, photoresistor divider on GPIO 4. Archived.

## Wire colours

Six colours, six net groups, one to one. White is reassigned from the old
"optional/expansion" use to 3V3, so 3V3 and 5V are never confused.

| Colour | Use | Wires |
|---|-----|---|
| Black  | GND | every ground (one common net) |
| Red | 5V  | SK6812 +5V, MAX98357A VIN |
| White  | 3V3 | power to BH1750, BME280, IMU, INMP441 |
| Yellow | I2C SDA | GPIO 8 → all three I2C sensors |
| Blue | I2C SCL | GPIO 9 → all three I2C sensors |
| Green  | digital signal | I2S (mic 5/6/7, amp 15/16/17) + LED data (GPIO 4) |

Green carries seven signal lines, so green alone does not identify a net — keep
those runs short and read the schematic. The speaker is not in this scheme: its
two leads go from the MAX98357A screw terminal to the speaker, not to the ESP.

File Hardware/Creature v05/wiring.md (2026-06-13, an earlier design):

# Creature Hardware Wiring

Version: June 6 2026

Current body node. Reflects the live firmware in
`Code/Firmware/esp-creature-core/src/main.cpp` (v.05).

## Board

ESP32-S3-DevKitC-1 (N8R8). Seated directly on the breadboard, straddling the
center channel. Connects to the Raspberry Pi 3 by USB serial at 115200 baud. The
Pi runs the collector and sends `LED:<brightness>` commands back over the same
connection.

## Sensors

- INMP441: I2S MEMS microphone, sound. Cell 1 anchor.
- BH1750: I2C ambient light sensor, lux. Cell 4 anchor.
- Onboard NeoPixel (RGB@IO38): emitter. Cell 8. No external wiring.

The photoresistor divider is retired in v.05. Parts kept for later.

## Pin assignments

| Function | ESP32-S3 pin | Sensor pin | Notes |
|---|---|---|---|
| I2S bit clock | GPIO 5 | SCK | INMP441 |
| I2S word select | GPIO 6 | WS | INMP441 |
| I2S data in | GPIO 7 | SD | INMP441 data out |
| INMP441 channel sel  | GND | L/R | L/R to GND selects the left channel  |
| I2C data | GPIO 8 | SDA | BH1750 |
| I2C clock | GPIO 9 | SCL | BH1750 |
| BH1750 address | GND | ADDR | ADDR to GND gives address 0x23 |
| Onboard RGB LED | GPIO 38 | - | NeoPixel, no external wiring |
| 3V3 | 3V3 rail | VDD / VCC  | Both sensors power from the 3V3 rail |
| Ground | GND rail | GND | Shared ground on the GND rail |

Pins avoided on the N8R8: 0/3/45/46 (strapping), 19/20 (USB), 43/44
(USB-serial), 26-37 (flash and octal PSRAM).

## Physical build

The ESP32-S3 sits on the breadboard, straddling the center channel at one end,
USB facing off the end so the Pi cable does not lever the board. Both sensor
breakouts sit further along the same board, also across the center channel.

Power is shared through the side rails:

- ESP 3V3 to the red (+) rail, ESP GND to the blue (-) rail.
- Each sensor takes VDD/VCC from the red rail and GND from the blue rail.
- Signal pins run as short jumpers from the ESP GPIOs to each sensor.

The BH1750 (GY-302) has onboard I2C pull-ups, so no external resistors are
needed. If the DevKitC-1 leaves no free holes on the module side, join a second
breadboard along the long edge, remove the two facing power rails, and seat the
ESP so each pin row lands on its own board.

See `wiring-diagram.svg` for the visual version and `kicad/Creature.pdf` for the
formal schematic (source in `kicad/Creature.kicad_sch`). Both still show the old
photoresistor build and need updating to this pinout.

## Firmware output

One JSON line per sample at about 10 Hz over USB serial:

```text
{"time_ms":123456,"light_lux":214.2,"sound_rms":2371.0}
```

Values are raw. The Pi collector normalizes `light_lux` and `sound_rms` to 0-1.
`light_lux` is -1 if the BH1750 did not initialize. The startup line reports
`light_ready`.

## Parts list

- ESP32-S3-DevKitC-1 (N8R8) dev board
- INMP441 I2S microphone breakout
- BH1750 (GY-302) light sensor breakout
- Breadboard and jumper wires
- USB cable (ESP to Raspberry Pi 3)

No external LED or resistors needed. The onboard RGB LED is the only emitter.

## Behavior reference

- Soft blue blink on LED command.
- Brightness tracks output from the Pi. Pulse speed tracks pressure.

## Notes and gotchas

- ESP32-S3 GPIO is 3.3V. Do not feed 5V into any pin.
- Only one program can hold the ESP serial port at a time. Do not run the
  PlatformIO Serial Monitor and the collector at once.
- INMP441 L/R must be tied (GND for left). Floating L/R gives unstable data.
- If `sound_rms` sits near zero, check SD on GPIO 7 and that L/R is grounded.
- If `light_lux` reads -1, check SDA/SCL (8/9) and 3V3/GND to the BH1750.

## History

- v.05: ESP on breadboard. INMP441 (I2S) and BH1750 (I2C). Photoresistor retired.
- Earlier: ESP beside the breadboard, photoresistor divider on GPIO 4. Archived
  under `Archive/`.

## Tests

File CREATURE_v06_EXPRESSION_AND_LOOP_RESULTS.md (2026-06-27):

# Creature v06.5 expression-memory and loop results

Version: v06.5 sim phase, June 27 2026. Status: results log.

Records the build and test of the expression-memory layer (record, bias, novelty)
and the closed-loop dark-room probe, all in simulation in `field_lab_v06`. Pairs
with the design `Creature Expression as Memory.md` and the direction
`Creature Three Evolutions Out.md`. No hardware moved.

## The short version

Four offline probes were built and each passed its own gate, with a fixed seed so
the runs repeat.

1. The creature can keep an autobiography. Each tick its own expression (arousal,
   balance, tempo, whether it voices) becomes a point in a graph. Two creatures
   that lived different days end up with clearly different graphs, so the graph is
   a usable identity.
2. Letting the graph steer the next expression turns it into memory, but on its
   own memory has no safe middle. A little habit sharpens motifs; more habit
   collapses the creature into one groove.
3. A novelty drive fixes that, but only if it is adaptive, firing where the
   creature is worn in. Then a band opens at moderate habit where motifs survive
   without collapse. That band is temperament.
4. With the loop closed in sim and a curiosity drive, the creature stays active in
   a dark, silent room where the same creature without the loop goes flat. The
   activity is bounded, restless, and it learns its own echo.

Everything below runs from `Code/Python`. All probes use `--seed`.

## What changed in the code

One file: `Code/Python/tools/field_lab_v06.py`. Four probes and their helpers were
added. The brain (`mind/cell_field_v06.py`) and the decoder
(`mind/expression_v06.py`) were not touched; the probes read them. Plain Python,
no numpy, so the runs reproduce.

## Step 1: record (the autobiography)

    python3 tools/field_lab_v06.py --exprmem --seed 1

Result: 3 of 3 checks pass.

The expression vector is what the body emits, taken straight from the decoder:
arousal, balance, tempo, and whether it would send a voice tone. Each is
grid-quantized into a node, transitions between nodes are weighted, unused paths
decay. Identity is the total-variation distance between two graphs. A day life and
a bursts life sit 0.66 apart. Two day lives with different seeds sit 0.06 apart,
about an elevenfold gap. The graph encodes the life, not the noise.

## Step 2: bias (memory that steers)

    python3 tools/field_lab_v06.py --exprbias --seed 1

Result: 2 of 2 checks pass.

The graph predicts the usual next state, and that prediction is blended into the
expression by one mixing weight, field against habit. Sweeping the weight: nodes
fall from 49 to 4, dwell rises from 0.85 to 1.0, visit-entropy collapses from 0.73
to 0.001. There is no stable middle. Even mild bias trends toward the groove.
Memory on its own eats the creature, which is why novelty has to be a force, not a
readout.

## Step 3: novelty (the counter-force)

    python3 tools/field_lab_v06.py --exprnov --seed 1

Result: 2 of 2 checks pass.

Constant novelty was bistable, either too weak to leave the groove or strong enough
to raster the whole space into pure wandering. Adaptive novelty, gated by a dwell
counter so it fires only where the creature is worn in, opens a middle. Mapping
habit against novelty, a temperament band sits at moderate habit (around w 0.6, n
0.2 to 0.4): motifs about 1.7 times sharper than pure field while the spread stays
healthy. Nothing rescues extreme habit. Once fully in the groove, the dominant
habit recaptures every escape.

## The loop and the dark-room probe

    python3 tools/field_lab_v06.py --darkroom --seed 1

Result: 5 of 5 checks pass, stable across seeds 1, 2, 3, 7.

This probe feeds the body's output back into the field, which the memory steps
never did. The creature's own light and voice return as light and sound input. A
curiosity drive gates on current arousal, poking when the creature is flat and
easing off when it is active. With a loose loop gain that makes a relaxation
oscillator, bounded by construction yet never fully still. A small forward model
learns the loop gain.

In a dark, silent room the open-loop control goes flat (mean arousal 0.008). The
looped, curious creature stays alive (about 0.20), restless (tail std about 0.06),
bounded (steady-state max under 0.85), and its forward-model error falls to zero.
Nothing in the room caused any of it. The activity is self-generated and learned,
not random.

Two findings worth keeping. The loop runs away if coupled tightly, so keep it
loose, as the design said. And a steady self-loop is as predictable as a steady
room, so the predictive field habituates to it and goes quiet unless the probe
stays unpredictable. Random bursts keep surprise alive.

## Gate summary

| Probe | What it proves | Command | Result |
|---|---|---|---|
| record | an autobiography forms and tells two lives apart | `--exprmem` | 3/3 |
| bias | habit becomes memory, and over-bias collapses | `--exprbias` | 2/2 |
| novelty | adaptive novelty opens a temperament band | `--exprnov` | 2/2 |
| dark-room | self-generated, bounded, learned activity in an empty room | `--darkroom` | 5/5 |

## Into the runtime (v06.5 software)

The record layer is now in the live creature, not just the gates. The validated
logic moved into `Code/Python/mind/expression_memory_v06.py`, the single source of
truth; `field_lab_v06` imports its primitives (all four gates still pass) and the
collector imports the same module. Each tick the collector records what the body
expressed into a lasting autobiography, saved alongside the field slow-state and
reloaded on start, with a summary in the dashboard snapshot under
`expression_memory`. It is behind `CREATURE_EXPR_MEMORY` (default on) and is
passive: it changes nothing about what the body does.

Bias and novelty steering, and the loop, are deliberately not wired to the body
yet. Steering needs a decoder that renders from a steered signal, and the loop
needs the hardware sensors placed and stable power. Those are the next increments.

## Where this leaves the project

The whole sim arc stands. Record, bias, novelty, and the closed loop with its
dark-room proof all run in `field_lab` and gate green. This is the rehearsal.

The real build for Evolution 1 is to place the two loop sensors physically (a light
sensor that sees the strip, the mic positioned to hear the speaker), wire the
curiosity drive and forward model into the firmware and collector, and run the
dark-room test on the actual creature. That hardware run is the result the Risks
doc has been asking for. The one blocker is power: the loop work waits on the new
PowerBoost going in. Right now the 5V rail is fed from a second ESP.

Two threads stay in sim behind the hardware loop. Expression-memory step 4 (couple
the graph's prediction error back into the field) waits by design until the loop is
proven. And coupling the step-3 novelty force into the loop is what would turn the
dark-room hum into genuine restlessness.

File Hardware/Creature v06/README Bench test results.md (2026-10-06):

# Creature v06 bench bring-up

Phase 2 of the rollout: prove every part on the bench, one at a time, with the
smallest possible sketch, before the real firmware touches it. A part that fails
here fails in isolation, where it is obvious.

This is a separate PlatformIO project. It does not touch the main firmware in
`../esp-creature-core`. Each part is its own build environment.

## How to run one test

```
pio device list                      # find the port, set it in platformio.ini
pio run -e <env> -t upload           # build + flash
pio device monitor -b 115200         # read the result over serial
```

Only one program can hold the ESP serial port. Do not run the PlatformIO monitor
and the Pi collector at the same time.

## Order and pass criteria

Run in this order. Do not start the next part until the current one passes.

| Step | env | Part | Pass when |
|---|---|---|---|
| 1 | `i2c_scan` | I2C bus | 0x23, 0x68, 0x76 all show |
| 2 | `bme280` | BME280 weather | plausible temp + pressure, nonzero, stable |
| 3 | `imu` | ICM-20689 motion | WHO_AM_I = 0x98; motion scalar rises on tap, settles still |
| 4 | `sk6812` | SK6812 RGBW strip | every pixel shows R, G, B, W; no dead/wrong pixels |
| 5 | `speaker`  | MAX98357A + speaker | clean 440 Hz tone, volume steps up, silent at rest |
| 6 | `fuelgauge`| MAX17048 power level  | needs LiPo on its JST; cell 3.0-4.2V, percent 0-100, stable |

Step 6 is the untethered power sense and runs only after the battery is wired.
The MAX17048 is powered by the cell through its JST port, so with no LiPo plugged
in it will not appear on I2C at all. Its VIN pin goes to 3V3, never to the cell: on
the Adafruit breakout VIN only sets the I2C pull-up voltage. See the PowerBoost
add-on in WIRING v06 for the full battery wiring.

The mic (INMP441) and light sensor (BH1750) are already proven in the v05
firmware, so they are not repeated in the per-part list. If you want to re-check
them alone, the v05 firmware streams `sound_rms` and `light_lux` over serial.

## Combined smoke test

`env:smoke` brings up every part in one flash: it reads BH1750, BME280, and the
IMU over I2C, reads the mic (I2S0), animates the strip, blinks the onboard pixel,
and plays a quiet tone on the amp (I2S1) every five seconds. It prints one status
line per cycle with a PASS/-- per part.

```
pio run -e smoke -t upload && pio device monitor -b 115200
```

Use it for a fast "is the whole node alive" check. It does not replace the
per-part tests: when something looks wrong here, drop back to that part's own env
to isolate it. The mic and amp share this sketch but not pins (mic = I2S0,
amp = I2S1). On boot it runs an R/G/B/W strip proof and a short chirp, then the
status line starts. Tap the board, cover the light sensor, and make noise to see
the motion, light, and mic values move.

## Audio: playing clean tones (important)

**Root cause + fix (confirmed 22 Jun 2026):** the persistent distortion was not a
software/timing problem. Amp VIN was wired to 3V3, which is not enough headroom —
it clipped at real signal levels. Moving VIN to the +5V rail removed the
distortion completely. See `WIRING v06.md` → Audio for the pin change.

The recipe below is still worth keeping — it fixes click artifacts at start/stop,
a separate issue from clipping. This took a long debug to get right. The
reference is `playTone` + `ampSilence` in `src/smoke_test.cpp`. Reuse this recipe
in the real v06 firmware; do not rediscover it. Each rule earns its place:

- **Drive a real signal level** (amplitude ~0.25 of full scale, not tiny). The
  MAX98357A is class-D and sounds scratchy at very low digital levels. To make it
  quieter, turn down the hardware GAIN pin (GAIN to VIN), do not shrink the digital
  amplitude.
- **Fade in and out ~10 ms.** Abrupt edges cause hard clicks at start and finish.
- **Drain the tail, never chop it.** Do not call `i2s_zero_dma_buffer` right after a
  tone; it cuts the audio still in the DMA buffer (end click). Write ~150 ms of
  trailing silence so the faded tail plays out.
- **Warm the amp before the first tone** with ~40 ms of silence, or the first tone
  is distorted (cold start), especially after any I2S driver churn.
- **Mic and amp run concurrently; do not gate the mic (corrected 27 Jun 2026).** Mic
  (I2S0) and amp (I2S1) are separate peripherals on separate pins and run fine at the
  same time. The smoke test below still uninstalls the mic during its tone, harmless
  for a part-test, but the real firmware keeps the mic live. The distortion was amp
  VIN on 3V3 (power), not I2S contention, so the creature hears its own voice.
- **Config that works:** I2S1, BCLK=15/LRC=16/DIN=17, 16 kHz, 16-bit, ONLY_LEFT,
  STAND_I2S, `use_apll=false`, 8x256 DMA, continuous phase across tones. ONLY_LEFT is
  fine (the standalone speaker test proved it). APLL did not help.

VIN is now 5V (full 3W headroom). If that is too loud at default gain, turn it
down with hardware GAIN (GAIN to VIN) rather than shrinking the digital
amplitude. A decoupling cap on VIN (100µF + 0.1µF) is optional extra insurance,
not required for the fix.

## Notes carried from WIRING v06

- I2C is SDA=8, SCL=9. The GY-302 (BH1750) and GY-521 (IMU) carry their own
  pull-ups, so no external I2C resistors are needed.
- The IMU reports `WHO_AM_I = 0x98`. It is an ICM-20689, not a strict MPU-6050.
  This test reads raw registers so it does not depend on a driver library. When
  you add the IMU to the firmware, use the `finani/ICM20689` library.
- BME280 is at 0x76 (SDO to GND). If `begin()` fails, try 0x77.
- The SK6812 is the only 5V load. Keep brightness low off USB and avoid
  all-channels-white to prevent a brownout/reset. Confirm the 470 ohm data
  resistor and the 1000 uF cap are in place.
- Mic and amp use separate I2S peripherals (mic = I2S0 in the firmware, amp =
  I2S1 here), so they never share pins.

## Libraries

`pio run` pulls these automatically from `platformio.ini`:

- `bme280` env: `adafruit/Adafruit BME280 Library` (also pulls Adafruit Unified
  Sensor and BusIO).
- `sk6812` env: `adafruit/Adafruit NeoPixel`.
- `i2c_scan`, `imu`, `speaker`: no external library.

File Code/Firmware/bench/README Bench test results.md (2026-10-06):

# Creature v06 bench bring-up

Phase 2 of the rollout: prove every part on the bench, one at a time, with the
smallest possible sketch, before the real firmware touches it. A part that fails
here fails in isolation, where it is obvious.

This is a separate PlatformIO project. It does not touch the main firmware in
`../esp-creature-core`. Each part is its own build environment.

## How to run one test

```
pio device list                      # find the port, set it in platformio.ini
pio run -e <env> -t upload           # build + flash
pio device monitor -b 115200         # read the result over serial
```

Only one program can hold the ESP serial port. Do not run the PlatformIO monitor
and the Pi collector at the same time.

## Order and pass criteria

Run in this order. Do not start the next part until the current one passes.

| Step | env | Part | Pass when |
|---|---|---|---|
| 1 | `i2c_scan` | I2C bus | 0x23, 0x68, 0x76 all show |
| 2 | `bme280` | BME280 weather | plausible temp + pressure, nonzero, stable |
| 3 | `imu` | ICM-20689 motion | WHO_AM_I = 0x98; motion scalar rises on tap, settles still |
| 4 | `sk6812` | SK6812 RGBW strip | every pixel shows R, G, B, W; no dead/wrong pixels |
| 5 | `speaker`  | MAX98357A + speaker | clean 440 Hz tone, volume steps up, silent at rest |
| 6 | `fuelgauge`| MAX17048 power level  | needs LiPo on its JST; cell 3.0-4.2V, percent 0-100, stable |

Step 6 is the untethered power sense and runs only after the battery is wired.
The MAX17048 is powered by the cell through its JST port, so with no LiPo plugged
in it will not appear on I2C at all. Its VIN pin goes to 3V3, never to the cell: on
the Adafruit breakout VIN only sets the I2C pull-up voltage. See the PowerBoost
add-on in WIRING v06 for the full battery wiring.

The mic (INMP441) and light sensor (BH1750) are already proven in the v05
firmware, so they are not repeated in the per-part list. If you want to re-check
them alone, the v05 firmware streams `sound_rms` and `light_lux` over serial.

## Combined smoke test

`env:smoke` brings up every part in one flash: it reads BH1750, BME280, and the
IMU over I2C, reads the mic (I2S0), animates the strip, blinks the onboard pixel,
and plays a quiet tone on the amp (I2S1) every five seconds. It prints one status
line per cycle with a PASS/-- per part.

```
pio run -e smoke -t upload && pio device monitor -b 115200
```

Use it for a fast "is the whole node alive" check. It does not replace the
per-part tests: when something looks wrong here, drop back to that part's own env
to isolate it. The mic and amp share this sketch but not pins (mic = I2S0,
amp = I2S1). On boot it runs an R/G/B/W strip proof and a short chirp, then the
status line starts. Tap the board, cover the light sensor, and make noise to see
the motion, light, and mic values move.

## Air senses and e-paper (bare board)

`env:air` tests three new parts on a bare ESP32-S3 (N16R8) on a breadboard, away
from the v06 body: the SCD4x (CO2, temperature, humidity), the SGP41 (VOC and
NOx) and the Waveshare 2.13inch e-Paper HAT V4. Each part is reported on its own,
so one missing part does not stop the other two.

| Part | Part pin (wire)  | ESP32-S3 |
|---|---|---|
| SCD4x | VDD | 3V3 |
| SCD4x | GND | GND |
| SCD4x | SDA | GPIO 8 |
| SCD4x | SCL | GPIO 9 |
| SGP41 | VIN | 3V3 |
| SGP41 | GND | GND |
| SGP41 | SDA | GPIO 8 |
| SGP41 | SCL | GPIO 9 |
| e-paper | VCC (grey) | 3V3 |
| e-paper | GND (brown) | GND |
| e-paper | DIN (blue) | GPIO 1 |
| e-paper | CLK (yellow) | GPIO 2 |
| e-paper | CS (orange) | GPIO 42  |
| e-paper | DC (green) | GPIO 41  |
| e-paper | RST (white) | GPIO 40  |
| e-paper | BUSY (purple) | GPIO 39  |

Leave the SGP41 pin marked `3.3V` open; it is an output. The HAT's BS switch must
sit at 0 (4-line SPI). Both sensor boards carry their own I2C pull-ups. None of
these pins are used by the v06 body, and the addresses (0x62, 0x59) do not clash
with its I2C bus, so the wiring can carry over.

Pass when:

- SCD4x: first reading after about 5 s; CO2 400-2000 ppm indoors, and it climbs
  within a few readings when you breathe on it.
- SGP41: self-test ok; raw VOC in the tens of thousands, dropping when you
  breathe on it. The VOC index reads 0 for about 45 s, then settles near 100. The
  NOx index needs several minutes and settles near 1.
- e-paper: a full refresh takes roughly 1 to 5 s and the readings show. It
  redraws every 15 s with a fast partial refresh; every tenth redraw is a full
  one, which clears the ghosting that partial refreshes leave. A refresh that
  returns at once, or `Busy Timeout!` on serial, means wiring.

## Audio: playing clean tones (important)

**Root cause + fix (confirmed 22 Jun 2026):** the persistent distortion was not a
software/timing problem. Amp VIN was wired to 3V3, which is not enough headroom —
it clipped at real signal levels. Moving VIN to the +5V rail removed the
distortion completely. See `WIRING v06.md` → Audio for the pin change.

The recipe below is still worth keeping — it fixes click artifacts at start/stop,
a separate issue from clipping. This took a long debug to get right. The
reference is `playTone` + `ampSilence` in `src/smoke_test.cpp`. Reuse this recipe
in the real v06 firmware; do not rediscover it. Each rule earns its place:

- **Drive a real signal level** (amplitude ~0.25 of full scale, not tiny). The
  MAX98357A is class-D and sounds scratchy at very low digital levels. To make it
  quieter, turn down the hardware GAIN pin (GAIN to VIN), do not shrink the digital
  amplitude.
- **Fade in and out ~10 ms.** Abrupt edges cause hard clicks at start and finish.
- **Drain the tail, never chop it.** Do not call `i2s_zero_dma_buffer` right after a
  tone; it cuts the audio still in the DMA buffer (end click). Write ~150 ms of
  trailing silence so the faded tail plays out.
- **Warm the amp before the first tone** with ~40 ms of silence, or the first tone
  is distorted (cold start), especially after any I2S driver churn.
- **Mic and amp run concurrently; do not gate the mic (corrected 27 Jun 2026).** Mic
  (I2S0) and amp (I2S1) are separate peripherals on separate pins and run fine at the
  same time. The smoke test below still uninstalls the mic during its tone, harmless
  for a part-test, but the real firmware keeps the mic live. The distortion was amp
  VIN on 3V3 (power), not I2S contention, so the creature hears its own voice.
- **Config that works:** I2S1, BCLK=15/LRC=16/DIN=17, 16 kHz, 16-bit, ONLY_LEFT,
  STAND_I2S, `use_apll=false`, 8x256 DMA, continuous phase across tones. ONLY_LEFT is
  fine (the standalone speaker test proved it). APLL did not help.

VIN is now 5V (full 3W headroom). If that is too loud at default gain, turn it
down with hardware GAIN (GAIN to VIN) rather than shrinking the digital
amplitude. A decoupling cap on VIN (100µF + 0.1µF) is optional extra insurance,
not required for the fix.

## Notes carried from WIRING v06

- I2C is SDA=8, SCL=9. The GY-302 (BH1750) and GY-521 (IMU) carry their own
  pull-ups, so no external I2C resistors are needed.
- The IMU reports `WHO_AM_I = 0x98`. It is an ICM-20689, not a strict MPU-6050.
  This test reads raw registers so it does not depend on a driver library. When
  you add the IMU to the firmware, use the `finani/ICM20689` library.
- BME280 is at 0x76 (SDO to GND). If `begin()` fails, try 0x77.
- The SK6812 is the only 5V load. Keep brightness low off USB and avoid
  all-channels-white to prevent a brownout/reset. Confirm the 470 ohm data
  resistor and the 1000 uF cap are in place.
- Mic and amp use separate I2S peripherals (mic = I2S0 in the firmware, amp =
  I2S1 here), so they never share pins.

## Libraries

`pio run` pulls these automatically from `platformio.ini`:

- `bme280` env: `adafruit/Adafruit BME280 Library` (also pulls Adafruit Unified
  Sensor and BusIO).
- `sk6812` env: `adafruit/Adafruit NeoPixel`.
- `i2c_scan`, `imu`, `speaker`: no external library.
- `air` env: `zinggjm/GxEPD2` (also pulls Adafruit GFX and BusIO) and
  `sensirion/Sensirion Gas Index Algorithm`. The Sensirion sensors themselves are
  read with raw I2C.

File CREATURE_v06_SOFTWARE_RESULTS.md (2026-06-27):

# Creature v06 software phase results

Version: v06 software phase, June 17 2026. Status: results log.

Records the build and test of steps 1 to 4 (the field, in simulation). Pairs with
`Creature v06.md` (the design) and `CREATURE_v06_ROLLOUT.md` (the process). No
hardware moved during this work.

## The short version

The brain works in simulation. The four software steps are built and each one
passed its own test, with a fixed random seed so the runs repeat exactly.

In plain terms:

1. The body shrank from 111 cells to a ring of twelve. The ring shapes structure
   where the design says it should: the loop cells and the sound side build real
   connections, the weak gap stays weak, and the structure holds through a
   simulated night.
2. Six inner reservoir cells were added. They hold a fading echo of recent
   history. Two creatures that lived different lives end up in clearly different
   internal states, and the reservoir stays stable as long as its one tuning
   number stays below 1.0.
3. Each emitter learned to read the reservoir and track its partner sense. That
   read is far richer than wiring the emitter straight to a neighbour cell.
4. The cell was changed from a leaky integrator to a predictive cell. It now
   reports surprise instead of raw input. Under unchanging input the old field
   went flat and uniform. The new field stays differentiated.

One honest correction came out of the work. I expected the predictive cell to
rescue the weather and daylight side, which stayed weak in step 1. It does not,
and it should not. Slow steady signals are easy to predict, so a surprise cell
correctly goes quiet on them. Keeping that side alive at night is the closed
loop's job, which is step 7, not this step.

Everything below runs from `Code/Python`. All gates use `--seed 1`.

## What changed in the code

Two files, both new this phase. The v05.4 brain (`mind/cell_field.py`) was not
touched and still runs.

- `Code/Python/mind/cell_field_v06.py`: the ring field, the reservoir, the
  emitter readout, and the predictive cell. Current version string
  `v06.5-predictive`.
- `Code/Python/tools/field_lab_v06.py`: the offline test harness, one gate per
  step.

The matrix maths for the reservoir is plain Python, no numpy, so the numbers are
identical on any machine and the runs stay reproducible.

## Step 1: the twelve-cell ring

The ring keeps the v05.4 cell and its full machinery (energy, sleep, ripple,
Hebbian learning) but on the new anatomy: six sense and emitter anchors
alternating with six in-between cells, plus the four senses and two emitters.

Command:

    python3 tools/field_lab_v06.py --gate --seed 1

Result: 6 of 7 checks pass. Deterministic, and stable across seeds 1, 2 and 7.

What passed: the ring runs and differentiates; both loop cells (speaker by sound,
led by light) carry learned structure; the sound by motion cell carries the most;
the weak gap (weather by speaker) is the weakest, as designed; and the structure
survives a quiet night with about 99 percent of its differentiation held.

What failed: the light by weather cell sits at the floor. This is not a wiring
bug. Fed dynamic input that cell reaches 0.57, so the wiring is correct. The
cause is the leaky cell homogenising the slow, steady light and weather signals.
The design anticipates this; step 4 is the answer.

One fix was needed. The shared energy reserve had to be resized for a twelve-cell
body, where most cells stay active, unlike the mostly dormant 111-cell field. At
the old sizing the reserve deadlocked at zero and all learning starved. New
values: start 4.0, max 6.0, refill 0.6 per tick.

Note: this gate is written for the leaky cell. After step 4 the default cell is
predictive, so this same command now reports 4 of 7. That is the wrong gate for
the new cell, not a regression. Force the old cell with `--set CELL_MODEL=leaky`
to see the original 6 of 7.

## Step 2: the reservoir

Six inner cells, a fixed random recurrent network. The weights are set once and
never learned. The six in-between cells drive it. It holds a fading echo of
recent history. The readout to the emitters is the next step, so here the
reservoir only observes.

Command:

    python3 tools/field_lab_v06.py --reservoir --seed 1

Result: 4 of 4 checks pass.

Identical histories give an identical state, to the bit. Two different worlds
(a normal day versus a bursty room) drive the reservoir to clearly different
states, about half the state size apart. The echo state property is clean: below
spectral radius 1.0 the reservoir forgets its starting state and depends only on
the input. The sweep shows it healthy from 0.1 to 1.1 and broken at 1.5.

One finding from the sweep. The distinguishing power does not depend on the input
gain. Turning the gain up grows the state and the separation together, so the
ratio holds. The spectral radius is the lever that matters, not the input scale.

## Step 3: the emitter readout

Each emitter (speaker, led) reads a learned linear combination of the reservoir
state. The reservoir stays fixed; only the readout learns, by the delta rule,
to track its partner sense. The output does not feed back into the ring yet.

Command:

    python3 tools/field_lab_v06.py --readout --seed 1

Result: 2 of 2 emitters pass. Measured as variance explained (R squared) on a
held-out test split.

The reservoir read beats a direct connection to the emitter's ring neighbours.
For light it is 0.20 against -0.02. For the sound field state it is 0.14 against
0.03. The point underneath: a direct neighbour tap carries almost no information
about either sense, near zero. The reservoir gives the emitter a far richer
drive.

Two honest notes. First, the reservoir only ties the raw in-between cells on this
task; its memory adds little when the job is tracking a current level, and should
pay off later on memory tasks and once the loop closes. Second, I changed the
training target. Predicting the next raw sense failed, because sound is random
bursts and cannot be predicted. The readout instead tracks the current sense, the
state the emitter should express. When the loop closes in step 7, the same rule
becomes real prediction, because the sense it confirms will be the emitter's own
returning output.

## Step 4: the predictive cell

The cell changed from a leaky integrator to a predictive cell. Each cell holds a
running prediction of its own drive and reports the error, the surprise, instead
of the raw input. A cell that predicts well goes quiet. A surprised cell speaks.
The homeostatic gain was removed, since that was the part actively pulling every
cell to one shared level.

Command:

    python3 tools/field_lab_v06.py --predictive --seed 1

Result: 2 of 2 checks pass. Stable across seeds.

Under steady input the leaky field flattens. Every cell's average activity
collapses to the same value, spread near 0.0001, a uniform wash. The predictive
field holds 15 to 23 times that spread. On the realistic day run its overall
differentiation is 0.44 against the leaky 0.15.

The correction noted up front belongs here. The predictive cell does not rescue
the light by weather cell, and that is correct behaviour. Slow predictable
signals produce no surprise once learned, so the cell goes quiet on them. Weather
is meant to be a nonzero floor at night, not a structure builder. The loop is
what keeps that side alive, in step 7.

The mechanism gates still pass with the predictive cell as default: reservoir
4 of 4, readout 2 of 2. All runs deterministic.

## Gate summary

| Step | What it proves | Command | Result |
|---|---|---|---|
| 1 | ring shapes structure, survives a night | `--gate --set CELL_MODEL=leaky` | 6/7 |
| 2 | reservoir distinguishes histories, echo state holds | `--reservoir` | 4/4 |
| 3 | readout richer than a direct ring tap | `--readout` | 2/2 |
| 4 | no flattening under steady input | `--predictive` | 2/2 |

## Where this leaves the project

Phase 1 of the rollout is done. The field works in simulation, the entropy test
passed, and nothing physical moved. The next phase is hardware: bring the new
sensors up on the bench one at a time, then steps 5 to 8, streaming the senses
into the field, wiring the decoder behind `ENABLE_STRIP` and `ENABLE_VOICE`, and
closing the loop loose.

Suggested tags for the four gates that passed: `v06-1-ring` (with the leaky cell),
`v06-2-reservoir`, `v06-3-readout`, `v06-4-predictive`.

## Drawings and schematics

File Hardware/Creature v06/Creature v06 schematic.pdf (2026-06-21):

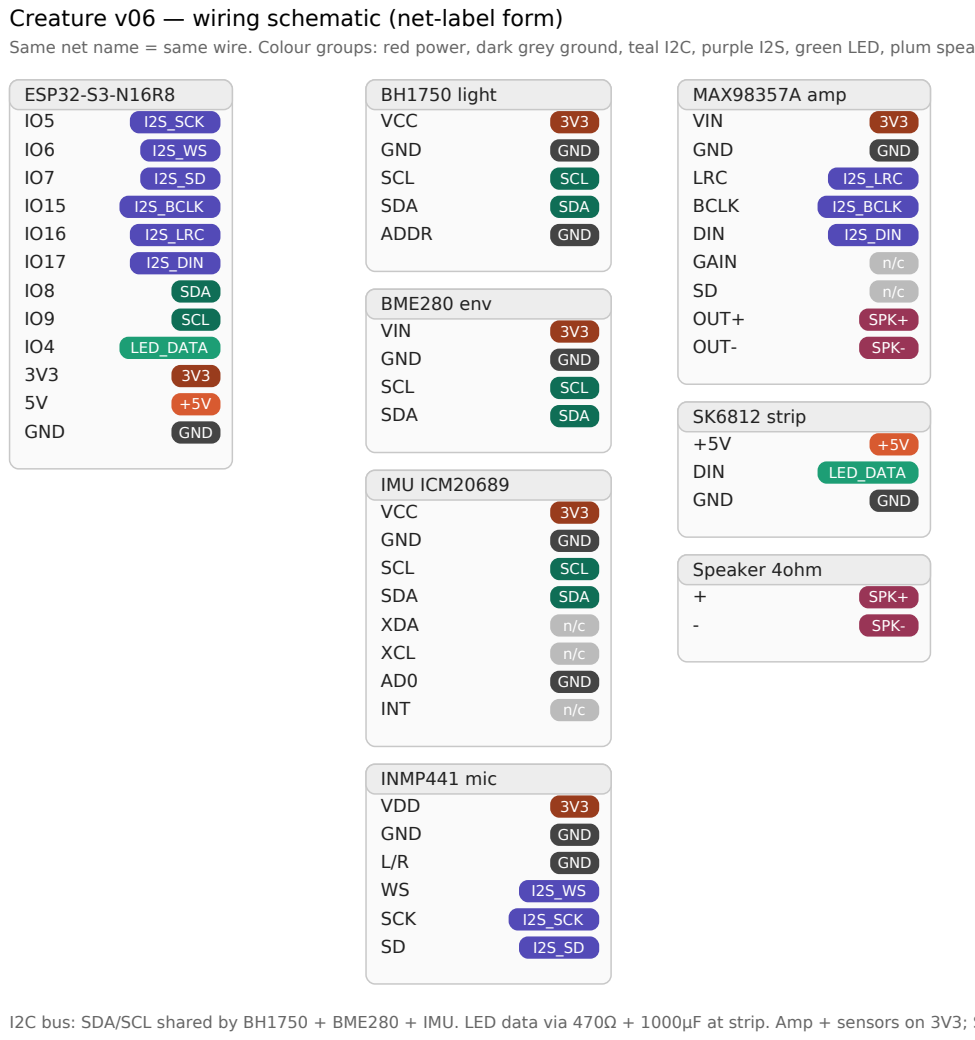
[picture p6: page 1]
ESP32-S3-N16R8; I2S_SCK; I2S_BCLK; I2S_LRC; I2S_DIN; SDA; SCL; LED_DATA; GND; BH1750 light; VCC; ADDR; BME280 env; VIN; IMU ICM20689; XDA; XCL; INT; INMP441 mic; VDD; SCK; MAX98357A amp; LRC; BCLK; DIN; GAIN; OUT+; SPK+; OUT-; SPK-; SK6812 strip; Speaker 4ohm; - SPK-

Creature v06 — wiring schematic (net-label form)
Same net name = same wire. Colour groups: red power, dark grey ground, teal I2C, purple I2S, green LED, plum spea

I2C bus: SDA/SCL shared by BH1750 + BME280 + IMU. LED data via 470Ω + 1000µF at strip. Amp + sensors on 3V3; S

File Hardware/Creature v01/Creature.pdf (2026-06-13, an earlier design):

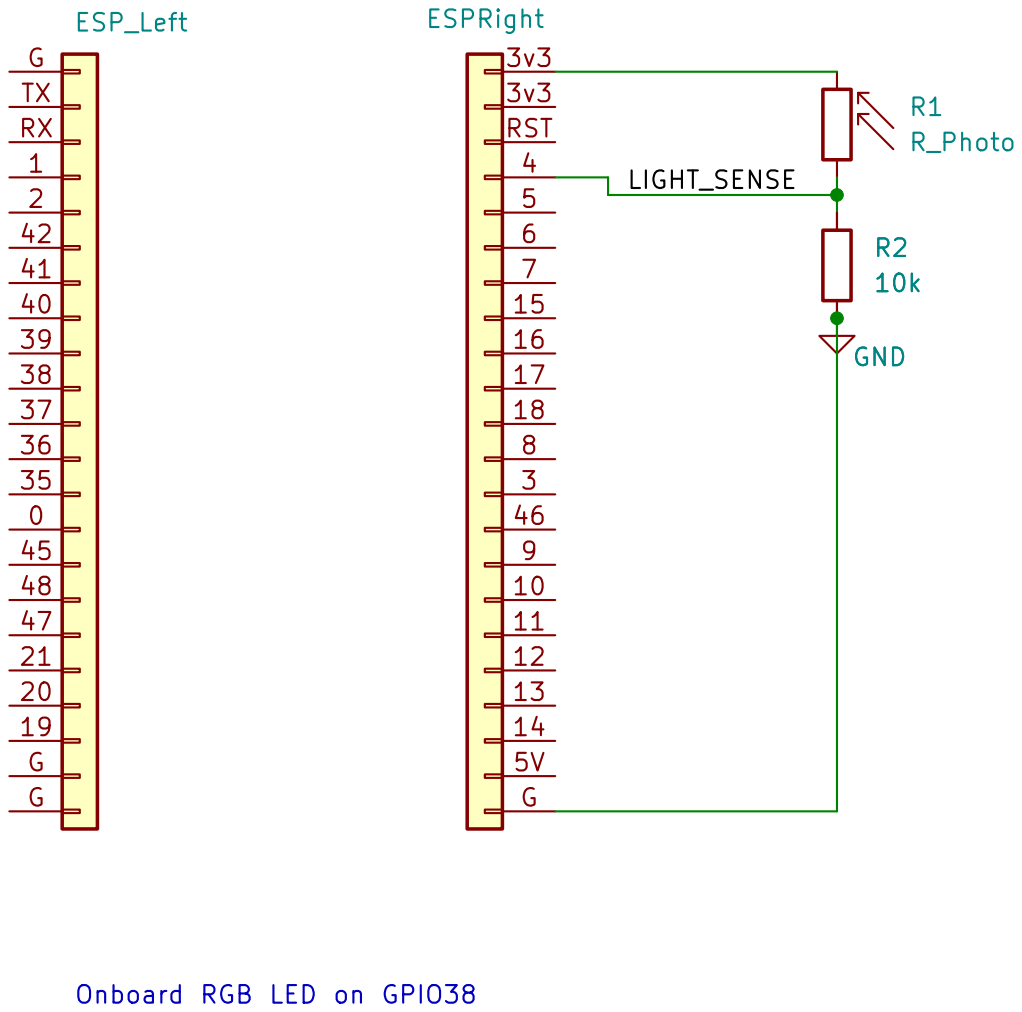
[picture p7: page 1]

Documentation schematic. Reflects Hardware/wiring.md
ESP32-S3-DevKitC-1 + photoresistor divider
Creature Project
Sheet: /
File: Creature.kicad_sch
Title: Creature - Body Node

Size: A4 | Rev: A
KiCad E.D.A. 10.0.3 | Id: 1/1

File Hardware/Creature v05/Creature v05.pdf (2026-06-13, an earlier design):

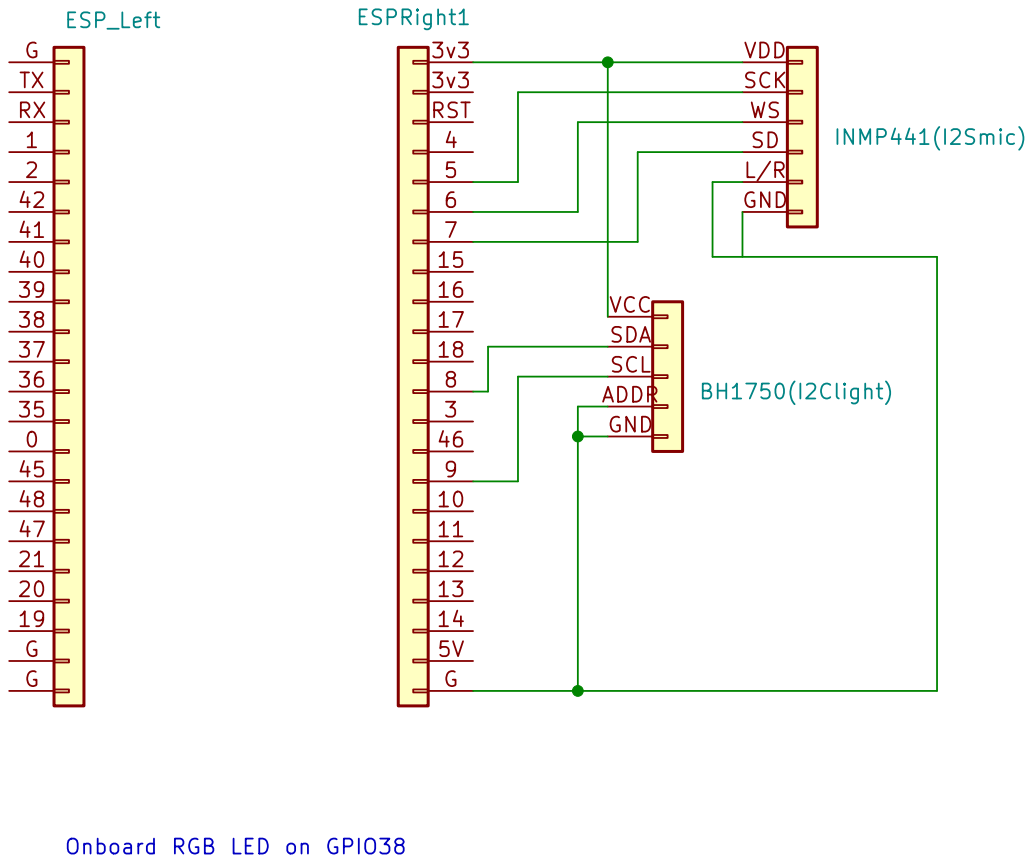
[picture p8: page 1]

Size: A4 | Rev:
KiCad E.D.A. 10.0.3 | Id: 1/1

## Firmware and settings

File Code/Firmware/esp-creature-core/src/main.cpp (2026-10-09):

#include <Arduino.h>
#include <Adafruit_NeoPixel.h>
#include <Wire.h>
#include <BH1750.h>
#include <Adafruit_Sensor.h>
#include <Adafruit_BME280.h>
#include <WiFi.h>
#include <ESPmDNS.h>
#include <driver/i2s.h>
#include <esp_sleep.h>
#include <math.h>
#include <SPI.h>
#include <GxEPD2_BW.h>
#include <Fonts/FreeSansBold9pt7b.h>

#if __has_include("creature_wifi_secrets.h")
#include "creature_wifi_secrets.h"
#endif

// ---------------------------------------------------------------------------
// Creature body node firmware (v07.0: the v06 body plus air sensors, e-paper
// and a battery fuel gauge)
// Board: ESP32-S3-DevKitC-1 style, N16R8 module
//
// Bring-up switches: enable one sensor at a time while the wiring is settled.
//   ENABLE_MIC    1 = read the INMP441 (I2S), stream sound_rms
//   ENABLE_LIGHT  1 = read the BH1750 (I2C), stream light_lux
// A sensor set to 0 is skipped completely: no init, no errors, not in output.
// Turn ENABLE_LIGHT back to 1 once the BH1750 header is soldered.
//
// Streams one JSON line per sample over USB serial and, when WiFi is configured,
// over a small TCP server, for example:
//   {"time_ms":<ms>,"sound_rms":<float>}
// The Raspberry Pi collector normalizes raw values to 0-1.
//
// After each VOX tone it also sends one line saying what the mic heard while the
// tone played, measured at the tone's own pitch:
//   {"vox":{"freq":350.7,"ms":400,"vol":0.75,"heard":..,"level":..,"room":..,"room_heard":..,"n":..}}
//
// A temporary "status" line prints every 2 seconds for bring-up debugging.
// Accepts "LED:<0-255>\n" for the onboard NeoPixel over USB or TCP, mirrored
// to the SK6812 strip as a v06 fallback. The full strip output is PIX:.
//
// Low battery (a reflex of the body, it protects the cell): when the cell stays
// at or under BATTERY_WARN_V the strip's brightness is capped, and at or under
// BATTERY_SLEEP_V the body goes dark, writes a last line to the e-paper and
// deep-sleeps. It wakes every BATTERY_SLEEP_S to read the gauge and stays
// asleep until the cell is charging or back above BATTERY_RESUME_V.
// "BAT:<volts>" is a bench test: for two minutes the reflex acts on that
// voltage instead of the cell's. The streamed battery_v stays the real one.
//
// WiFi is disabled unless CREATURE_WIFI_SSID is defined and non-empty. Keep real
// credentials out of git by creating include/creature_wifi_secrets.h with:
//   #define CREATURE_WIFI_SSID "your-network"
//   #define CREATURE_WIFI_PASSWORD "your-password"
// ---------------------------------------------------------------------------

#define ENABLE_MIC    1   // both sensors on (friction-pin contact until the iron arrives)
#define ENABLE_LIGHT  1
#define ENABLE_MOTION   1   // ICM-20689 IMU (I2C 0x68), stream "motion" scalar
#define ENABLE_WEATHER  1   // BME280 (I2C 0x76), stream "temp_c" and "pressure_hpa"
#define ENABLE_AIR      1   // SCD4x (I2C 0x62) and SGP41 (I2C 0x59), stream "co2_ppm",
                            // "air_temp_c", "humidity_pct", "voc_raw" and "nox_raw"
#define ENABLE_BATTERY  1   // MAX17048 fuel gauge (I2C 0x36), stream "battery_v",
                            // "battery_pct" and "battery_rate"
#define ENABLE_PAPER    1   // Waveshare 2.13inch e-Paper HAT V4 (SPI), EPD: command
#define ENABLE_STRIP    1   // SK6812 RGBW strip (GPIO 4, 16 px), PIX: command
#define ENABLE_VOICE    1   // MAX98357A amp (I2S1 15/16/17), VOX: command
#define ENABLE_BOOT_CHIRP 0  // keep startup quiet; collector sends gentle VOX tones

// Most ESP32-S3 dev boards have a USB-serial activity LED that cannot be
// controlled as a GPIO. If a WiFi collector is connected, stop mirroring the
// 10 Hz JSON stream to USB Serial so that board LED does not blink constantly.
#ifndef QUIET_SERIAL_WHEN_WIFI_CLIENT
#define QUIET_SERIAL_WHEN_WIFI_CLIENT 1
#endif

#ifndef CREATURE_WIFI_SSID
#define CREATURE_WIFI_SSID ""
#endif

#ifndef CREATURE_WIFI_PASSWORD
#define CREATURE_WIFI_PASSWORD ""
#endif

#ifndef CREATURE_WIFI_HOSTNAME
#define CREATURE_WIFI_HOSTNAME "creature-esp"
#endif

#ifndef CREATURE_WIFI_PORT
#define CREATURE_WIFI_PORT 7777
#endif

// ---- Onboard RGB LED (emitter) --------------------------------------------
#define RGB_PIN     38
#define NUM_PIXELS  1
Adafruit_NeoPixel pixel(NUM_PIXELS, RGB_PIN, NEO_GRB + NEO_KHZ800);

// ---- BH1750 ambient light sensor (I2C) ------------------------------------
#define I2C_SDA_PIN 8
#define I2C_SCL_PIN 9
BH1750  lightMeter;
bool    lightReady = false;
uint8_t lightAddr  = 0x00;
int     i2cFoundCount = 0;

// ---- ICM-20689 / MPU-6050-family IMU (I2C 0x68) ---------------------------
#define IMU_ADDR          0x68   // AD0 to GND
#define IMU_REG_WHOAMI    0x75
#define IMU_REG_PWR_MGMT1 0x6B
#define IMU_REG_ACCEL     0x3B   // ACCEL_XOUT_H, 6 bytes follow
bool  imuReady = false;
float lastMotion = 0.0f;

// ---- BME280 weather sensor (I2C 0x76) -------------------------------------
#define BME_ADDR 0x76            // SDO to GND; setup falls back to 0x77
Adafruit_BME280 bme;
bool  bmeReady = false;
float lastTempC = 0.0f;
float lastPressureHpa = 0.0f;

// ---- Air senses: SCD4x CO2 (I2C 0x62) and SGP41 VOC / NOx (I2C 0x59) -------
// Raw readings only. The body reports them; nothing here interprets them.
#define SCD_ADDR 0x62
#define SGP_ADDR 0x59
#define AIR_INTERVAL_MS      1000   // the SGP41 is meant to be read once a second
#define SGP_MEASURE_MS       50     // time the SGP41 needs between command and read
#define SGP_CONDITIONING_S   10     // the datasheet's limit; longer harms the NOx pixel
bool     scdReady = false;
bool     sgpReady = false;
bool     haveCo2 = false;          // false until the SCD4x's first reading (about 5 s)
bool     haveVoc = false;
bool     haveNox = false;          // false through the SGP41's conditioning
uint16_t airCo2Ppm = 0;
float    airTempC = 0.0f;
float    airHumidity = 0.0f;
uint16_t airVocRaw = 0;
uint16_t airNoxRaw = 0;
int      sgpSeconds = 0;
bool     sgpPending = false;       // a command is out, its answer not yet read
bool     sgpPendingConditioning = false;
unsigned long sgpSentMs = 0;
unsigned long lastAirMs = 0;

// ---- Battery: MAX17048 fuel gauge (I2C 0x36) -------------------------------
// The gauge sits in line between the LiPo and the PowerBoost and is powered by
// the cell, so it drops off the bus when the cell is out. Raw readings only.
#define GAUGE_ADDR          0x36
#define GAUGE_REG_VCELL     0x02   // cell voltage, 78.125 uV per count
#define GAUGE_REG_SOC       0x04   // state of charge, 1/256 % per count
#define GAUGE_REG_CRATE     0x16   // charge rate, signed, 0.208 %/hr per count
#define GAUGE_INTERVAL_MS   1000
#define GAUGE_RETRY_MS      10000  // how often to look for a gauge that is missing
// The low-battery reflex acts on cell voltage, not on the gauge's percentage,
// which reached 2 % with four hours of running left (run to flat, 7 October
// 2026). On that run the cell slid slowly down to 3.42 V and then fell off:
// about 55 minutes were left at 3.4 V, 20 at 3.3 V, and nothing stopped it
// until the cell's own protection at about 2.4 V.
#define BATTERY_WARN_V        3.40f  // at or under this, cap the strip
#define BATTERY_WARN_CLEAR_V  3.50f  // back above this, lift the cap
#define BATTERY_SLEEP_V       3.30f  // at or under this, go dark and deep-sleep
#define BATTERY_RESUME_V      3.60f  // asleep: wake for good at or above this
#define BATTERY_CHARGING_RATE 2.0f   // %/hr: above this the cell is on the charger
#define BATTERY_WARN_AFTER_S  10     // seconds the voltage must stay low
#define BATTERY_SLEEP_AFTER_S 30
#define BATTERY_SLEEP_S       300    // deep-sleep time between looks at the gauge
#define BATTERY_VALID_MIN_V   2.0f   // the gauge reads 0 V for its first half minute
#define BATTERY_VALID_MAX_V   4.6f
#define BATTERY_TEST_MS       120000 // how long a BAT: test voltage stands
#define BATTERY_TEST_SLEEP_S  20     // a test sleeps in short steps
#define STRIP_LOW_BATTERY_BRIGHTNESS 12
bool  gaugeReady = false;
bool  haveBattery = false;         // false until a full reading has come back
bool  batteryLow = false;          // the strip cap is on
int   batteryWarnSeconds = 0;
int   batterySleepSeconds = 0;
float batteryTestVolts = 0.0f;     // a BAT: test voltage, 0 when there is none
uint32_t batteryWokeLooks = 0;     // looks at the gauge in the sleep this boot ended
unsigned long batteryTestMs = 0;
// Kept through deep sleep.
RTC_DATA_ATTR bool     batteryAsleep = false;
RTC_DATA_ATTR uint32_t batterySleeps = 0;       // looks at the gauge this sleep
RTC_DATA_ATTR float    batteryRtcTestVolts = 0.0f;
RTC_DATA_ATTR int      batteryRtcTestWakes = 0; // wakes the test voltage still stands for
float batteryVolts = 0.0f;
float batteryPct = 0.0f;
float batteryRate = 0.0f;          // %/hr: positive charging, negative discharging
unsigned long lastGaugeMs = 0;

// ---- e-paper: Waveshare 2.13inch e-Paper HAT V4 (SPI, 250 x 122) -----------
// It shows whatever text the collector sends: two columns of five short lines.
//   EPD:left1;left2;left3;left4;left5|right1;right2;right3;right4;right5
// A redraw takes about half a second, and a full one about four, so the panel
// has a task of its own and the sample loop never waits for it.
// Wiring, in the order of the HAT's own connector, on the ESP's free edge:
//   DIN 1, CLK 2, CS 42, DC 41, RST 40, BUSY 39. VCC to 3V3, GND to GND.
#define EPD_DIN   1
#define EPD_CLK   2
#define EPD_CS    42
#define EPD_DC    41
#define EPD_RST   40
#define EPD_BUSY  39
#define PAPER_LINES          5
#define PAPER_LINE_CHARS     20
#define PAPER_MIN_GAP_MS     60000   // never redraw more often than this
#define PAPER_FULL_EVERY     3     // every Nth redraw is a full one, to clear ghosting
// GxEPD2_213_BN also drives this panel, but its partial refresh left faint grey
// text and heavy ghosting on the V4.
#define EPD_DRIVER GxEPD2_213_GDEY0213B74
GxEPD2_BW<EPD_DRIVER, EPD_DRIVER::HEIGHT>
    paper(EPD_DRIVER(EPD_CS, EPD_DC, EPD_RST, EPD_BUSY));
SemaphoreHandle_t paperLock = NULL;
char paperText[2][PAPER_LINES][PAPER_LINE_CHARS];   // [column][line], guarded by paperLock
volatile bool paperWanted = false;                  // new text is waiting to be drawn
volatile bool paperUrgent = false;                  // draw it now, in full (the last text before sleep)
volatile bool paperUrgentDone = false;
volatile bool paperReportPending = false;           // a redraw finished; tell the collector
volatile bool paperReportFull = false;
volatile unsigned long paperReportMs = 0;

// ---- SK6812 RGBW strip emitter (GPIO 4, 16 px) ----------------------------
#define STRIP_PIN            4
#define STRIP_COUNT          16
#define STRIP_MAX_BRIGHTNESS 40   // current cap on USB/PowerBoost; never all-white
uint8_t stripCap = STRIP_MAX_BRIGHTNESS;   // lowered while the battery is low
Adafruit_NeoPixel strip(STRIP_COUNT, STRIP_PIN, NEO_GRBW + NEO_KHZ800);

// ---- MAX98357A amp emitter (I2S1, GPIO 15/16/17) --------------------------
#define AMP_PORT        I2S_NUM_1
#define AMP_BCLK_PIN    15
#define AMP_LRC_PIN     16
#define AMP_DIN_PIN     17
#define AMP_SAMPLE_RATE 16000
#define TONE_AMP        0.25f     // digital level; for quieter, lower the GAIN pin, not this
float tonePhase = 0.0f;           // continuous phase across tones (no click)

// ---- INMP441 microphone (I2S) ---------------------------------------------
#define I2S_PORT          I2S_NUM_0
#define I2S_SCK_PIN       5      // bit clock   (SCK / BCLK)
#define I2S_WS_PIN        6      // word select (WS / LRCL)
#define I2S_SD_PIN        7      // serial data out from the mic (SD)
#define I2S_SAMPLE_RATE   16000
#define I2S_SAMPLE_COUNT  256
int32_t i2sSamples[I2S_SAMPLE_COUNT];
float   lastSoundRms = 0.0f;
long    micCount = 0;
int32_t micMin = 0;
int32_t micMax = 0;
int32_t micFirst[8];           // first raw samples of the last read, for debug
int     micFirstN = 0;

// ---- Sampling --------------------------------------------------------------
const unsigned long SAMPLE_INTERVAL_MS = 100;   // 10 Hz output
unsigned long lastSampleMs = 0;

const unsigned long STATUS_INTERVAL_MS = 2000;  // temporary diagnostics
unsigned long lastStatusMs = 0;

// ---- Optional WiFi TCP bridge ---------------------------------------------
WiFiServer wifiServer(CREATURE_WIFI_PORT);
WiFiClient wifiClient;
bool wifiEnabled = strlen(CREATURE_WIFI_SSID) > 0;
bool wifiServerStarted = false;
bool mdnsStarted = false;
unsigned long lastWifiAttemptMs = 0;
// On a weak signal a join was measured at 15.7 s (4 October 2026). Retrying
// sooner than that cuts every attempt off before it can finish.
const unsigned long WIFI_RETRY_INTERVAL_MS = 30000;

String serialCommand = "";
String wifiCommand = "";

// Forward declarations
// ---- Hearing its own tone --------------------------------------------------
// A running measurement of mic samples: the plain level, and how much of it
// sits at one pitch.
struct EarSum
{
  double sum = 0.0, sumSq = 0.0;   // level
  double i = 0.0, q = 0.0;         // correlation with the pitch
  double c = 0.0, s = 0.0;         // sums of the reference, to take the mic's DC back out
  long   n = 0;
};

// What playTone listens with while it writes to the amp.
struct ToneListen
{
  float  freq;       // the pitch being played
  long   index;      // mic samples seen since listening began
  long   winStart;   // the stretch of mic samples that is safely inside the tone
  long   winEnd;
  EarSum tone;
};

void  setRgb(uint8_t red, uint8_t green, uint8_t blue);
void  scanI2C();
void  setupLight();
void  setupIMU();
float readMotion();
void  setupBME();
void  readWeather(float& tempC, float& pressureHpa);
void  setupAir();
void  setupPaper();
void  setPaperText(const String& text);
void  reportPaper();
void  serviceAir(unsigned long now);
void  batteryReflex();
void  batteryWakeCheck();
void  setupStrip();
void  stripProof();
void  stripBootIdle();
void  applyLegacyStripBrightness(uint8_t brightness);
void  applyPixels(const String& csv);
void  ampSetup();
void  ampSilence(int ms, ToneListen* listen = NULL);
void  playTone(float freq, int ms, float vol, int attackMs = 10, int releaseMs = 10,
                float h2 = 0.0f, float h3 = 0.0f);
void  setupI2SMic();
float readSoundRms();
void  setupWifi();
void  serviceWifi();
void  readSerialCommands();
void  readWifiCommands();
bool  shouldWriteSerial();
void  writeLineToTransports(const String& line);
void  writeSystemLineToTransports(const String& line);

// ---------------------------------------------------------------------------
void handleCommand(String command, const char* source)
{
  command.trim();

  if (command.startsWith("LED:"))
  {
    int brightness = command.substring(4).toInt();
    brightness = constrain(brightness, 0, 255);

    pixel.setBrightness(brightness);
    setRgb(0, 0, 255);

#if ENABLE_STRIP
    applyLegacyStripBrightness((uint8_t)brightness);
#endif

    String response = "{\"system\":\"led_command_received\",\"source\":\"";
    response += source;
    response += "\",\"brightness\":";
    response += brightness;
#if ENABLE_STRIP
    response += ",\"strip_mirror\":true";
#endif
    response += "}";
    writeSystemLineToTransports(response);
  }
#if ENABLE_STRIP
  else if (command.startsWith("PIX:"))
  {
    applyPixels(command.substring(4));
  }
#endif
#if ENABLE_PAPER
  else if (command.startsWith("EPD:"))
  {
    setPaperText(command.substring(4));
  }
#endif
#if ENABLE_BATTERY
  else if (command.startsWith("BAT:"))
  {
    // Bench test of the low-battery reflex: act on this voltage for two minutes.
    batteryTestVolts = command.substring(4).toFloat();
    batteryTestMs = millis();
    String response = "{\"system\":\"battery_test\",\"volts\":";
    response += String(batteryTestVolts, 2);
    response += "}";
    writeSystemLineToTransports(response);
  }
#endif
#if ENABLE_VOICE
  else if (command.startsWith("VOX:"))
  {
    // VOX:freq,ms[,vol[,attack_ms,release_ms[,h2,h3]]]
    //   freq in Hz, ms duration, vol 0-1. The rest shape the tone and may be
    //   left off: how long it takes to rise and to die away (10 ms each when
    //   not given, the plain beep), and how much of the second and third
    //   overtone is mixed in (0 to 1 each, none when not given).
    String args = command.substring(4);
    float v[7] = {0.0f, 150.0f, 1.0f, 10.0f, 10.0f, 0.0f, 0.0f};
    int start = 0;
    for (int i = 0; i < 7 && start <= (int)args.length(); i++)
    {
      int comma = args.indexOf(',', start);
      String part = (comma >= 0) ? args.substring(start, comma) : args.substring(start);
      part.trim();
      if (part.length() > 0) v[i] = part.toFloat();
      if (comma < 0) break;
      start = comma + 1;
    }
    if (v[0] > 0.0f && v[1] > 0.0f) playTone(v[0], (int)v[1], v[2], (int)v[3], (int)v[4], v[5], v[6]);
  }
#endif
}

void readSerialCommands()
{
  while (Serial.available() > 0)
  {
    char incomingChar = Serial.read();

    if (incomingChar == '\n')
    {
      handleCommand(serialCommand, "serial");
      serialCommand = "";
    }
    else
    {
      serialCommand += incomingChar;
    }
  }
}

void readWifiCommands()
{
  if (!wifiClient || !wifiClient.connected())
  {
    return;
  }

  while (wifiClient.available() > 0)
  {
    char incomingChar = wifiClient.read();

    if (incomingChar == '\n')
    {
      handleCommand(wifiCommand, "wifi");
      wifiCommand = "";
    }
    else
    {
      wifiCommand += incomingChar;
    }
  }
}

void writeLineToTransports(const String& line)
{
  if (shouldWriteSerial())
  {
    Serial.println(line);
  }

  if (wifiClient && wifiClient.connected())
  {
    wifiClient.println(line);
  }
}

void writeSystemLineToTransports(const String& line)
{
  writeLineToTransports(line);
}

bool shouldWriteSerial()
{
#if QUIET_SERIAL_WHEN_WIFI_CLIENT
  return !(wifiEnabled && wifiClient && wifiClient.connected());
#else
  return true;
#endif
}
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
void loop()
{
  unsigned long now = millis();
  serviceWifi();
  readSerialCommands();
  readWifiCommands();
#if ENABLE_AIR
  serviceAir(now);
#endif
#if ENABLE_BATTERY
  serviceGauge(now);
#endif
#if ENABLE_PAPER
  reportPaper();
#endif

  if (now - lastSampleMs < SAMPLE_INTERVAL_MS)
  {
    return;
  }
  lastSampleMs = now;

#if ENABLE_LIGHT
  float lightLux = lightReady ? lightMeter.readLightLevel() : -1.0f;
  if (lightReady && lightLux < 0.0f)
  {
    // Negative means the read failed mid-transfer, almost always a loose
    // contact. Drop to "not ready" so the status block re-inits when it returns.
    lightReady = false;
  }
#endif
#if ENABLE_MIC
  float soundRms = readSoundRms();
#endif
#if ENABLE_MOTION
  float motion = readMotion();
#endif
#if ENABLE_WEATHER
  float tempC = 0.0f, pressureHpa = 0.0f;
  readWeather(tempC, pressureHpa);
#endif

  String sampleLine = "{\"time_ms\":";
  sampleLine += now;
#if ENABLE_LIGHT
  sampleLine += ",\"light_lux\":";
  sampleLine += String(lightLux, 1);
#endif
#if ENABLE_MIC
  sampleLine += ",\"sound_rms\":";
  sampleLine += String(soundRms, 1);
#endif
#if ENABLE_MOTION
  sampleLine += ",\"motion\":";
  sampleLine += String(motion, 4);
#endif
#if ENABLE_WEATHER
  sampleLine += ",\"temp_c\":";
  sampleLine += String(tempC, 2);
  sampleLine += ",\"pressure_hpa\":";
  sampleLine += String(pressureHpa, 1);
#endif
#if ENABLE_AIR
  // Each appears only once its sensor has given a real reading.
  if (haveCo2)
  {
    sampleLine += ",\"co2_ppm\":";
    sampleLine += airCo2Ppm;
    sampleLine += ",\"air_temp_c\":";
    sampleLine += String(airTempC, 2);
    sampleLine += ",\"humidity_pct\":";
    sampleLine += String(airHumidity, 1);
  }
  if (haveVoc)
  {
    sampleLine += ",\"voc_raw\":";
    sampleLine += airVocRaw;
  }
  if (haveNox)
  {
    sampleLine += ",\"nox_raw\":";
    sampleLine += airNoxRaw;
  }
#endif
#if ENABLE_BATTERY
  if (haveBattery)
  {
    sampleLine += ",\"battery_v\":";
    sampleLine += String(batteryVolts, 3);
    sampleLine += ",\"battery_pct\":";
    sampleLine += String(batteryPct, 1);
    sampleLine += ",\"battery_rate\":";
    sampleLine += String(batteryRate, 1);
  }
#endif
  sampleLine += "}";
  writeLineToTransports(sampleLine);

  // ---- STATUS (temporary bring-up diagnostics) -----------------------------
  if (now - lastStatusMs >= STATUS_INTERVAL_MS)
  {
    lastStatusMs = now;

#if ENABLE_LIGHT
    if (!lightReady)
    {
      scanI2C();
      setupLight();
    }
#endif

    String statusLine = "{\"system\":\"status\"";
#if ENABLE_LIGHT
    statusLine += ",\"light_ready\":";
    statusLine += lightReady ? "true" : "false";
    statusLine += ",\"light_addr\":\"0x";
    statusLine += String(lightAddr, HEX);
    statusLine += "\",\"i2c_found\":";
    statusLine += i2cFoundCount;
#endif
#if ENABLE_MIC
    statusLine += ",\"mic_n\":";
    statusLine += micCount;
    statusLine += ",\"mic_min\":";
    statusLine += micMin;
    statusLine += ",\"mic_max\":";
    statusLine += micMax;
    statusLine += ",\"mic_s\":[";
    for (int i = 0; i < micFirstN; i++)
    {
      if (i) statusLine += ",";
      statusLine += micFirst[i];
    }
    statusLine += "]";
#endif
    if (wifiEnabled)
    {
      // Signal strength in dBm, or null while not joined. Around -60 is good,
      // below -85 is too weak to hold a connection.
      statusLine += ",\"wifi_rssi\":";
      if (WiFi.status() == WL_CONNECTED)
      {
        statusLine += WiFi.RSSI();
      }
      else
      {
        statusLine += "null";
      }
    }
    statusLine += "}";
    writeSystemLineToTransports(statusLine);
  }
}

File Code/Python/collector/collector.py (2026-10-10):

"""
Creature collector (v06.1, drives the twelve-cell ring).

Reads the ESP stream (one JSON line per sample, ~10 Hz), normalizes
light and sound to 0-1, and steps the v06 twelve-cell ring once per second.
The LED emitter drives the onboard status pixel, and the v06 expression decoder
sends PIX frames to the SK6812 strip. The database is observation, not memory:
high-volume cell detail is sampled, while structure and sleep summaries are kept
as the longer-lived record.

Run on the Pi:
    cd ~/Creature/Code/Python
    source .venv/bin/activate
    python collector/collector.py /dev/ttyUSB0
    python collector/collector.py tcp://creature-esp.local:7777

ESP stream expected (raw values, normalization happens here):
    {"time_ms":123456,"light_lux":1230.8,"sound_rms":4268.8}
Lines with a "system" key, or without both sensor fields, are ignored.
"""

import atexit
import json
import os
import signal
import socket
import sqlite3
import sys
from datetime import datetime, timedelta
from pathlib import Path
from time import monotonic, sleep

PROJECT_PYTHON_ROOT = Path(__file__).resolve().parents[1]
if str(PROJECT_PYTHON_ROOT) not in sys.path:
    sys.path.insert(0, str(PROJECT_PYTHON_ROOT))

from mind.cell_field_v06 import (
    build_field,
    save_field,
    load_field,
    CELL_COUNT,
    EMITTER_ANCHORS,
    FIELD_VERSION,
    SLOW_MIX,
    SLOW_LEAK,
    SOFT_CEILING,
    CEILING_KNEE,
    BATTERY_CEILING,
    BATTERY_CEILING_CURVE,
)
from mind.expression_v06 import (
    ExpressionDecoderV06,
    lift_white,
    pixels_to_pix_command,
    KNOBS as EXPRESSION_KNOBS,
    voice_command,
    voice_command_from_signal,
    voice_params_from_signal,
)
from mind.expression_memory_v06 import ExpressionMemory
from mind.forward_model_v06 import ForwardModel, frame_rgbw
from mind.curiosity_v06 import Curiosity
from mind.calm_v06 import DarkCalm
from mind.twin_v06 import Twin
from mind.normalize import RollingNormalizer
from mind.gas_index import GasIndex

# --- Serial ---
BAUD = 115200
DEFAULT_PORT = "/dev/ttyUSB0"

# --- WiFi TCP ---
DEFAULT_TCP_PORT = 7777
TCP_CONNECT_TIMEOUT_SECONDS = 5.0
TCP_READ_TIMEOUT_SECONDS = 0.2
TCP_RECONNECT_SECONDS = 2.0
# A body that resets (a flash, a brown-out, a USB plug-in) leaves the old TCP
# connection open but silent. The body streams ten samples a second, so this
# much silence means the link is dead: reconnect instead of waiting for a send
# to time out, which took about four minutes when it happened.
TCP_SILENCE_RECONNECT_SECONDS = float(os.environ.get("CREATURE_ESP_SILENCE_SECONDS", "8"))

# --- Field tick ---
TICK_SECONDS = 1.0          # the field steps once per second (decay/memory assume this)
SAVE_EVERY_TICKS = 100      # persist field state to disk every N ticks
CELL_LOG_EVERY_TICKS = int(os.environ.get("CREATURE_CELL_LOG_EVERY_TICKS", "30"))
WEIGHT_LOG_EVERY_TICKS = int(os.environ.get("CREATURE_WEIGHT_LOG_EVERY_TICKS", "300"))
STATUS_PRINT_EVERY_TICKS = 30  # print a short live status line every N ticks
COMMIT_EVERY_TICKS = 10     # batch SQLite commits: one fsync per N ticks, not per tick
RETENTION_EVERY_TICKS = 3600
RETENTION_ENABLED = os.environ.get("CREATURE_RETENTION_ENABLED", "0") == "1"
TEMPORARY_RETENTION_HOURS = int(os.environ.get("CREATURE_TEMPORARY_RETENTION_HOURS", "12"))
EVENT_RETENTION_DAYS = int(os.environ.get("CREATURE_EVENT_RETENTION_DAYS", "21"))

# --- Normalization (tune live on the Pi while watching the dashboard) ---
# Light is slow and steady, so a short window and light smoothing.
LIGHT_WINDOW_SECONDS = 120.0
LIGHT_EMA_ALPHA = 0.2
LIGHT_MIN_RANGE = 50.0       # lux span below this counts as "no real change"
# Sound is spiky, so a heavier smooth (smaller alpha) and a shorter range window.
SOUND_WINDOW_SECONDS = 20.0
SOUND_EMA_ALPHA = 0.05
SOUND_MIN_RANGE = 500.0      # rms span below this counts as quiet
# Noise gate. The rolling normalizer reports "where is this inside the recent
# range", so in a quiet room it stretches fridge/HVAC hum to fill 0-1 and a
# silent 3 a.m. read came out near 0.13 linear, which the old floor of 0.03
# then passed and the curve boosted to ~0.27. The creature "heard" a quiet dark
# room as moderately loud all night, which kept cells firing, drained the
# energy reserve, and eroded structure. Raising the floor to 0.20 gates the
# ambient median to 0 (89% of overnight ticks read silent in replay) while
# louder transients still pass (evenings still average ~0.06). Gain and
# exponent are unchanged so real events stay reactive. NOTE: this threshold is
# on the floating normalized value, tuned to the current room. The durable fix
# is to also log raw sound_rms so the normalizer can be calibrated against an
# absolute level; see the design doc's open items.
SOUND_RESPONSE_FLOOR = float(os.environ.get("CREATURE_SOUND_RESPONSE_FLOOR", "0.20"))
SOUND_RESPONSE_GAIN = float(os.environ.get("CREATURE_SOUND_RESPONSE_GAIN", "1.25"))
SOUND_RESPONSE_EXPONENT = float(os.environ.get("CREATURE_SOUND_RESPONSE_EXPONENT", "0.65"))

# Motion is spiky and event-like, like sound: a rolling normalizer plus a floor
# to gate the IMU's at-rest jitter, then a response curve for reactivity.
MOTION_WINDOW_SECONDS = 20.0
MOTION_EMA_ALPHA = 0.2
MOTION_MIN_RANGE = 0.05
MOTION_RESPONSE_FLOOR = float(os.environ.get("CREATURE_MOTION_RESPONSE_FLOOR", "0.15"))
MOTION_RESPONSE_GAIN = float(os.environ.get("CREATURE_MOTION_RESPONSE_GAIN", "1.20"))
MOTION_RESPONSE_EXPONENT = float(os.environ.get("CREATURE_MOTION_RESPONSE_EXPONENT", "0.70"))

# Weather is the slow, steady sense. It must stay nonzero (the night floor), so
# it maps an absolute indoor temperature span to 0-1 rather than a position in a
# recent range. Pressure is carried for the record; fold it in later if wanted.
WEATHER_TEMP_MIN = float(os.environ.get("CREATURE_WEATHER_TEMP_MIN", "10.0"))
WEATHER_TEMP_MAX = float(os.environ.get("CREATURE_WEATHER_TEMP_MAX", "35.0"))

# --- LED ---
DEFAULT_LED_MAX_BRIGHTNESS = 80
LED_MAX_BRIGHTNESS = int(os.environ.get("CREATURE_LED_MAX_BRIGHTNESS", DEFAULT_LED_MAX_BRIGHTNESS))
ENABLE_ONBOARD_LED = os.environ.get("CREATURE_ENABLE_ONBOARD_LED", "0") == "1"
ENABLE_STRIP = os.environ.get("CREATURE_ENABLE_STRIP", "1") == "1"
ENABLE_VOICE = os.environ.get("CREATURE_ENABLE_VOICE", "1") == "1"
STRIP_PIXELS = int(os.environ.get("CREATURE_STRIP_PIXELS", "16"))
STRIP_VALUE_CAP = int(os.environ.get("CREATURE_STRIP_VALUE_CAP", "200"))
VOICE_MIN_INTERVAL_SECONDS = float(os.environ.get("CREATURE_VOICE_MIN_INTERVAL_SECONDS", "20.0"))

# --- Expression memory (v06.5 autobiography) ---
# Passive by default: it records what the body expresses and persists across
# runs. It does not change the body output. Set CREATURE_EXPR_MEMORY=0 to skip.
ENABLE_EXPR_MEMORY = os.environ.get("CREATURE_EXPR_MEMORY", "1") == "1"
EXPR_MEMORY_SAVE_EVERY_TICKS = int(os.environ.get("CREATURE_EXPR_MEMORY_SAVE_EVERY_TICKS", "100"))
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

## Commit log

2026-06-13 Initial public release
    [Creature v05.kicad_sch, Creature.kicad_sch]
2026-06-13 v05.4.1: fix overnight energy deadlock and mic noise gate
    [cell_field.py, collector.py]
2026-06-21 Housekeeping: organize docs and wiring by version; ignore renamed Obsidian vault
2026-06-21 v06 hardware design and Phase 2 bench bring-up sketches
    [Creature v06.kicad_sch]
2026-06-21 v06 3.1: stream motion + weather; collector and dashboard track all four senses
2026-06-22 all sensors firmware, expression changes
2026-06-22 expression smoothing, sound problems
    [collector.py, expression_v06.py, main.cpp]
2026-06-27 audio fix update documented
    [main.cpp]
2026-06-28 v06.6: fix sleep never triggering — quiet-pressure threshold was unreachable
    [cell_field_v06.py]
2026-09-20 Add sensor API layer and dashboard sensors panel
2026-09-20 Dashboard: equal-height field and sensors, half-width photo, full-width inspector
2026-09-20 Dashboard: field and inspector side by side, sensors under photo
2026-09-20 Dashboard: show temperature in Fahrenheit too
2026-09-20 Docs: sensor API, PowerBoost cutover; dashboard layout and F
2026-09-23 Docs: MAX17048 wiring (VIN to 3V3, JST pass-through) and rail split note
2026-10-02 v06.7: loop record, forward model, and loop probe
    Start of the predict cycle. Each tick the collector now sets what the body
    emitted (strip frame, any tone) next to the raw senses returned while it was
    on the body, logs the pair to a new loop_log table, and lets a small forward
    model predict its own light and voice, compare, and learn. Passive: nothing
    feeds the field or changes the body. CREATURE_LOOP=0 turns it off.
    - mind/forward_model_v06.py: online delta-rule model on changes, not levels
    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
2026-10-02 Loop probe: judge tones against the room's peaks; record first measurement
    The sound verdict compared the tone with the room's median level, so a noisy
    room read as a faint echo. It now compares with the room's own peak.
    Design doc: first real-body measurement (2 Oct 2026). The light sensor does
    not see the strip; the sound loop was inconclusive.
2026-10-02 v06.8: surprise-based events, and the body hears its own tone
    Events. The old rule put a fixed threshold on raw pressure, which the weather
    anchor's steady pressure crossed on every tick, so sleep replayed the field's
    own background. A tick is now an event when its most surprised cell is 3x more
    surprised than the field's running median and above a small floor. No events
    while asleep or for 30 ticks after waking. A full buffer drops the least
    significant event, not the oldest. EVENT_MODEL=pressure keeps the old rule for
    control runs.
    On 260,000 ticks of recorded senses: events 100% -> 11.9% of ticks, events
    with a real sense change 42% -> 83%, top cell weather -> sound.
    Hearing. playTone r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
    [cell_field_v06.py, collector.py, forward_model_v06.py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]
2026-10-02 Collector: reconnect after 8 s of silence; record first sound-loop measurement
    A body that resets leaves the old TCP connection open but silent, and the
    collector only noticed when a send timed out, about four minutes later. It now
    reconnects after 8 seconds without a sample (CREATURE_ESP_SILENCE_SECONDS).
    TCP only; serial is unchanged.
    Design doc: with the v06.8 firmware flashed, tones near 400 Hz come back at
    11,500 to 16,500 at their own pitch against 200 to 2,000 for the room. The
    sound loop is physically closed.
    [collector.py]
2026-10-02 v06.9: the loop is felt, curiosity, and a voice that is not a metronome
    The loop reaches the field. Each tick the forward model returns how strongly
    the creature just sensed its own voice or light come back, weighted by how
    wrong it was about it, and that presses on the two loop cells. A learned echo
    is felt faintly, a surprising one strongly, and a loop that does not physically
    exist is not felt at all. LOOP_FEEL_GAIN=0 is the control.
    Curiosity. When nothing has surprised the field for a while it probes: a lift
    in the strip's white and, rarely, a short tone at the band of its voice it
    knows least or gets most wrong. Nothing goes out while asleep, no tone while
    muted.
    Voice. The fixed 0.4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
    [cell_field_v06.py, collector.py, curiosity_v06.py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]
2026-10-02 Dashboard: draw the reservoir's real wiring, click a cell to see its connections, bigger ring view
2026-10-02 Dashboard: day mode, with a day / night / auto switch in the menu
2026-10-03 Status doc for v06.9, CLAUDE.md, fake body test tool, fuel gauge wiring note, ignore the Obsidian vault
2026-10-03 Relative expression model (off by default) and the --express gate
    Tempo, arousal and balance can be scaled against the field's own usual
    levels instead of fixed references. Set CREATURE_EXPRESSION_MODEL=relative
    to turn it on; the default stays fixed.
    The --express gate compares the two on a body whose light sensor sees its
    own strip. 8 of 9 checks on seeds 1, 2, 3 and 7: with twice the strip
    light on the sensor the night does not settle.
    [expression_v06.py]
2026-10-03 Two-speed links: slow leak and a ceiling knee, both off by default; the history gate judges learning on the drive's weights and checks that links can still weaken
    [cell_field_v06.py]
2026-10-03 Two-speed links can be switched on from the environment; the collector prints the setting at start
2026-10-04 Air senses: the body reads the SCD4x and SGP41 and streams them raw; the collector passes them to the dashboard's sensor panel
2026-10-04 Gas index for the dashboard: Sensirion's VOC and NOx index worked out on the Pi, its baseline saved; an air_log table and last-hour lines on the sensor panel
2026-10-04 E-paper on the body: the collector sends ten short lines every 180 ticks and the body draws them in a task of its own; the air and e-paper bench test
    [air_epaper_test.cpp, collector.py, main.cpp]
2026-10-06 Battery gauge, step 1: the body reads the MAX17048 and streams voltage, charge and charge rate; the collector logs them to power_log and shows them on the dashboard and the e-paper; the field does no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
2026-10-06 Status doc: the battery gauge is deployed, the Pi runs 0f5b5ec
2026-10-07 Battery, step 2: the charge sets the energy reserve's ceiling (off unless CREATURE_BATTERY_CEILING=1), the energy gate dims the whole strip frame, and the --battery gate
2026-10-07 Status doc: step 2 is deployed, the Pi runs 07c4add with the battery ceiling on
2026-10-07 Battery, step 3: a low-battery reflex on the body, acting on cell voltage: strip cap at 3.40 V, deep sleep at 3.30 V with a look at the gauge every five minutes; gauge readings outside 2.0 to 4.6 V a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
2026-10-07 Battery: the reserve's ceiling follows the cell's smoothed voltage instead of the gauge's percentage (whole at 3.80 V, 43% at 3.60 V, floor at 3.45 V); the --battery gate is in volts with a noisy gau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
2026-10-07 Status doc: the voltage ceiling is deployed, the Pi runs 84264ba
2026-10-07 Status doc: the first real run of the battery chain, from the charger out to the body's sleep at 3.30 V and its wake on the charger
2026-10-07 Strip colour: an inner colour model (CREATURE_COLOUR_MODEL=inner) where the reservoir pushes one hue around the colour wheel, at about a third of the light; the --colour gate; a swatch tool for the r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
2026-10-09 Collector: a probe tone no longer crashes it (a local variable hid the voice_command function)
    [collector.py]
2026-10-09 Status doc: the loop probe of 9 October (the light loop is closed) and the dark-room rule
2026-10-10 Collector: the body's WiFi signal strength is kept, in the live snapshot and in power_log; status doc: the body's dead link on 10 October and the breaks since the v07.0 rebuild
2026-10-10 Dashboard: a Movement view (lean, unrolled ring, an hour of per-cell history kept in the server's memory) and flow dots on the live field's wires
2026-10-10 Status doc: the dashboard's Movement view and flow dots; the body's signal through the morning of 10 October and the bench photo
2026-10-15 Air as weather: mind/air_change.py turns CO2, VOC, air temperature and humidity into the air's change, eased between readings; the collector feeds it as weather with CREATURE_AIR_WEATHER=1, off; fiel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
2026-10-15 Status doc and CLAUDE.md: the air as weather switched on at the Pi on 15 October, ten settings in the start command
